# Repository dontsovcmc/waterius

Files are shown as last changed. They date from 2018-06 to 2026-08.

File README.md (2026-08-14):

# Ватериус 2.0.44
## Wi-Fi приставка для импульсных счётчиков воды, газа, тепла



waterius2-phone_

[Еnglish](https://github.com/dontsovcmc/waterius/blob/master/English.md)

✅ Протоколы HTTP, MQTT

✅ Поддержка <a href="https://yandex.ru/alice/smart-home" targe="_blank">Умного дома Яндекса</a>, <a href="https://www.home-assistant.io/" targe="_blank">HomeAssistant</a>,  <a href="https://www.hackster.io/dontsovcmc/domoticz-4346d5" targe="_blank">Domoticz</a>, <a href="https://spruthub.ru" targe="_blank">SprutHub</a> 

✅ Личный кабинет <a href="https://waterius.ru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" target="_blank">waterius.ru</a>

- автоматическая <a href="https://waterius.ru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" target="_blank">сдача показаний счётчиков</a> в 157 «водоканал» России и СНГ (на сентябрь 2025 г.).
- официальный партнер <a href="https://mos.ru" target="_blank">mos.ru</a>
- отправка на электронную почту
- отправка по СМС 
- телеграм бот

✅ Работает от 3-х батареек АА несколько лет

### Подходит к счётчикам
✅ Все счётчики воды с [импульсным выходом](https://github.com/dontsovcmc/waterius/issues/65) (провод торчит из корпуса)

✅ Все счётчики газа с герконом

✅ Электронные счётчики газа: Бетар СГБМ-4 [подробнее](https://github.com/dontsovcmc/waterius/issues/233)

✅ Электронные счётчики тепла: Sanext Monu CU, Берил ITELMA СТЭ 31 [подробнее](https://github.com/dontsovcmc/waterius/issues/233)

✅ Счётчики электричества: Энергомера CE101, Энергомера ЦЭ6803В 10-100А М7 Р31 и возможно другие импульсные

### Где купить

[waterius.ru](https://waterius.ru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)

### Характеристики
- подключение до двух счётчиков
- 3 АА батарейки (~2-4 года работы)
- передача по Wi-Fi
- не нужно знать, вес импульса у счётчика воды (Ватериус сам определит 1 или 10л/имп)
- не нужно знать, какого типа выход счётчика воды: "сухой контакт" или "НАМУР"
- настраиваемый период отправки
- ручная настройка веса импульса
- дискавери для Home Assistant (есть и интеграция в HAOS)
- возможно указать свои: веб сервер, MQTT брокер, сервер Blynk, NTP сервер
- поддержка SprutHub
- поддержка WirenBoard

#### Данные с Ватериуса можно увидеть:
* на сайте <a href="https://waterius.ru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">waterius.ru</a>
* в Приложении <a href="https://yandex.ru/alice/smart-home">Умный дом с Алисой от Яндекса</a>
* в HomeAssistant [инструкция с пояснениями](Home_Assistant_setup.md), [конфигурация](https://github.com/dontsovcmc/waterius/blob/master/homeassistant.configuration.yaml), [обсуждение](https://github.com/dontsovcmc/waterius/issues/86) или [интеграция](https://github.com/Anat0l/waterius-ha)
* в Domoticz [инструкция](https://www.hackster.io/dontsovcmc/domoticz-4346d5)
* в SprutHub [инструкция](https://wiki.spruthub.ru/%D0%A1%D0%BE%D0%B7%D0%B4%D0%B0%D0%BD%D0%B8%D0%B5_%D0%BA%D0%BE%D0%BD%D1%82%D1%80%D0%BE%D0%BB%D0%BB%D0%B5%D1%80%D0%B0_MQTT)
* на вашем [HTTP/HTTPS сервере](https://github.com/dontsovcmc/waterius/blob/master/Export.md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)
* в MQTT клиенте [описание полей и настройка](https://github.com/dontsovcmc/waterius/blob/master/Export.md#настройка-отправки-по-mqtt)
* там, куда сами запрограммируете
  * [httpwaterius](https://github.com/grffio/httpwaterius) - web сервер с простым UI от [grffio](https://github.com/grffio)
* передать сразу в управляющую компанию через сайт [waterius.ru](https://waterius.ru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).

## Подключение и настройка
[Текстом](http://waterius.ru/manual?utm_source=github)
[Видео](https://www.youtube.com/watch?v=dsmIdWbqJ58)

## Аналоги
[Заводские и DIY](https://github.com/dontsovcmc/waterius/issues/10)

## DIY Сделать самому
[Скачать прошивки](https://github.com/dontsovcmc/waterius/releases)

Народная инструкция в инфо Телеграм чата: [waterius_forum](https://t.me/waterius_forum)
- [Список деталей и создание платы](https://github.com/dontsovcmc/waterius/blob/master/Making.md)
- [Прошивка Attiny85 и ESP](https://github.com/dontsovcmc/waterius/blob/master/Firmware.md) 
- [Установка и настройка](https://github.com/dontsovcmc/waterius/blob/master/Setup.md) 

### Геркон для газового счётчика
Корпус для геркона под газовый счетчик BK-G4T [bk-g4t-sensor.zip](https://github.com/dontsovcmc/waterius/files/10365883/bk-g4t-sensor.zip)

## Принцип работы
Счётчик импульсов состоит из двух микросхем. Attiny85 считает импульсы в режиме сна и сохраняет их в EEPROM. Раз в сутки она будит ESP8266 и слушает i2c линию. ESP8266 спрашивает у Attiny85 данные и отправляет их на сервер. После этого ESP8266 засыпает, а Attiny85 продолжает считать-считать-считать...

### Известные ошибки
- Иногда не надёжно подключается к некоторым роутера Asus, Kineetic. Укажите в настройках Вай-фая ватериуса "only G". 
- До версии 0.11.8: Иногда не подключается к Ростелекомовским роутерам: Sercomm rv6699, Innbox e70, e80 (192.168.0.1), TP-Link AX5400. Лечится указанием статического ip в настройках. Если у вас такие, напишите в теме: [Проблемы с роутерами](https://github.com/dontsovcmc/waterius/issues/131)
- До версии 0.11.7 не подключается к Wi-Fi с пробелом в названии.

## Схема
Заводская плата:
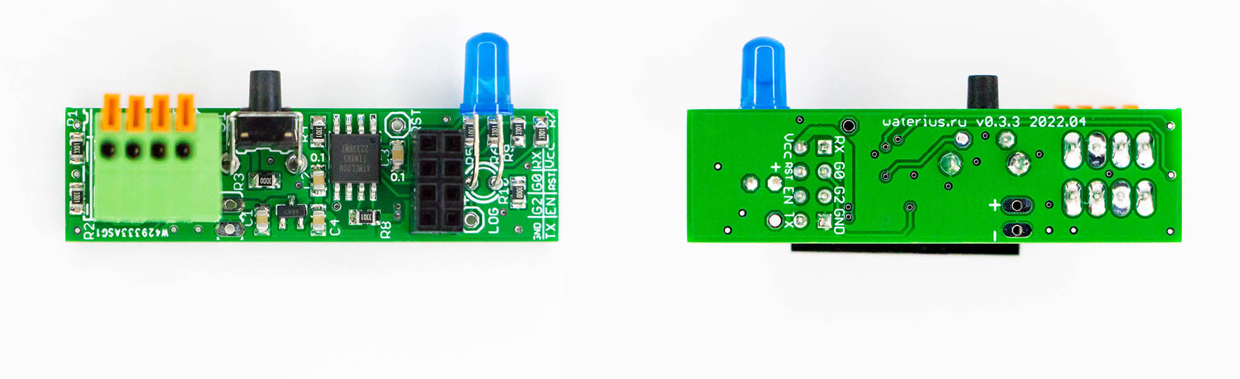
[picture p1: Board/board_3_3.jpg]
плата ватериуса


В репозитории ещё есть однослойная для ЛУТа.

## Разработка 
Ветка dev для pull-request
Ветка master только для публикации прошивок

Из актуальных задач остались сложные:
- Реализовать запись лога в файл (LittleFS), чтобы можно было скачать (/logs.html)
- OTA обновления: предложить код прошивки и пример веб-сервера (можно на базе NodeMCU)

### Модификации
[ветка attiny84](https://github.com/dontsovcmc/waterius/tree/attiny84) поддерживает плату [Waterius-Attiny84-ESP12F](https://github.com/badenbaden/Waterius-Attiny84-ESP12F) с 4мя счетчиками и 2мя датчиками протечек.

[Waterius на ESP32 с NB-IoT](https://github.com/OloloevReal/Waterius32) от OloloevReal

Датчик протечек:
- На пине reset сделал [OloloevReal](https://github.com/OloloevReal), вот [схема](https://github.com/dontsovcmc/waterius/issues/51)
- Есть в клоне [Waterius-Attiny84-ESP12F](https://github.com/badenbaden/Waterius-Attiny84-ESP12F), спасибо [badenbaden]

# Ответственность
Прошивка Ватериуса сделана на основе открытых библиотек, работоспособность которых никто не гарантирует. Я также не могу обещать, что устройство будет работать с вашем оборудованием и вы не получите ущерба как во время изготовления, так и во время эксплуатации устройства =). Пожалуйста, сообщите о любом опыте изготовления и использования [тут](https://github.com/dontsovcmc/waterius/issues). Вы поможете развитию проекта! 
[Лицензия GNU GPLv3](https://github.com/dontsovcmc/waterius/blob/master/LICENSE)

# Благодарности
- [marvel-m9y](https://github.com/marvel-m9y) за поддержку HTTPS
- [OloloevReal](https://github.com/OloloevReal) за датчик протечки, работу по ESP32
- [popsodav](https://github.com/popsodav) за MQTT
- Ивану Коваленко и Иван Ганжа за консультации по электротехнике
- Alex Jensen, за проект [температурного датчика](https://www.cron.dk/esp8266-on-batteries-for-years-part-1).
- [freenetwork](https://github.com/freenetwork) за конфигурацию для HomeAssistant
- [grffio](https://github.com/grffio) за локальный веб-сервер
- [Игорю Вахромееву](http://vakhromeev.com) за наикрутейший редизайн настроек
- Сергею А. (г. Мурманск) за подробную инструкцию по [настройке Domoticz и NodeRed](https://www.hackster.io/dontsovcmc/domoticz-4346d5)
- [sintech](https://github.com/sintech) за найденные и исправленные баги
- [zinger76](https://github.com/zinger76) за ссылку на заказ платы и [3D модель крепления](https://github.com/dontsovcmc/waterius/blob/master/wall-mount/wall_mount.md) к стене
- [badenbaden](https://github.com/badenbaden) за дельные комментарии по производству и новую версию!
- [kick2nick](https://github.com/kick2nick) за доработки функционала.
- [foxel](https://github.com/foxel) за доработку платы.
- Пользователям, приславшим очепятки и предложения: Дмитрию (г. Москва), Сергею (г. Кострома), Александру (г. Санкт-Петербург), Сергею (г. Мурманск), Антону (г. Красноярск) и др.
- Денису С. (г. Москва) за видео установки Ватериуса.
- [ivakorin](https://github.com/ivakorin) за инструкцию к Home Assistant
- Евгению К. из Самары, Олегу из Москвы за критику и помощь с прошивкой
- Олегу К. из Республики Беларусь за [инструкцию к MajorDoMo](https://mjdm.ru/forum/viewtopic.php?p=129000#p129000)
- [Drafteed](https://github.com/Drafteed) за виджет карты России
- [neitri](https://github.com/neitri) за доработки прошивки
- [L2jLiga](https://github.com/L2jLiga) за обновление конфигурации Home Assistant
- nyroux за корпус геркона для газового счётчика
- Anat0liyBM за поддержку discovery HA
- [vzagorovskiy](https://github.com/vzagorovskiy) за большое обновление [0.11.0](https://github.com/dontsovcmc/waterius/releases/tag/0.11.0-beta)
- [abrant-ru](https://github.com/abrant-ru) за поддержку счётчиков с выходом "открытый коллектор" (короткими импульсами)
- Даниилу Макарову за дизайн веб интерфейса
- [videlinagbm](https://github.com/videlinagbm) за верстку веб интерфейса и js код
- [Anat0l](https://github.com/Anat0l/waterius-ha) за написание интеграции в HA

Форумам: 
- https://electronix.ru
- https://esp8266.ru
- https://easyelectronics.ru

## Star History



## Контакты

Связь: [Facebook](https://www.facebook.com/waterius), [VK](https://vk.com/waterius1), [Instagram](https://www.instagram.com/waterius.ru/)

Задавайте вопросы в Телеграм чате: [waterius_forum](https://t.me/waterius_forum)

Найденные ошибки [в issues](https://github.com/dontsovcmc/waterius/issues)

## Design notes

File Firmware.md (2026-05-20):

# Quickstart

Как можно прошить ATtiny & ESP:
1. Взять готовые hex/bin файлы и залить их
2. Скомпилировать исходный код в PlatformIO (CLI или Visual Studio Code)
3. Скомпилировать исходный код в Arduino IDE

---

# Подготовка среды для прошивки (Windows 11)

Для работы вам необходимо подготовить программное обеспечение и установить драйверы для используемых программаторов.

### Установка инструментов через терминал

Запустите **PowerShell** от имени администратора и выполните команды ниже.

#### Одной строкой (все сразу):
```powershell
winget install AVRDudes.AVRDUDE Akeo.Zadig astral-sh.uv Python.Python.3.14; uv tool install esptool
```

#### По отдельности с пояснениями:

*   **AVRDUDE** — утилита для работы с USBasp и контроллерами AVR:
    ```powershell
    winget install AVRDudes.AVRDUDE
    ```
*   **Zadig** — инсталлятор универсальных драйверов для USBasp:
    ```powershell
    winget install Akeo.Zadig
    ```
*   **uv** — быстрый менеджер пакетов для Python:
    ```powershell
    winget install astral-sh.uv
    ```
*   **Python 3.14** — необходимая среда исполнения:
    ```powershell
    winget install Python.Python.3.14
    ```
*   **esptool** — прошивальщик для чипов ESP32 / ESP8266:
    ```powershell
    uv tool install esptool
    ```

---

### 🔌 Установка драйверов (ручной этап)

#### 1. Драйвер для USBasp
После установки **Zadig** через терминал:
1. Подключите **USBasp** к компьютеру.
2. Запустите Zadig.
3. Выберите `Options` → `List All Devices`.
4. В списке выберите `USBasp`.
5. Установите тип драйвера: `libusb-win32`.
6. Нажмите **Replace Driver**.

#### 2. Драйвер для CH340 (USB-Serial)
Для работы с COM-портом скачайте и запустите официальный установщик:
*   🔗 **[Скачать драйвер CH340](https://www.wch-ic.com/download/file?id=270)**

---

### Проверка готовности
*   Для проверки **USBasp** введите: `avrdude -c usbasp -p m328p`
*   Для проверки **CH340** проверьте наличие порта в: `Диспетчер устройств → Порты (COM и LPT)`

---

# Оборудование и схемы подключения

## Чем прошить

#### ATtiny85:
- Программатором USBasp
- Платой Arduino, загрузив в неё скетч Arduino-as-ISP
- Другим программатором для AVR (например, USB-ISP)

#### ESP8266:
- USB-TTL 3.3V переходником
- Платой Arduino, подключившись к её RX, TX + делитель до 3.3V

---

## Фьюзы ATtiny85
**Значения:** `E:FF`, `H:DF`, `L:62`

---

## Распиновка для прошивки ATtiny через разъем ESP

Прошивка ATtiny осуществляется без выпайки её с платы через разъем для ESP (тип разъема: PBD-8).  
**Вид сверху:**

| **GND** | **SCK (15)** | **MOSI (16)** | NC  | 
| ---- | ---- | ---- | ---- |
| NC | **MISO (14)** | NC  | **VCC** |

+ 10-й пин на RESET ATtiny85

**Примечания:**
- **NC** — не используется
- **VCC** — подключить к любому 3.3V или 5V
- От программатора отдельными проводами необходимо подключиться в отверстия PBD-8
- ⚠️ **Не забыть:** отдельно подключить провод к пину RESET

---

## Программаторы для ATtiny

### Утилита Avrdude
- Официальный репозиторий: https://github.com/avrdudes/avrdude
- Альтернативная ссылка: http://www.avislab.com/blog/wp-content/uploads/2012/12/avrdude.zip

### Arduino в качестве ISP программатора (3.3V–5V)

1. Залейте скетч ISP программатора с помощью Arduino IDE в плату Arduino [[инструкция](http://www.martyncurrey.com/arduino-nano-as-an-isp-programmer/)]
2. Подключите плату Arduino к Вотериусу:

**Распиновка при прошивке с помощью Arduino Micro или Arduino UNO:**

| Micro | UNO/NANO | ISP | ATtiny85 | 
| ---- | ---- | ---- | ---- |
| 15 pin | 13 pin | SCK | 7 pin |
| 14 pin | 12 pin | MISO | 6 pin |
| 16 pin | 11 pin | MOSI | 5 pin |
| 10 pin | 10 pin | RESET | 1 pin |

+ Питание!

**Настройки в `platformio.ini`:**
```ini
upload_protocol = arduino
upload_flags = -P$UPLOAD_PORT
upload_speed = 19200
```

### Китайский USB-ISP программатор
- Плата: MX-USBISP-V5.00
- Программа: [ProgISP V1.7.2](https://yandex.ru/search/?text=ProgISP%20V1.7.2&&lr=213)
- Фьюзы: `E:FF`, `H:DF`, `L:62`

### USBasp программатор
Я купил китайский USB-ISP и перепрошил его по [инструкции](https://vochupin.blogspot.com/2016/12/usb-isp.html) в USBasp ([прошивка](https://www.fischl.de/usbasp/)). В диспетчере устройств он стал виден как USBasp.

- Драйвер: [v3.0.7](http://www.myrobot.ru/downloads/programs/usbasp-win-driver-x86-x64-v3.0.7.zip)

**Настройки в `platformio.ini`:**
```ini
upload_protocol = usbasp
upload_flags = 
    -Pusb 
    -B5
```

**Примечание:** в Windows 7 почему-то не заработал. Windows 10 x64 — OK.

---

## Программаторы для ESP8266

Для прошивки ESP8266 необходим USB-TTL преобразователь с логическим уровнем 3.3V. Обратите внимание, что у него должен быть регулятор напряжения для питания ESP8266 на 3.3V. У обычных USB-TTL преобразователей логический уровень 5V, поэтому их вывод TX нужно подключить к делителю напряжения. Я использую резисторы 1.5к и 2.2к.

[Инструкция из интернета](http://cordobo.com/2300-flash-esp8266-01-with-arduino-uno)  
(в большинстве других туториалах подключают 5V логику и делают ESP больно)

#### Драйверы для USB-TTL:
- [CH340G](https://all-arduino.ru/drajver-ch340g-dlya-arduino/)
- [PL2303](http://www.prolific.com.tw/US/ShowProduct.aspx?p_id=225&pcid=41)

---

# Прошивка готовыми бинарными файлами

Готовые прошивки доступны [на странице releases](https://github.com/dontsovcmc/waterius/releases).

## Прошивка ATtiny85 с помощью Avrdude & USBasp

1. **Установка Avrdude:**
   - Скачать: http://download.savannah.gnu.org/releases/avrdude/avrdude-6.2-mingw32.zip
   - **Для Windows 11:** открыть командную строку или PowerShell и выполнить:
     ```powershell
     winget install AVRDudes.AVRDUDE
     ```

2. Распакуйте архив, зайдите в папку. Откройте консоль: `Shift` + правая кнопка мыши → **Открыть окно команд**.

3. Скачайте прошивку ATtiny85:
   ```bash
   curl https://raw.githubusercontent.com/dontsovcmc/waterius_firmware/master/0.5/attiny85.hex --output ./attiny85.hex
   ```
   Если нет `curl`, то откройте ссылку в браузере и скопируйте файл в папку Avrdude.

4. Установите драйвер программатора [USBasp](http://www.myrobot.ru/downloads/driver-usbasp-v-2.0-usb-isp-windows-7-8-10-xp.php) и подключите его к ATtiny85.

5. Установите фьюзы:
   ```bash
   avrdude.exe -p t85 -c Usbasp -B 4 -P usb -U efuse:w:0xFF:m -U hfuse:w:0xDF:m -U lfuse:w:0x62:m
   ```

6. Прошейте микроконтроллер:
   ```bash
   avrdude.exe -p t85 -c Usbasp -B 4 -P usb -U flash:w:"D:\firmware.hex":a
   ```
   где `D:\firmware.hex` — путь до вашего файла.

---

## Прошивка ESP8266

Программатор не нужен, а нужен переходник с USB на TTL 3.3V.

1. Установите Python 3.8 (2.7 тоже подойдёт, только пути для PATH другие).
   
   **Windows:** добавьте в PATH:
   ```
   C:\Users\Админ\AppData\Local\Programs\Python\Python38-32
   ```

2. Скачайте pip. Выполните `python get-pip.py` — Python установит утилиту pip.
   
   Добавьте в PATH:
   ```
   C:\Users\Админ\AppData\Local\Programs\Python\Python38-32\Scripts
   ```

3. Установите esptool:
   ```bash
   pip install esptool
   ```

4. Скачайте [прошивку ESP8266](https://github.com/dontsovcmc/waterius/releases) (файл `esp8266.bin`).

5. Подключите USB-TTL к ESP8266, замкнув **GPIO0** на **GND**.

6. Выполните прошивку:
   ```bash
   python -m esptool --port COM7 --baud 115200 write_flash --flash_freq 40m --flash_size 1MB --flash_mode qio 0x0 esp8266-1.0.2.bin 0xbb000 esp8266-1.0.2-fs.bin
   ```
   
   **COM7** замените на свой порт.

<details>
 <summary>output log (esptool 2.5.0)</summary>

```
esptool.py v2.5.0
Serial port COM7
Connecting........_____.....____
Detecting chip type... ESP8266
Chip is ESP8266EX
Features: WiFi
MAC: 68:c6:3a:a4:75:b0
Uploading stub...
Running stub...
Stub running...
Configuring flash size...
Flash params set to 0x0220
Compressed 359840 bytes to 253754...
Wrote 359840 bytes (253754 compressed) at 0x00000000 in 23.1 seconds (effective 124.8 kbit/s)...
Hash of data verified.

Leaving...
Verifying just-written flash...
(This option is deprecated, flash contents are now always read back after flashing.)
Flash params set to 0x0220
Verifying 0x57da0 (359840) bytes @ 0x00000000 in flash against esp.bin...
-- verify OK (digest matched)
Hard resetting via RTS pin...
```
</details>

Очистить конфигурацию можно вместе с памятью:
```bash
python -m esptool --chip esp8266 --port COM3 --after no_reset erase_flash
```

---

# Прошивка через PlatformIO

### Установка PlatformIO

PlatformIO бывает в виде консольной утилиты или как дополнение в Visual Studio Code.

- [Инструкция по установке утилиты](http://docs.platformio.org/en/latest/installation.html#python-package-manager)
- [Инструкция из интернета](https://medium.com/jungletronics/attiny85-easy-flashing-through-arduino-b5f896c48189)

У нас ATtiny85 уже сидит на плате, поэтому подключаемся к разъему.

После установки в командной строке можно вызывать `platformio --version` и увидеть версию PlatformIO.

### Прошивка ATtiny

1. Откройте в командной строке папку `waterius/Attiny85`
2. Измените в файле `platformio.ini` порт на свой:
   ```ini
   upload_port = /dev/tty.usbmodem1421
   ```
3. Выполните:
   ```bash
   platformio run --target upload
   ```

### Прошивка ESP8266

1. Откройте в командной строке папку `waterius/ESP8266`
2. Измените в файле `platformio.ini` порт на свой:
   ```ini
   upload_port = /dev/tty.usbmodem1411
   ```
3. Прошейте сначала файл прошивки:
   ```bash
   platformio run --target upload --environment esp01_1m
   ```
4. Затем прошейте файловую систему:
   ```bash
   platformio run --target uploadfs --environment esp01_1m
   ```

---

# Прошивка с помощью Arduino IDE

## ATtiny

1. Установить [поддержку ATtiny плат](https://github.com/SpenceKonde/ATTinyCore/blob/master/Installation.md)
2. Выбрать **1 MHz internal**
3. В `/attiny/src` переименовать `main.cpp` в `src.ino`
4. Открыть `src.ino` в Arduino IDE
5. Компилировать

## ESP8266

### Требуемые библиотеки

* Blynk by Volodymyr Shymanskyy (0.6.1)
* ArduinoJSON (6.12.0)
* PubSubClient (2.7.0)
* Установить вручную из zip [WiFiManager#waterius_release_101](https://github.com/dontsovcmc/WiFiManager/tree/waterius_release_101)

**Примечание:** актуальные версии в [platformio.ini](https://github.com/dontsovcmc/waterius/blob/master/ESP8266/platformio.ini)

### Настройка Arduino IDE для ESP8266

**Additional Boards Managers URLs:**
```
http://arduino.esp8266.com/stable/package_esp8266com_index.json
```

**Board settings:**
* **Board:** Generic ESP8266 Module
* **Flash Mode:** QIO
* **Flash Size:** 1M (no SPIFFS)
* **Debug port:** Disable
* **Debug Level:** None
* **lwIP Variant:** v2 Lower Memory
* **Reset Method:** ck
* **Crystal Frequency:** 26 MHz
* **Flash Frequency:** 40MHz
* **CPU Frequency:** 80 MHz
* **Built-in Led:** 0
* **Upload Speed:** 115200
* **Port:** select your port

---

# FAQ

<details>
<summary>1. Лог прошитой ESP без подключения к ватериусу</summary>

```
pio device monitor --port /dev/cu.wchusbserial1410 --baud 115200
--- Miniterm on /dev/cu.wchusbserial1410  115200,8,N,1 ---
--- Quit: Ctrl+C | Menu: Ctrl+T | Help: Ctrl+T followed by Ctrl+H ---
;l␀d|␀$|␃␄␌␄␌$␄c|ǃ␂␛{c␄co'lno␌b␜x$c␇l{lxn␘␃␌␌␌d␌␌␄␌c␄g|␃l␌␄c'o␀$l`␃␛␓no␄$`␃␏␃'{o␄␄c␄␏l␇s'␄␌c␌␇d␃␃$l␒$`␃'␂000:00:00:00:396  NOTICE    (ESP) : Booted
000:00:00:00:397  ERROR     (I2C) : end error:2
000:00:00:00:397  ERROR     (I2C) : get mode failed. Check i2c line.
000:00:00:00:400  NOTICE    (ESP) : Going to sleep
000:00:00:00:404  ERROR     (I2C) : end error:2
```

ЕSP включается, запрашивает режим включения у ATtiny, нет ответа, идёт спать.
</details>

<details>
<summary>2. Проверка без ESP, что ATtiny прошилась</summary>

- Замыкаете на разъеме ESP выводы TX и EN.
- Жмёте кнопку 1 сек, отпускаете
- Проверяете, что загорелся светодиод — ATtiny прошита корректно
</details>

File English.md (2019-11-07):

### Get water meter data sent to your mobile phone using Wi-Fi (powered by AA batteries). 

# Waterius 

Full article on [Hackster.io](https://www.hackster.io/dontsovcmc/waterius-4bfaba)

### Waterius can sends:
- current values everyday
- delta values (per day)
- voltage
- e-mail by Blynk (title and message template)
- data to your TCP server
- low voltage detector (experimental)

Values saved in ATtiny EEPROM cycle buffer (~2 millions cycles). "Software ESD protection".

### How It Works
*Two chips*: ATtiny85 in deep sleep mode. It counts impulses and wakes up ESP-01 to transfer data to Blynk every day. Chips talks by i2c line.

*Power*: 3*AA batteries (or 2*AA lithium batteries without voltage regulator)

*Current*: 15-24 uA in deep sleep, 75 mA when transmitting for ~5 sec

*Lifetime*: estimated 4 year battery life

*Limits*: 1 impulse per second (increased by constant in code)

*Inputs*: 2 water meters

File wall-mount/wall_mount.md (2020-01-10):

# Вариант крепления ватериуса к стене
Модель для 3D печати [STL](https://github.com/dontsovcmc/waterius/blob/master/wall-mount/waterius-wall-mount-v31_.stl), файл 
[SolidWorks SLDPRT](https://github.com/dontsovcmc/waterius/blob/master/wall-mount/waterius-wall-mount-v31.SLDPRT)

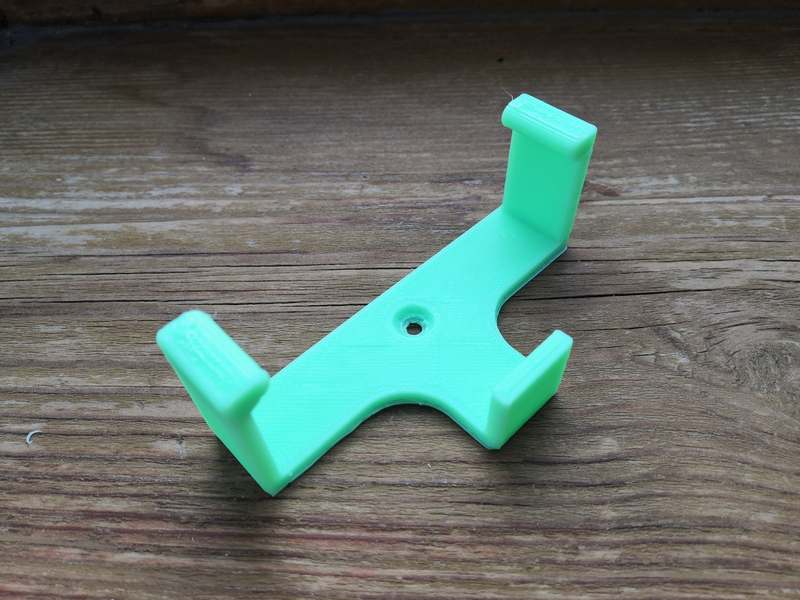
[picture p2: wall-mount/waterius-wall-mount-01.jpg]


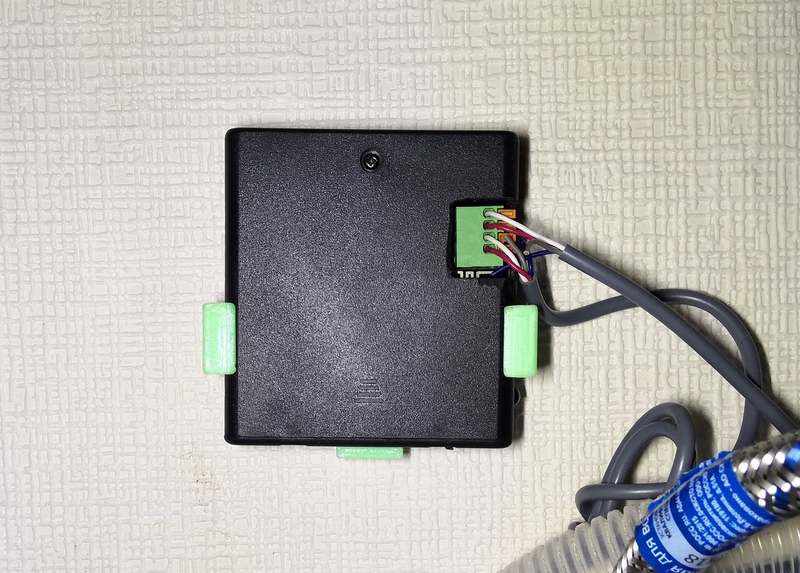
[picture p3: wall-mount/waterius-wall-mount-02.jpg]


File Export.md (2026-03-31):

Ватериус поддерживает отправку в
- сайт <a href="https://waterius.ru" target="_blank">waterius.ru</a>
- в Home Assistant по MQTT
- в WirenBoard по MQTT
- MQTT
- HTTP

Отправка в MQTT и HTTP происходит при каждом пробуждении устройства.

# Список параметров
В таблице собрана информация об отправляемых данных. В столбцах HTTP, MQTT указано, отправляются ли данные по соответствующему протоколу.

Вход 0 - Синий
Вход 1 - Красный

| Поле | Размерность | Тип | Описание | HTTP | MQTT | С версии | 
| --- | --- | --- | --- | --- | --- | --- |
| adc0 | - | uint | Аналоговый уровень входа 0 | + | + | - |
| adc1 | - | uint | Аналоговый уровень входа 1 | + | + | - |
| boot | - | uint | Причина загрузки attiny85 | + | + | - |
| battery | - | int | % заряда батарейки (фейковый) | + | + | - |
| ch0 | м3 | float | Показания воды, вход 0 | + | + | - |
| ch1 | м3 | float | Показания воды, вход 1 | + | + | - |
| ch0_start | м3 | float | Начальные показания воды, вход 0 | + | + | - |
| ch1_start | м3 | float | Начальные показания воды, вход 1 | + | + | - |
| channel | - | int | Канал wi-fi роутера | + | + | - |
| cname0 | - | uint | Тип счётчика, вход 0 | + | + | - |
| cname1 | - | uint | Тип счётчика, вход 1 | + | + | - |
| ctype0 | - | uint | Тип входа attiny, вход 0 | + | + | - |
| ctype1 | - | uint | Тип входа attiny, вход 1 | + | + | - |
| data_type0 | - | uint | Тип данных, вход 0 | + | + | - |
| data_type1 | - | uint | Тип данных, вход 1 | + | + | - |
| dhcp | - | bool | DHCP включен | + | + | - |
| delta0 | литр | uint | Разница с предыдущими показаниями, вход 0 (гор. вода) | + | + | - | 
| delta1 | литр | uint | Разница с предыдущими показаниями, вход 1 (хол. вода) | + | + | - | 
| email | - | str | Электронная почта | + | + | - |
| esp_id | - | int | Серийный номер ESP | + | + | - |
| f0 | - | uint | Вес импульса, вход 0 | + | + | - |
| f1 | - | uint | Вес импульса, вход 1 | + | + | - |
| flash_id | - | int | ID флеш-чипа ESP | + | + | - |
| freemem | - | int | свободная память в ESP, байт | + | + | - |
| imp0 | шт | uint | Количество импульсов | + | + | V0 | 
| imp1 | шт | uint | Количество импульсов | + | + | V1 | 
| ip | - | str | ip адрес локальный ESP (Х.Х.Х.Х) | + | + | - |
| ha | - | bool | флаг HA дискавери включен | + | + | - |
| http | - | bool | HTTP отправка включена | + | + | - |
| key | - | str | Уникальный токен | + | - | - |
| mac | - | str | MAC адрес ESP (ХХ:ХХ:ХХ:ХХ:ХХ:ХХ) | + | + | - |
| mode | - | int | Режим пробуждения 2-авто, 3-по кнопке | + | + | - |
| model | - | uint | Модель устройства (0-Classic, 2-Waterius 2) | + | + | - |
| mqtt | - | bool | брокер mqtt заполнен | + | + | - |
| mqtt_retain | - | bool | MQTT retain включен | + | + | - |
| ntp_errors | шт | uint | Ошибки синхронизации времени NTP | + | + | - |
| ota_error | - | int | Код ошибки OTA обновления (0-4) | + | + | - |
| period_min | минуты | uint | Период пробуждения | + | + | - |
| period_min_tuned | минуты | float | Скорректированный период пробуждения | + | + | - |
| resets | шт | uint | Количество перезагрузок | + | + | V5 |
| router_mac | - | str | MAC адрес производителя роутера (ХХ:ХХ:ХХ:00:00:00) | + | + | - |
| rssi | dBm | int | Уровень Wi-Fi сигнала | + | + | V8 |
| setup_finished | - | int | число успешных подключений к роутеру после настройки | + | + | - |
| setup_started | - | int | число включений режима настройки | + | + | - |
| setuptime | мсек | int | Длительность режима настройки | + | + | - |
| serial0 | - | str | Серийный номер, вход 0 | + | + | - |
| serial1 | - | str | Серийный номер, вход 1 | + | + | - |
| timestamp | - | str | Текущая дата и время 2019-11-29T23:29:55+0800 | + | + | - |
| version | - | int | Версия прошивки attiny85 | + | + | - |
| version_esp | - | str | Версия прошивки esp | + | + | - |
| voltage | В | float | Напряжение питания attiny85 | + | + | - |
| voltage_diff | мВ | int | Просадка напряжения за время подключения Wi-Fi | + | + | - |
| voltage_calibration | % | uint8 | Калибровка напряжения, только Waterius 2 (по умолчанию 100) | + | + | - |
| voltage_low | 0 или 1 | int | voltage_diff выше 50мВ  | + | + | - |
| waketime | мсек | int | Время работы ESP при предыдущем включении | + | + | - |
| wifi_phy_mode | - | str | Текущий режим Wi-Fi | + | + | - |
| wifi_phy_mode_s | - | str | Режим Wi-Fi из настроек | + | + | - |
| wifi_connect_attempt | шт | uint | Попытки подключения к WiFi | + | + | - |
| wifi_connect_errors | шт | uint | Ошибки подключения к WiFi | + | + | - |
| company | - | str(20) | ИНН организации-установщика | + | + | 1.1.5 |
| place | - | str(20) | Место установки | + | + | 1.1.5 |

#### cnameX
| Тип счетчика | Описание |
| --- | --- |
| 0 | Холодная вода |
| 1 | Горячая вода |
| 2 | Электричество |
| 3 | Газ |
| 4 | Тепло |
| 5 | Питьевая вода |
| 6 | Другой |

#### data_typeX
| Тип данных | Описание |
| --- | --- |
| 0 | Холодная вода |
| 1 | Горячая вода |
| 2 | Электричество |
| 3 | Газ |
| 4 | Тепло |
| 9 | Питьевая вода |
| 10 | Другой |

#### ctypeX
| Тип чтения | Описание | Описание |
| --- | --- | --- |
| 0 | Намур | Для механических счетчиков |
| 1 | Дискретный | Для механических счетчиков (убрал) |
| 2 | Электронный | Для электронных счетчиков |

# Настройка отправки на сайт waterius.ru
Зарегистрируйтесь на сайте waterius.ru по адресу электронной почты.
Заполните в режиме настройки:
| Поле | Описание | Пример | Обязательно |
| --- | --- | --- | --- |
| Электронная почта с сайта waterius.ru | Указанная при регистрации почта | user@mail.ru | + |

Ватериус появится в личном кабинете при отправке показаний.

# Настройка отправки в Home Assistant по MQTT 

Заполненное поле "Адрес сервера" включает отправку по протоколу MQTT.
Для подключения нескольких ватериусов укажите им разные топики.
Обязательно включить параметр "retained" на брокере. 
Данные отправляются с retain=true

С версии 0.11.0: По умолчанию данные прилетят в виде JSON (при включенном параметре discovery) в топик. (Например: "waterius/12380568/")

```
{"delta0":0,"delta1":0,"ch0":338.304,"ch1":535.966,"imp0":79,"imp1":109,"f0":10,"f1":10,"adc0":113,"adc1":114,"serial0":"","serial1":"","ctype0":0,"ctype1":0,"cname0":1,"cname1":0,"data_type0":1,"data_type1":0,"voltage":3.128,"voltage_low":true,"voltage_diff":0.21,"battery":0,"channel":12,"router_mac":"AA:AA:AA:00:00:00","rssi":-70,"mac":"AA:AA:AA:AA:AA:AA","ip":"172.16.64.50","dhcp":true,"version":31,"version_esp":"0.11.9","model":0,"esp_id":8686250,"flash_id":1458400,"freemem":37504,"timestamp":"2023-10-22T17:01:10+0000","waketime":10829,"period_min":1440,"period_min_tuned":1440,"setuptime":91781,"boot":1,"resets":1,"mode":3,"setup_finished":4,"setup_started":5,"ntp_errors":0,"wifi_connect_errors":0,"wifi_connect_attempt":1,"ota_error":0,"key":"AA","email":"AA@ya.ru","mqtt":true,"http":false,"ha":false,"mqtt_retain":true}
```
Если параметр discovery выключен или версия прошивки <0.11.0, то данные отправятся в виде отдельных топиков:
```
waterius/12380568/version_esp 0.10.0
waterius/12380568/version 13
waterius/12380568/ch0 0.100
waterius/12380568/ch1 11.200
waterius/12380568/f0 10
waterius/12380568/resets 7
waterius/12380568/rssi -69
и т.д.
```

Заполните в режиме настройки:
| Поле | Описание | Пример | Обязательно |
| --- | --- | --- | --- |
| Адрес сервера | ip адрес брокера или домен | 192.168.1.10, broker.hivemq.com | + |
| Порт | порт брокера | 1883 | + |
| Логин | логин для авторизированного доступа | username | - |
| Пароль | пароль для авторизированного доступа | secret | - |
| Топик | топик по которому будут отсылаться данные | waterius/123456/ | + |
| discovery | обязателен, чтобы работал discovery  | - | + |
| Топик для discovery | топик по которому будут отсылаться данные | homeassistant | + |

С версии 0.11.0 доступно менять параметр period_min, c 0.11.9 и некоторые другие.

| параметр | топик для записи | тип данных | пример топика | пример данных | версия |
|---|---|---|---|---|---|
| period_min | <топик из настроек>/period_min/set | целое число | waterius/124121251/period_min/set | 60 | >=0.11.0  |
| f0 | <топик из настроек>/f0/set | целое число | waterius/124121251/f0/set | 10 | >=0.11.9  |
| f1 | <топик из настроек>/f1/set | целое число | waterius/124121251/f1/set | 10 | >=0.11.9  |
| ch0 | <топик из настроек>/ch0/set | дробное число | waterius/124121251/ch0/set | 121.4 | >=0.11.9  |
| ch1 | <топик из настроек>/ch1/set | дробное число | waterius/124121251/ch1/set | 151.53 | >=0.11.9  |
| cname0 | <топик из настроек>/cname0/set | целое число | waterius/124121251/cname0/set | 0 | >=1.0.2 |
| cname1 | <топик из настроек>/cname1/set | целое число | waterius/124121251/cname1/set | 0 | >=1.0.2 |
| ctype0 | <топик из настроек>/ctype0/set | целое число | waterius/124121251/ctype0/set | 0 | >=1.0.2 |
| ctype1 | <топик из настроек>/ctype1/set | целое число | waterius/124121251/ctype1/set | 0 | >=1.0.2 |
| voltage_calibration | <топик из настроек>/voltage_calibration/set | целое число (только Waterius 2) | waterius/124121251/voltage_calibration/set | 100 | >=2.0.34 |

Примечание: значения ctype0, ctype1 указано выше в разделе ctypeX
Примечание: значения cname0, cname1 указано выше в разделе cnameX

# Настройка отправки в WirenBoard по MQTT 

Выполните настройки MQTT как для отправки в Home Assistant.

Загрузите скрипт waterius_wirenboard.js
 в WirenBoard и измените в нём topic.

# Настройка отправки по HTTP (свой сервер)

Заполните в режиме настройки:
| Поле | Описание | Пример | Обязательно |
| --- | --- | --- | --- |
| Адрес сервера | ip адрес сервера или домен (```http[s]://host[:port][/path]```) | 192.168.1.10, http://mysite.ru, http://mysite.ru:1000/data | + |

Если "Адрес сервера" пустой, отправка по HTTP выключена.

Ватериус отправляет POST запрос с данными в виде JSON.

<a href="https://github.com/dontsovcmc/waterius/wiki/%D0%9F%D1%80%D0%B8%D0%BC%D0%B5%D1%80-%D0%B2%D0%B5%D0%B1%D1%81%D0%B5%D1%80%D0%B2%D0%B5%D1%80%D0%B0">Пример вебсервера</a>

## Поддержка HTTPS 

Добавлена библиотека BearSSL с поддержкой TLS 1.2 шифрования.
Если ваш сервер https, то требуется пересобрать прошивку с вашим сертификатом удостоверящего центра. Инструкция по созданию сертификатов в [Python скрипте]. У сертификатов есть срок действия.

# Проекты сообщества
* [httpwaterius](https://github.com/grffio/httpwaterius) - web сервер с простым UI от [grffio](https://github.com/grffio)

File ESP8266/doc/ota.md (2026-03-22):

# OTA обновление прошивки Waterius

OTA (Over-The-Air) позволяет обновлять прошивку и файловую систему Waterius удалённо, без физического подключения по USB.

**Поддерживаемые модели:** только Waterius-2 (MODEL_2, ESP-12F, flash 4MB).
ESP-01 (1MB flash) не поддерживает OTA — недостаточно места для staging area.

## Общая схема работы

```
ESP ──POST данные──> Сервер
ESP <──JSON ответ─── Сервер  (содержит секцию "ota" с url/md5/size файлов)
ESP ──GET──────────> filesystem.bin  (LittleFS, если есть в ota)
ESP ──GET──────────> firmware.bin
ESP ──перезагрузка──> Новая прошивка работает
```

Сервер решает, кому и когда отдавать OTA — ESP просто выполняет команду. Отдельного манифеста нет — OTA-данные передаются прямо в JSON-ответе сервера, что экономит один HTTP-запрос и ~15 КБ RAM.

## Последовательность работы

### 1. Штатный цикл отправки данных

ESP просыпается (по таймеру или кнопке), подключается к WiFi и отправляет показания на сервер. В JSON-запросе всегда есть поле `version_esp` с текущей версией прошивки.

### 2. Сервер отвечает с командой OTA

Если сервер решает что устройству нужно обновление, он включает в ответ секцию `ota`:

```json
{
  "ota": {
    "firmware": {
      "url": "https://cloud.waterius.ru/ota/nodemcuv2-2.0.25.bin",
      "size": 633344,
      "md5": "f14e1220b1565f63a4a69b84cab4582d"
    },
    "filesystem": {
      "url": "https://cloud.waterius.ru/ota/nodemcuv2-2.0.25-fs.bin",
      "size": 1024000,
      "md5": "6c023b5558cc375843449565ff0f2570"
    }
  }
}
```

Если обновление не нужно — пустой ответ `{}`.

Секция `ota` должна содержать хотя бы одну из подсекций (`firmware` или `filesystem`). Каждая подсекция содержит:

| Поле | Описание |
|---|---|
| `url` | Полный HTTPS URL файла |
| `size` | Размер в байтах |
| `md5` | MD5-хеш файла |

### 3. Проверки перед обновлением

**Проверка батареи (3 замера, среднее):**

Перед OTA выполняются 3 измерения напряжения с интервалом 100мс. Пауза между замерами позволяет напряжению стабилизироваться после кратковременных просадок от WiFi-передачи. Среднее из 3 замеров сглаживает шум АЦП ESP8266 (±30-50 мВ).

| Проверка | Порог | Назначение |
|---|---|---|
| Среднее > 4600 мВ | — | USB-питание, проверка пропускается |
| Среднее < 3300 мВ | Абсолютный порог | Минимум для 3×AA (3 × 1.1В) |

Порог 3300 мВ — надёжный минимум для любых типов батарей (Alkaline, NiMH) и АКБ.

**Порог USB-питания — 4600 мВ** (не 4900). Под нагрузкой WiFi напряжение USB проседает до ~4830 мВ. Свежие 3xAA дают до ~4800 мВ, но при WiFi нагрузке падают до ~4700 мВ, что всё ещё > 4600.

**Валидация OTA-данных:**
- Секция `ota` должна быть JSON-объектом
- Должна содержать хотя бы одну подсекцию (`firmware` или `filesystem`)
- Каждая подсекция должна содержать `url` и `md5`

**Проверка MD5:**
- `ESP8266httpUpdate` проверяет MD5 после скачивания, до записи во flash
- Если MD5 не совпадает — файл отбрасывается, старая прошивка не тронута

### 4. Обновление файловой системы

Если в `ota` есть секция `filesystem`:
- Вызывается `extendWakeUp()` — сброс таймера Attiny85 (120 секунд)
- `ESPhttpUpdate.updateFS()` скачивает и записывает LittleFS-образ
- Перезагрузка отключена (`rebootOnUpdate(false)`) — после FS нужно ещё обновить firmware

### 5. Обновление прошивки

Если в `ota` есть секция `firmware`:
- Вызывается `extendWakeUp()`
- `ESPhttpUpdate.update()` скачивает прошивку в staging area
- Перезагрузка отключена — после записи выполняется явная проверка результата

### 6. Перезагрузка и проверка

После успешного обновления всех компонентов:
```
OTA: filesystem updated OK
OTA: firmware updated OK
OTA: complete, restarting ESP...
```
ESP вызывает `ESP.restart()`. Bootloader (eboot) копирует прошивку из staging area в APP-область (~3.8 секунды для 633 КБ).

После перезагрузки ESP проходит обычный цикл: WiFi → NTP → отправка данных. В JSON уже новая `version_esp`. Сервер видит новую версию и отвечает `{}` — OTA больше не запускается. Если OTA завершилось ошибкой, статус ошибки (`ota_error`) передастся серверу при следующем штатном пробуждении.

## Коды ошибок OTA

Код ошибки сохраняется в `Settings.ota_error` (EEPROM). При следующей отправке данных включается в JSON как `ota_error`. После успешной отправки обнуляется.

| Код | Константа | Описание |
|-----|---|---|
| 0 | `OTA_ERR_NONE` | Нет ошибки |
| 1 | `OTA_ERR_PARSE` | Ошибка данных (нет url/md5, пустая секция ota) |
| 2 | `OTA_ERR_FS_UPDATE` | Ошибка обновления filesystem (MD5, обрыв, нет связи и т.д.) |
| 3 | `OTA_ERR_FW_UPDATE` | Ошибка обновления firmware (MD5, обрыв, нет связи и т.д.) |
| 4 | `OTA_ERR_LOW_BATTERY` | Батарея разряжена (напряжение < 3300 мВ) |

Счётчик попыток OTA реализуется на стороне сервера: сервер видит `ota_error` и `version_esp` в каждом запросе и может прекратить отдавать OTA после N ошибок.

## Настройка сервера

### Python Flask (пример)

Минимальный сервер для управления раздачей OTA:

```python
from flask import Flask, request, jsonify

app = Flask(__name__)

OTA_ENABLED = True
OTA_TARGET_VERSION = "2.0.24"  # OTA только для этой версии ("" = для всех)
OTA_CONFIG = {
    "firmware": {
        "url": "https://cloud.waterius.ru/ota/nodemcuv2-2.0.25.bin",
        "size": 637200,
        "md5": "b66e9d1297bc1a170d140aeddc3e15b8"
    },
    "filesystem": {
        "url": "https://cloud.waterius.ru/ota/nodemcuv2-2.0.25-fs.bin",
        "size": 1024000,
        "md5": "6c023b5558cc375843449565ff0f2570"
    }
}

@app.route("/cloud-waterius-ru", methods=["POST"])
def waterius():
    data = request.get_json(silent=True) or {}
    version_esp = data.get("version_esp", "")

    response = {}
    if OTA_ENABLED:
        if OTA_TARGET_VERSION == "" or version_esp == OTA_TARGET_VERSION:
            response["ota"] = OTA_CONFIG

    return jsonify(response)
```

**Параметры:**

| Параметр | Описание |
|---|---|
| `OTA_ENABLED` | `True` — отдавать OTA, `False` — обычный ответ `{}` |
| `OTA_TARGET_VERSION` | Версия ESP для обновления. `"2.0.24"` — только 2.0.24 получит OTA. `""` — все версии |
| `OTA_CONFIG` | Секция `ota` с url/md5/size файлов |

**Защита от зацикливания:** сервер проверяет `version_esp` из POST-данных. Если версия ESP уже обновлена — `ota` не отдаётся.

### Настройка release-сервера

1. Создать директорию для OTA-файлов на сервере (например `/ota/`)
2. Загрузить файлы:
   - `nodemcuv2-X.X.X.bin` (firmware)
   - `nodemcuv2-X.X.X-fs.bin` (filesystem)
3. Убедиться что файлы доступны по HTTPS
4. Указать url/md5/size каждого файла в конфигурации сервера
5. Установить `OTA_TARGET_VERSION` на версию, которую нужно обновить
6. Включить `OTA_ENABLED = True`

### Отключение OTA после обновления

Два способа:
- **Автоматический:** `OTA_TARGET_VERSION = "2.0.24"` — после обновления до 2.0.25 устройство перестанет получать OTA
- **Ручной:** `OTA_ENABLED = False` — полностью отключить OTA для всех

## Сборка OTA-бинарей

### Скрипт сборки

```bash
cd ESP8266
./scripts/build_and_deploy.sh 2.0.25
```

Скрипт выполняет:
1. Временно подменяет `firmware_version` в `platformio.ini` на указанную версию
2. Собирает прошивку: `platformio run --environment waterius_2`
3. Собирает файловую систему: `platformio run --target buildfs --environment waterius_2`
4. Вычисляет MD5 и размеры
5. Копирует бинари в `ota/`
6. Выводит JSON-фрагмент секции `ota` для вставки в конфигурацию сервера
7. Восстанавливает `platformio.ini` (через trap, даже при ошибке)

Результат:
```
ESP8266/ota/
├── nodemcuv2-2.0.25.bin        # firmware (~633 KB)
└── nodemcuv2-2.0.25-fs.bin     # filesystem (~1000 KB)
```

### VSCode Task

В `.vscode/tasks.json` есть задача **OTA: Build and prepare**. При запуске запрашивает версию (по умолчанию 2.0.25).

### Переключение debug / release

В `scripts/build_and_deploy.sh` изменить `OTA_BASE_URL`:

```bash
# Debug
OTA_BASE_URL="https://us.pstd.ru/us-files/waterius"

# Release
OTA_BASE_URL="https://cloud.waterius.ru/ota"
```

### Загрузка на сервер

После сборки загрузить содержимое `ota/` на сервер. Файлы должны быть доступны по HTTPS.

## Тайминги

Реальные замеры на Waterius-2 (ChipId: 682bdb), WiFi 802.11n, HTTPS, сервер us.pstd.ru (2026-03-16):

### Полный цикл с OTA (FS + firmware)

```
00:00  ESP проснулся
00:04  WiFi подключён                         (~3.8с)
00:04  NTP синхронизация                       (~0.05с)
00:05  Отправка данных #1                      (~1.1с)
00:05  Сервер вернул ota
00:06  apply_settings + отправка данных #2     (~1с)
00:06  OTA: start
00:06  Проверка батареи (USB: 4732 mV)         пропущена
00:07  OTA: downloading filesystem...
00:54  OTA: filesystem updated OK              (~47с, 1024 КБ)
00:54  OTA: downloading firmware...
01:28  OTA: firmware updated OK                (~34с, 633 КБ)
01:28  OTA: complete, restarting ESP...
       ──── перезагрузка (eboot ~3.8с) ────
03:50  Новая прошивка стартовала
07:45  Firmware ver: 2.0.25
09:06  Going to sleep
```

### Тайминги по этапам

| Этап | Время | Размер | Скорость |
|---|---|---|---|
| WiFi подключение | ~3.8с | — | — |
| NTP синхронизация | ~0.05с | — | — |
| Отправка данных | ~1.1с | ~900 Б | — |
| Проверка батареи | ~0.2с | — | — |
| Обновление filesystem | ~47с | 1024 КБ | ~22 КБ/с |
| Обновление firmware | ~34с | 633 КБ | ~19 КБ/с |
| Перезагрузка (eboot copy) | ~3.8с | 633 КБ | — |
| **Полный цикл с OTA** | **~88с** | — | — |
| **Штатный цикл без OTA** | **~5-9с** | — | — |

Скорость скачивания ~19-22 КБ/с (HTTPS через WiFi 802.11n). Запас по таймеру Attiny: `extendWakeUp()` даёт 120 секунд, OTA занимает ~82 секунды — резерв ~38 секунд.

## Flash layout (ESP8266, 4MB)

```
┌──────────────────────────────────────┐
│ Bootloader (eboot): 4 KB            │ 0x000000
├──────────────────────────────────────┤
│ APP (текущая прошивка): ~633 KB      │ 0x001000
├──────────────────────────────────────┤
│ Staging area (свободно): ~2.4 MB     │ ← сюда скачивается новая прошивка
├──────────────────────────────────────┤
│ LittleFS: 1 MB                      │ 0x300000
├──────────────────────────────────────┤
│ EEPROM + WiFi config: 20 KB         │ 0x3FB000
└──────────────────────────────────────┘
```

ESP8266 **не имеет** dual-partition OTA (A/B) как ESP32. Используется staging area:

1. `ESP8266httpUpdate` скачивает новую прошивку в staging area
2. MD5 проверяется до записи команды bootloader
3. Если MD5 совпал — записывается команда для eboot в RTC-память
4. ESP перезагружается
5. eboot копирует прошивку из staging area в APP-область
6. Загружается новая прошивка

**Безопасность:**
- Если скачивание прервалось или MD5 не совпал — старая прошивка не тронута
- Единственный риск — сбой питания во время копирования eboot (шаг 5, ~1-2 сек). `extendWakeUp()` гарантирует что Attiny не отключит питание
- Обе копии (текущая + staging) помещаются между bootloader и LittleFS (~3 МБ, при прошивке ~633 КБ запас огромный)

**Обновление LittleFS:**
- `updateFS()` записывает образ напрямую в область LittleFS (0x300000)
- Не использует staging area — прямая запись

## Ограничения и риски

### Нет rollback

Если новая прошивка загрузилась но не работает — откат только через USB. Тестируйте прошивку перед публикацией на сервер.

### Только Waterius-2

OTA компилируется только для `WATERIUS_MODEL == WATERIUS_MODEL_2` (ESP-12F, 4MB flash). На ESP-01 (1MB) не хватает места для staging area.

### Расход батареи

OTA потребляет больше энергии: WiFi активен ~67 секунд вместо обычных ~5-9. Одно обновление не критично для 3xAA батарей, но не стоит запускать OTA часто.

### HTTPS без проверки сертификата

Используется `setInsecure()` (как и во всём проекте). Трафик шифруется, но сертификат сервера не проверяется. Для OTA это допустимо благодаря MD5-проверке содержимого.

### Обновление Attiny85 невозможно

ESP подключён к Attiny85 только по I2C — нет доступа к ISP-пинам. Обновление Attiny только через USB-программатор.

### Настройки после OTA

EEPROM (Settings) сохраняется при OTA — настройки WiFi, показания счётчиков и все пользовательские параметры не теряются. Настройки сбросятся только если в новой прошивке изменилась `CURRENT_VERSION` конфигурации.

## Настройка сервера (WordPress + Code Snippets)

Файл `doc/waterius_ota_snippet.php` — готовый PHP-сниппет для плагина Code Snippets (WordPress).

Установка:
1. Установить плагин Code Snippets на WordPress
2. Создать новый PHP-сниппет, вставить содержимое `waterius_ota_snippet.php`
3. В настройках Waterius (captive portal) указать HTTP URL: `https://your-server.com/cloud-waterius-ru`
4. Для управления OTA менять `$OTA_ENABLED` и `$OTA_TARGET_VERSION` в сниппете

Настройки в сниппете:
- `$OTA_ENABLED` — `true` для раздачи OTA, `false` для отключения
- `$OTA_TARGET_VERSION` — версия ESP для обновления (`''` = все версии)
- `$OTA_CONFIG` — секция `ota` с url/md5/size (генерируется скриптом `build_and_deploy.sh`)

## Структура файлов

```
ESP8266/
├── src/
│   ├── ota_parse.h            # Парсинг OTA JSON (parse_ota_params(), struct OtaParams, коды ошибок)
│   ├── ota_update.h           # Объявление perform_ota_update(), пороги напряжения
│   ├── ota_update.cpp         # Реализация OTA (проверка батареи, скачивание, запись, рестарт)
│   ├── main.cpp               # Вызов OTA после получения секции "ota" от сервера
│   └── json.cpp               # Отправка ota_error в JSON
├── test/
│   └── test_ota/
│       ├── main.cpp                 # Точка входа googletest
│       └── test_url_validation.cpp  # 11 тестов парсинга OTA JSON (native, googletest)
├── scripts/
│   └── build_and_deploy.sh    # Скрипт сборки OTA-бинарей
├── ota/                       # Результат сборки (не в git)
│   ├── nodemcuv2-X.X.X.bin
│   └── nodemcuv2-X.X.X-fs.bin
├── doc/
│   ├── ota.md                 # Этот документ
│   └── waterius_ota_snippet.php  # PHP-сниппет для WordPress Code Snippets
└── plan/
    └── ota_v2_plan.md         # План и результаты тестирования
```

## Запуск тестов

```bash
cd ESP8266
platformio test --environment native
```

11 тестов (googletest) покрывают парсинг OTA JSON:
- Полный OTA (firmware + filesystem), только firmware, только filesystem
- Пустой объект, отсутствующие url/md5, firmware не объект
- Значение size по умолчанию (0), проверка кодов ошибок

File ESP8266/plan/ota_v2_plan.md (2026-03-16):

# План доработки OTA v2

## Что сделано

| # | Задача | Файлы |
|---|---|---|
| 1 | Убрать манифест, парсить OTA из JSON-ответа | ota_update.cpp, ota_update.h, main.cpp |
| 2 | Удалить ota_manifest.h и test_manifest.cpp | ota_manifest.h, test_manifest.cpp |
| 3 | Упростить проверку батареи (только voltage, 3 замера/100мс) | ota_update.cpp, ota_update.h |
| 4 | Перенумеровать коды ошибок (5 вместо 8) | ota_update.h |
| 5 | Обновить скрипт сборки (без manifest.json) | scripts/build_and_deploy.sh |
| 6 | Обновить doc/ota.md | doc/ota.md |
| 7 | Извлечь parse_ota_params() в ota_parse.h, native-тесты | ota_parse.h, ota_update.cpp, test_url_validation.cpp |
| 8 | Обновить PHP-сниппет под OTA v2 | doc/waterius_ota_snippet.php |
| 9 | Тестирование на устройстве | — |

### Ключевые изменения

**Протокол:** `{"update_ota": "url"}` → `{"ota": {"firmware": {...}, "filesystem": {...}}}`. Убран отдельный HTTP-запрос на манифест — экономия ~0.6с и ~15 КБ RAM.

**Проверка батареи:** убрана нестабильная проверка `battery% < 40%`. Вместо этого — 3 измерения напряжения с шагом 100мс, среднее сравнивается с порогом 3300 мВ.

**Коды ошибок:** 0=NONE, 1=PARSE, 2=FS_UPDATE, 3=FW_UPDATE, 4=LOW_BATTERY. Убраны DOWNLOAD, INVALID_URL, TIMEOUT (не используются).

**HTTPS:** оставлен (WiFiClientSecure + setInsecure). Памяти хватает, защита от пассивного перехвата.

**PHP-сниппет:** обновлён под v2 — отдаёт секцию `ota` вместо `update_ota`.

**Native-тесты:** 11 тестов (googletest) для parse_ota_params() — парсинг JSON, валидация полей, коды ошибок.

---

## Результаты тестирования на устройстве

**Дата:** 2026-03-16
**Устройство:** Waterius-2 (ESP-12F, 4MB flash), ChipId: 682bdb
**Питание:** USB (4732 mV)
**WiFi:** ZLINKS, 802.11n, канал 7, RSSI -49 dBm
**Сервер:** WordPress + Code Snippets на us.pstd.ru

### Тест: полный OTA (firmware + filesystem), 2.0.24 → 2.0.25

| Этап | Время | Результат |
|---|---|---|
| WiFi подключение | ~3.8с | OK |
| NTP синхронизация | ~0.05с | OK |
| HTTP POST → сервер вернул `ota` | ~1.1с | OK, JSON с firmware + filesystem |
| Проверка батареи | — | Пропущена (USB: 4732 mV > 4600) |
| Парсинг OTA JSON | мгновенно | OK, url/md5/size распознаны |
| Скачивание filesystem (1024 KB) | ~47с (~22 KB/с) | OK |
| Скачивание firmware (633 KB) | ~34с (~19 KB/с) | OK |
| Перезагрузка (eboot copy) | ~3.8с | OK |
| **Полный цикл OTA** | **~88с** | **OK** |

### Проверено

- Сервер вернул `{"ota": {"firmware": {...}, "filesystem": {...}}}` — ESP распарсил корректно
- USB-питание определено (4732 mV > 4600 mV) — проверка батареи пропущена
- Filesystem обновлён, затем firmware — порядок правильный
- После рестарта: `Firmware ver: 2.0.25` — версия обновилась
- EEPROM/Settings сохранились (WiFi, ключи, показания — всё на месте)
- Второй запрос к серверу → `{}` (version_esp=2.0.25 ≠ target 2.0.24) — OTA не зациклился
- Устройство нормально ушло в сон после OTA

### Native-тесты (googletest)

```
platformio test --environment native
11 tests from 2 test suites — all PASSED
```

Тесты: FirmwareAndFilesystem, FirmwareOnly, FilesystemOnly, EmptyObject, FirmwareMissingUrl, FirmwareMissingMd5, FilesystemMissingUrl, FilesystemMissingMd5, SizeDefaultsToZero, FirmwareNotObject, OtaErrorCodes.Values.

---

## Варианты на будущее

### Dual-Partition OTA (A/B)

Сейчас ESP8266 использует staging area: eboot копирует прошивку поверх текущей (~1-3 сек). Dual-partition устраняет риск brick при сбое питания, но требует rboot, уменьшение LittleFS до 512 KB и ограничение прошивки до ~1.2 MB.

**Статус:** отложено. `extendWakeUp()` минимизирует риск сбоя питания.

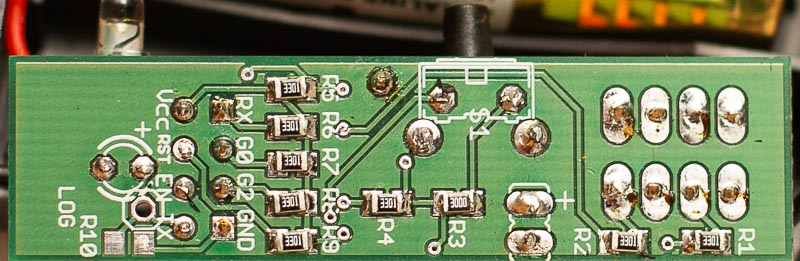
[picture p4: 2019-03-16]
Board/2.0/waterius-factory-board2_bottom.jpg

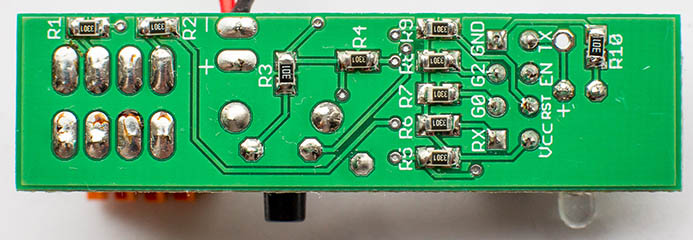
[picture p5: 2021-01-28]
Board/3.0/waterius-factory-board3_bottom.jpg

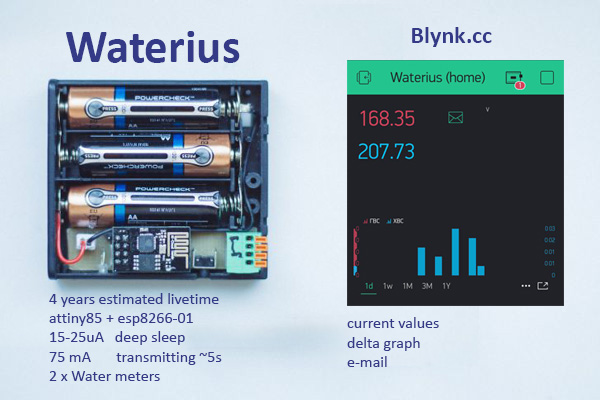
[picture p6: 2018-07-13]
files/main.jpg

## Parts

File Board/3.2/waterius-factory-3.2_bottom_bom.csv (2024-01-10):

Comment | Data | Designator | Footprint
CC0805KRX7R9BB104 | 0.1uF | C2 C3 | C0805
CL21B105KBFNNNE | 1uF | C1 C4 | C0805
RC0805FR-073K3L | 3k3 | R1 R2 R4 R5 R6 R7 R8 R9 | R0805
RC0805FR-07330RL | 300 | R3 R10 | R0805
ATTINY85-20SU | ATTINY85-20SU | IC1 | 8S2
MCP1700T-3002E/TT | MCP1700T-3002E/TT | U$1 | SOT95P237X112-3N

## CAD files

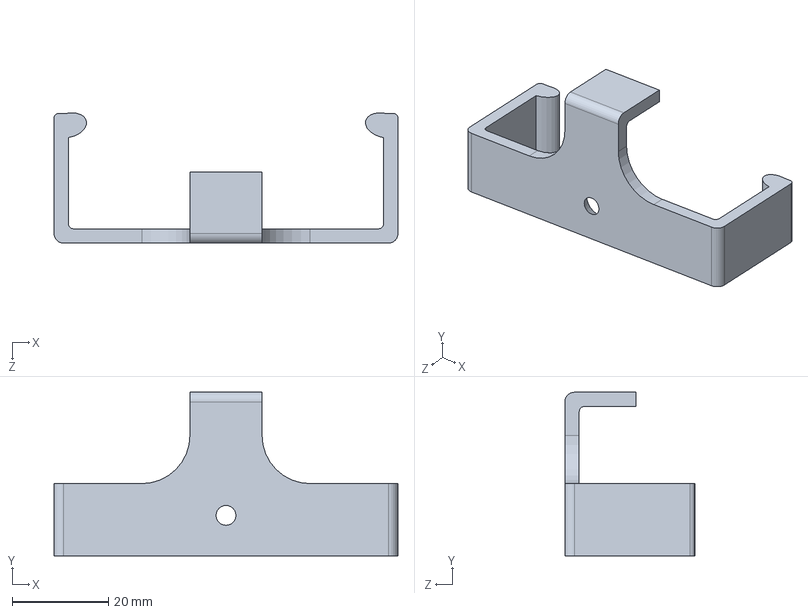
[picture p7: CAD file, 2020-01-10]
wall-mount/waterius-wall-mount-v31.SLDPRT
71.5 x 34.0 x 27.1 mm

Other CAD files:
wall-mount/waterius-wall-mount-v31_.stl

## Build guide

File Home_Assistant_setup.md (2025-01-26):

# Настройка интеграции c Home Assistant

Возможна настройка интеграции Ватериуса с Home Assistant в двух режимах:

- [автоматический (с 0.11.0)](#автоматическая-настройка)
- [ручной](#ручная-настройка)

**Важно!** Для обоих режимов необходима настроенная интеграция Home Assistant c [брокером MQTT](https://www.home-assistant.io/integrations/mqtt/).

## Настройки Ватериуса

Для обоих режимов необходимо, чтобы были заполнены следующие настройки в Ватериусе:
1. Указан ip адрес MQTT брокера или имя сайта (192.168.1.5 без http или http://public-broker.ru без номера порта)
2. Указан port MQTT брокера
3. Указан топик, по которому будут отправлены данные (Topic). Топик должен быть уникальным.

Эти настройки отображаются при выделенном чекбоксе "доп. настройки".

## Автоматическая настройка

Для включения автоматической настройки интеграции с Home Assistant при настройке ватериуса отметьте пункт "АВтоматическое добавление в Home Assistant"

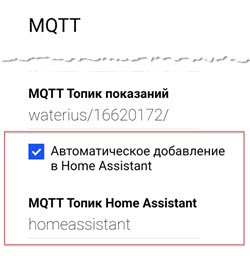
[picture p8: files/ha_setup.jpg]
Настройка интеграции


После завершения настройки и отправки первых показаний в интерфейсе Home Assistant появится новое устройство.

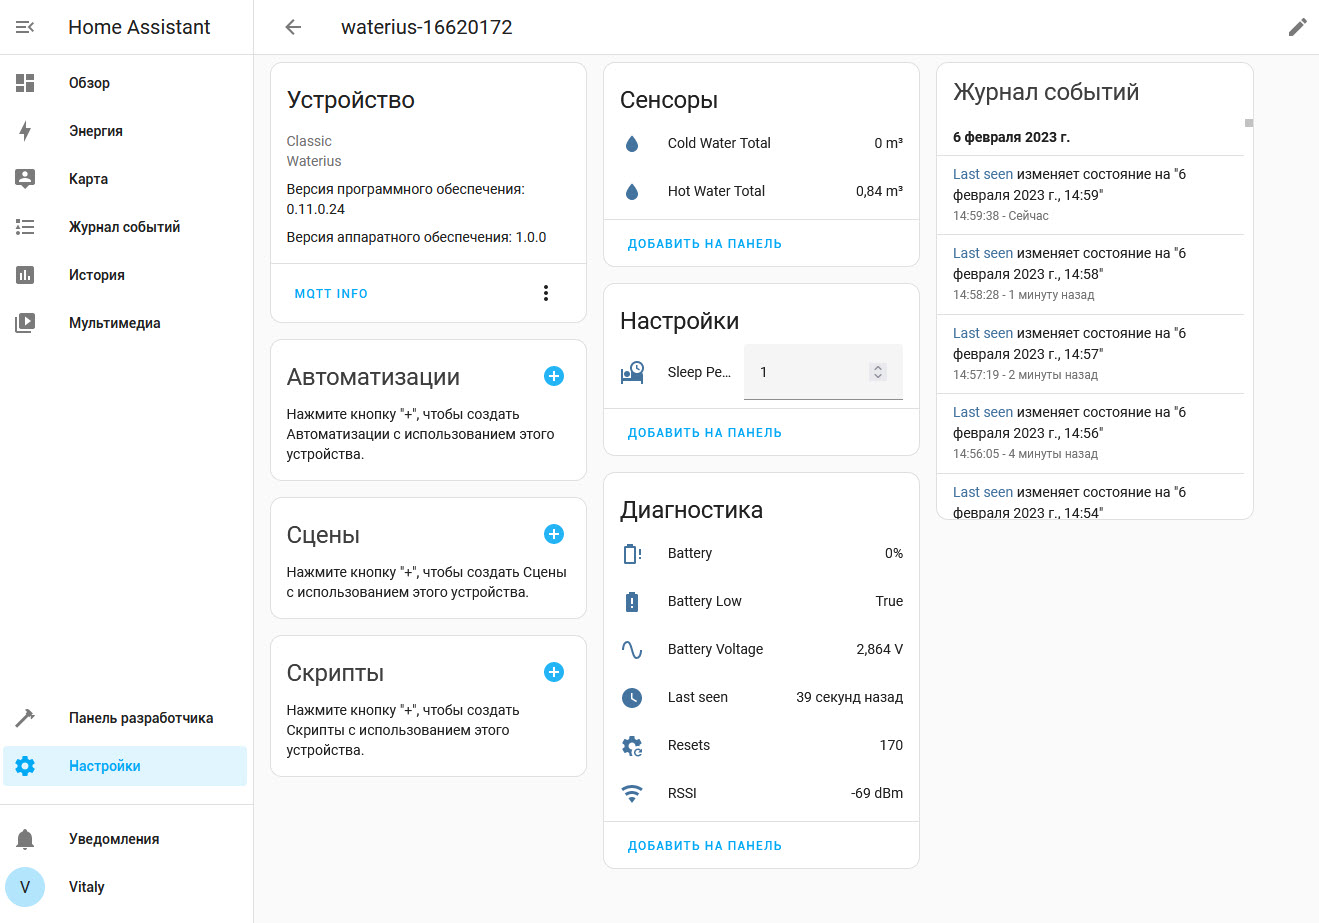
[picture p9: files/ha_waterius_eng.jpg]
Ватериус


Для сенсоров показаний (холодная, горячая) и RSSI доступны дополнительные атрибуты, которые можно увидеть щелкнув на выбранный сенсор

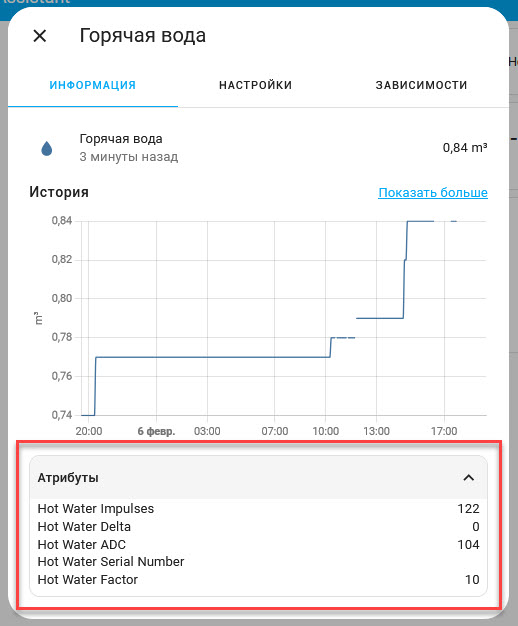
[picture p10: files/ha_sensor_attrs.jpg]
Атрибуты


После появления устройства и его показателей можно настроить панель "Энергия" для автоматического посчета расходов.

Добавьте в свойствах панели "Энергия" показания расхода воды

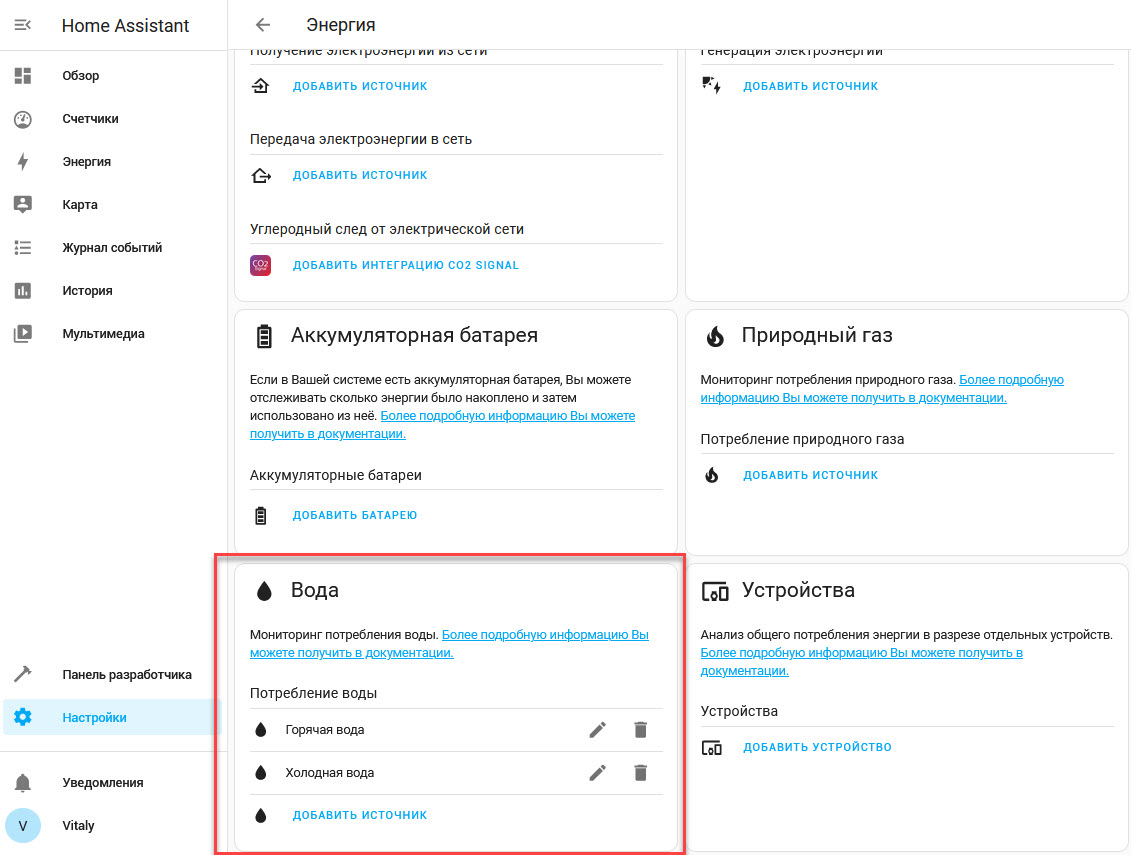
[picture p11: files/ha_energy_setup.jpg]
настройка панели "Энергия"


После этого отчеты станут доступны в панели.

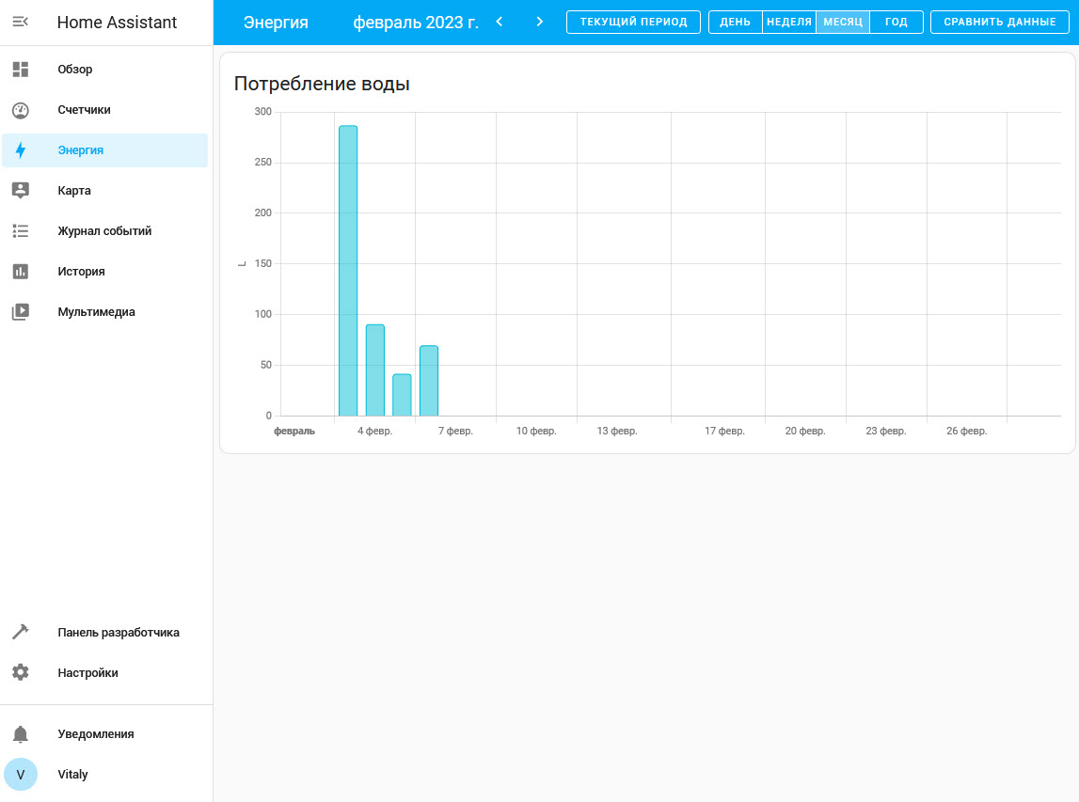
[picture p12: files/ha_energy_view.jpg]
Панель "Энергия"


_Статистика может отражаться не сразу, а по прошествии некотрого времени._

### Перевод названий на русский

Для того чтобы автоматически добавить переводы ко всем показателям можно воспользоваться [настройкой](https://www.home-assistant.io/docs/configuration/customizing-devices/#customizing-entities). Для этого в конфигурационный файл `configuration.yaml` добавьте следующу секцию:

```yaml
homeassistant:
  customize_glob:
    "sensor.waterius_*_ch0":
      friendly_name: "Горячая вода"
    "sensor.waterius_*_ch1":
      friendly_name: "Холодная вода"
    "sensor.waterius_*_voltage_low":
      friendly_name: "Низкое напряжение"
    "sensor.waterius_*_battery":
      friendly_name: "Батарейки"
    "sensor.waterius_*_voltage":
      friendly_name: "Напряжение"
    "sensor.waterius_*_timestamp":
      friendly_name: Последняя передача
    "sensor.waterius_*_resets":
      friendly_name: "Перезагрузки"
    "sensor.waterius_*_rssi":
      friendly_name: "Качество связи"
    "number.waterius_*_period_min":
      friendly_name: "Период отправки"
```

После перезагрузки Home Assistant свойства устройства будут выглядеть следующим образом

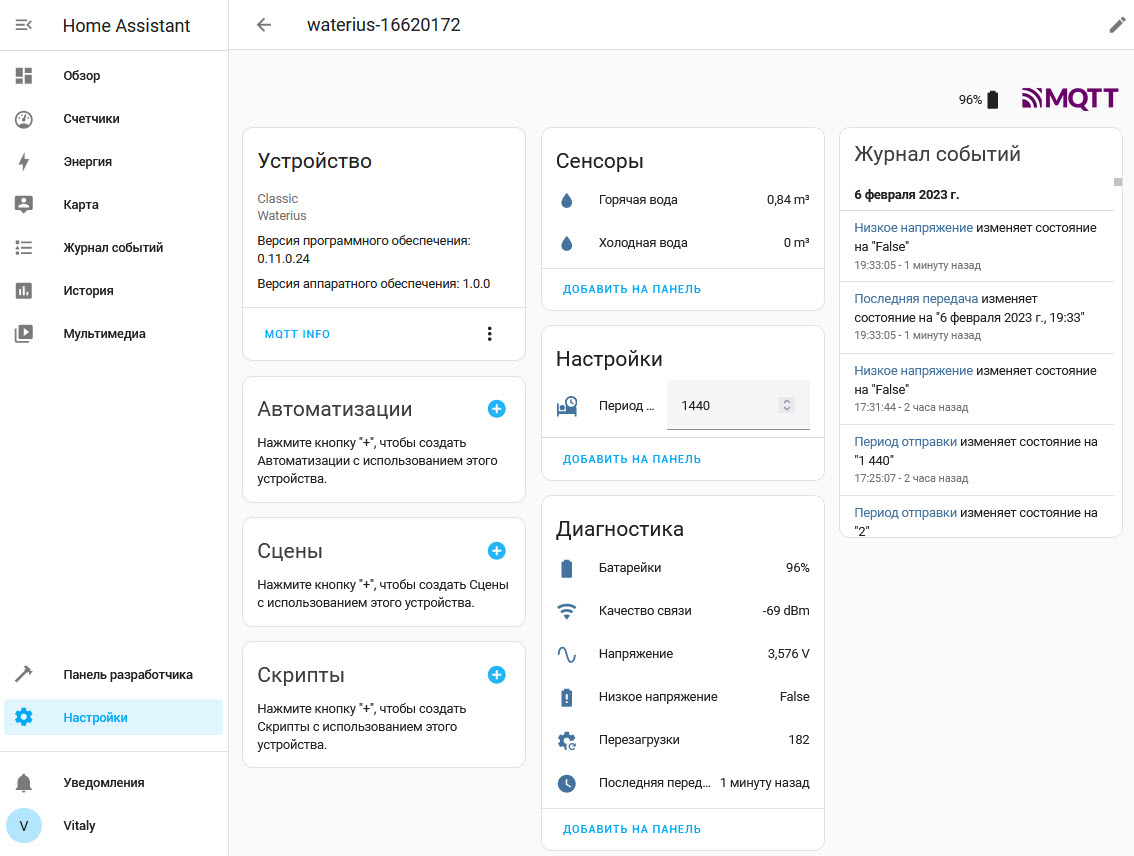
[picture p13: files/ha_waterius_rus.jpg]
Русификация


## Ручная настройка

Предполагается, что у вас уже установлен MQTT брокер, а также соответствующая интеграция для Home Assistant.

[Видео инструкция](https://www.youtube.com/watch?v=50J8hMOy7Dc)

### Создание сенсоров

Со списком доступных параметров, а также их описанием можно ознакомиться по [ссылке](https://github.com/dontsovcmc/waterius/blob/master/Export.md)

Также параметры и их текущие значения можно посмотреть при помощи [MQTT Explorer](http://mqtt-explorer.com/)

Ознакомьтесь с примером файла конфигурации [configuration.yaml](homeassistant.configuration.yaml)

Обратите внимание, что название сенсора

```yaml
states.sensor.kholodnaia_voda.last_updated
```

у вас может отличаться, всё зависит от того как вы назвали сенсор слушающий топик расхода холодной воды *ch1*

## Создание автоматизаций

Приведённые ниже автоматизации отправляют уведомления в телеграмм о низком напряжении питания Ватериус, а также в случае если устройство не выходило на связь более 27 часов (100 000 сек)

#### Низкое напряжение на Ватериус

**NB:** Значение сенсора в entity_id может отличаться от указанного в примере, в случае если вы вносили изменения в название сенсоров.

```yaml
- alias: Ватериус низкое напряжение
  trigger:
  - platform: state
    entity_id: sensor.napriazhenie_pitaniia_vateriusa
    to: Низкое напряжение
  action:
  - service: notify.telega
    data:
      message: Внимание! На ватериус зафиксированно низкое напряжение
  mode: single
```

#### Ватериус не выходил на связь более 27 часов

**NB:** Значение сенсора в entity_id может отличаться от указанного в примере, в случае если вы вносили изменения в название сенсоров.

```yaml
- alias: Ватериус вне сети более 27 часов
  trigger:
  - platform: state
    entity_id: sensor.vaterius_last_seen
    to: '100000'
  action:
  - service: notify.telega
    data:
      message: Внимание! Ватериус вне сети более 27 часов.
  mode: single
```

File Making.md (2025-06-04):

Вопросы по изготовлению задавайте тут: [issues](https://github.com/dontsovcmc/waterius/issues)

## Компоненты

| # | Наименование | Кол-во | Примечание | Магазин | 
| ---- | ---- | ---- | ---- | ---- |
| 1 | Atmega Attiny85-20SU | 1 | Attiny85V, Attiny45, Attiny45V тоже ок | [chipdip](https://www.chipdip.ru/product/attiny85-20su) |
| 2 | Керам. конденсатор SMD 0805 16В 0.1 мкФ | 2 |  | [chipdip](https://www.chipdip.ru/product/grm21br71h104k) |
| 3 | Керам. конденсатор SMD 0805 16В 1 мкФ  | 2 | для стабилизатора. можно любой > 1 мкФ | [chipdip](https://www.chipdip.ru/product/grm21br71c105k) |
| 4 | Резистор SMD 0805 3.3 кОм | 8 | Для i2c 2-6кОм, для остальных до 10кОм | [chipdip](https://www.chipdip.ru/product0/9000079498) |
| 5 | Резистор SMD 0805 300 Ом | 2 | Для светодиода >250Ом, для земли любой до 500Ом | [chipdip](https://www.chipdip.ru/product0/9000079473) |
| 6 | Светодиод 3В | 1 | Любой. Беру GNL-3014PGC 8000мКд, очень яркий. | [chipdip](https://www.chipdip.ru/product/gnl-3014pgc) |
| 7 | Разъем гнездо на плату 2.54мм PBD-8 | 1 | или KLS1-208-2-08-S | [chipdip](https://www.chipdip.ru/product/pbd-8) |
| 8 | Кнопка тактовая угловая 5.8мм TS-A3PV-130 | 1 | Угловая длиной от 5.8мм. Аналоги: KLS7-TS6606-7.0-180 (TC-0206) (7мм), 1-1825027-3,4,5,6,7,8 TS-1002N-BR07016, ST-1102VX-7, TC-1102N-C-B-B, TS-1093C-A7B2-D1, UK-B02124-G7-160, KH-6X6X7H-ZJ | [chipdip](https://www.chipdip.ru/product/kls7-ts6606-7.0-180-tc-0206) |
| 9 | Пин на плату | 1 | Любой для прошивки | [chipdip](https://www.chipdip.ru/product/tyco-826629-2) |
| 10 | ESP8266-01 | 1 | ESP8266-01 потребляют 0-10мкА зависит от продавца и думаю чипа памяти | [ali (CN888 Store)](https://s.click.aliexpress.com/e/_d89oOKR)( качество, быстрая доставка) [yandex](https://yandex.ru/search/?text=ESP8266-01&lr=213) |
| 11 | Закрытый батарейный отсек 4xAA | 1 | У ЧипДип KLS5-812-B, качество не очень. | [aliexpress](http://s.click.aliexpress.com/e/43K45ruk)(проверенный) [chipdip](https://www.chipdip.ru/product/fc1-5230) |
| 12 | Стабилизатор MCP1700T-3002E-TT | 1 |  | [chipdip](https://www.chipdip.ru/product/mcp1700t-3002e-tt-microchip) Не покупайте на ali, нужен оригинальный. |
| 13 | Разъем под кабель на плату 4 контакта 2.54мм | 1 | Без винтов: DG141V-2.54-04P-14-00AH | [chipdip](https://www.chipdip.ru/product0/8011963447) |
| 14 | [Плата](Board/board_3_3.jpg) | 1 | или [ЛУТ](Board/1.0-homemade/waterius-homemade-board.png) | [заказ на OshPark](https://oshpark.com/shared_projects/gJDtn5z5), [Gerber файлы](Board) |
+ программаторы для Attiny85 и ESP8266-01

## Схема

Электрическая схема: 
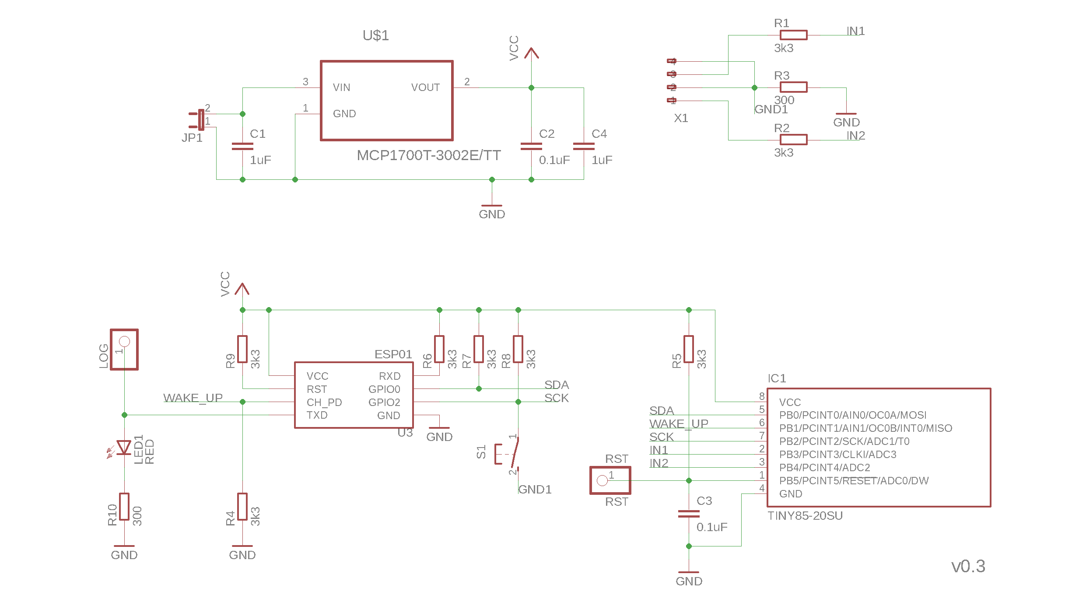
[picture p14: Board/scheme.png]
 

Вот так выглядит заводская плата с напаенными элеметами:

Плата 3.3 Ватериуса

По фотографии удобно паять.

# Изготовление

0. Для изготовления платы в папке board лежат фотографии 2-х слоёв (600 dpi) и файлы EagleCad.
Итак, все компоненты, плата и программаторы у вас есть. 

1. Пайку лучше начинать с резисторов 3к3, 300, конденсаторов. Далее припаять стабилизатор, attiny85, кнопку, светодиод и пин.
2. Припаять зеленый разъем DG141V, откусить контакты, выступающие больше чем на 0.5-1мм от платы.
3. Припять черный разъем PBD-8 с небольшим количеством припоя: потом нужно будет откусить контакты, выступающие больше чем на 0.5-1мм от платы.
4. Проверьте отсутствие коротких замыканий на плате.
5. Ток потребления с непрошитой Attiny85 со стабилизатором должен быть 300-600мкА.
6. Прошейте attiny85 через разъём подключения ESP. Не забудьте про пин ресет и подачу питания. 
7. Ток потребления с прошитой Attiny85 со стабилизатором должен быть 7-11мкА.  
Если он выше, промойте плату от флюса! Один раз мне пришлось отпаивать стабилизатор, мыть и припаивать назад - после высыхания спирта ток возвращался к 120мкА. 
8. Прошейте ESP с помощью 3.3в usb-ttl. ESP не будет включать точку доступа без подключения к attiny. ESP-01S включится без точки доступа, ESP-01 не включится.
9. Ток потребления Ватериуса с только что прошитой ESP, которая не разу не была включена ~2мА.
10. Удалите светодиод у ESP и резистор (см. ниже) либо сделайте это после тестирования. Иначе у вас сядут батарейки за 1 месяц.
11. Подготовьте корпус Ватериуса и установите в него плату.

Можно пользоваться! =)
Ток потребления Ватериуса с ESP после выполнения настройки и корректного подключения к точке доступа 7-15 мкА.
Если он не существенно выше - отмойте плату от флюса.

Примечание:
Если Ватериус при настройке не может подключиться к точке доступа (светодиод горит больше 10 сек после нажатия ОК), зайдите еще раз на его веб страницу (нужно опять ввести SSID, password). Чтобы выключить точку доступа - нажмите кнопку ~5сек и отпустите.

### Примечания

Доработка ESP8266-01:
1. Удалить оба светодиода. Я это делаю разрезанием дорожки ножом между светодиодом и резистором.

Доработка ESP8266-01s:
1. [Удалить резистор](https://github.com/dontsovcmc/waterius/raw/master/files/esp8266-01s_mod.jpg). 
2. Удалить светодиод Wi-Fi.

### Изготовление корпуса

1. Дырка под разъем DG141V-2.54-04P-14-00AH в крышке батарейного блока.
Будьте аккуратны при разрезании пластикового корпуса. Лучше всего это делать бормашникой или дрелью. 
2. Отверстие под кнопку 4 мм.
3. Отверстие под светодиод 3мм. 

### Исполнение без стабилизатора

Убираем 2 конденсатора на 1 мкФ. Оставляем один 10мкФ или меньший по питанию.
Подключать две батарейки! Лучше всего литиевые 1.5В (~200руб/шт).

Если 2 батарейки не литиевые, то для увеличения времени работы устройства, необходимо купить Attiny85V (для пониженного напряжения), тогда счетчик должен работать вплоть до 2.5В. Обычная Attiny85 работает до 2.7В. 
Напряжение питания вы увидите в blynk на виртуальном пине V2 (не калиброванное, после стабилизатора).

#### Logging Attiny
При разработке прошивки для attiny85 удобно использовать лог на 3 пине. Параметры: 9600 8N1. 
Из-за не точной калибровки Attiny85 (до 10%) не все USB-TTL будут "слышать" лог =(.

Вид сверху на плату, разъем под счетчики сверху:

| GND | LOG (D3) | GND |  D4 | 
| ---- | ---- | ---- | ---- |
| низ |

Плата ESP внизу разъема.

#### Logging ESP

Посмотреть лог работы ESP можно подключив USB-TTL переходник к GND + выводу LOG (TX pin ESP). На плате есть дырка под пин (115200 8N1) или присоединившись к верхнему пину светодиода.

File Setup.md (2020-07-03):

# Установка и настройка

## Подключение счётчиков
- подключите счётчики воды к разъемам Wi-fi счётчика
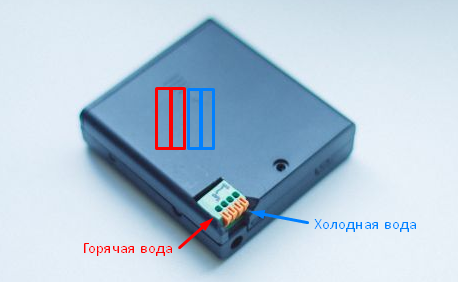
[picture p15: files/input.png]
 
Горячую воду подключаем в контакты 1-2, холодную в 3-4 (нумерация слева направо).
Обеспечьте неподвижность проводов.
Убедитесь, что холодной водой никто не пользуется.

## Настройка Ватериуса
- установите батарейки
- нажмите кнопку >4сек на корпусе И отпустите - Ватериус включит режим настройки - загорится светодиод и будет мерцать.
- найдите телефоном Wi-Fi точку доступа Waterius_0.10.0, подключитесь к ней.
- телефон откроет приветственную страницу подключения. Если нет, то наберите в браузере http://192.168.4.1
- следуйте указаниям инструкции

### Настройки 
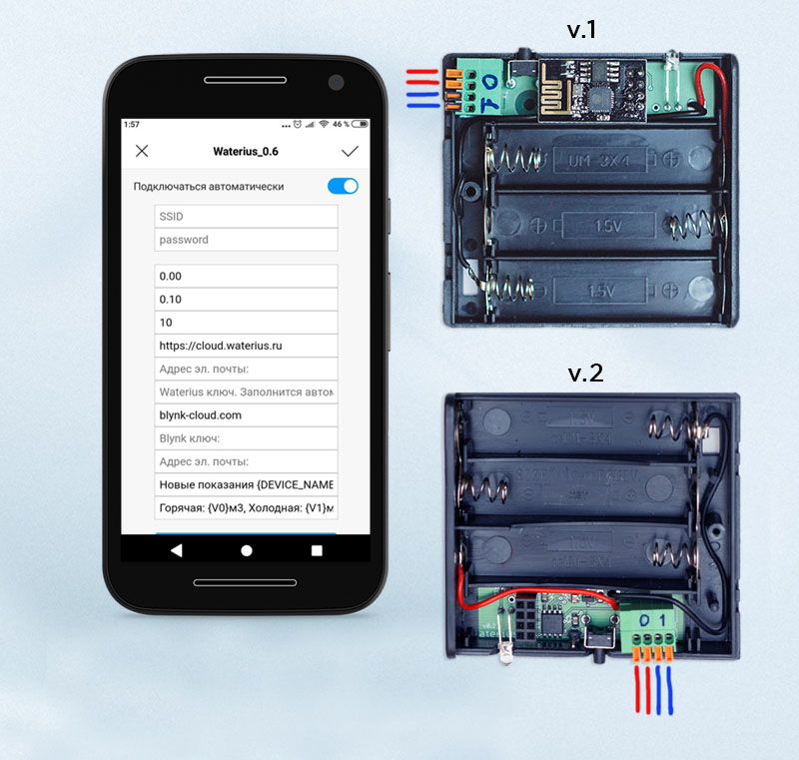
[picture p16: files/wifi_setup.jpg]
 

- SSID: имя сети домашнего Wi-Fi
- password: пароль домашнего Wi-Fi

<b>Примечение:</b> Если у вас счетчик на 1л/имп, то проливать 4л холодной воды надо каждую настройку!

# Настройки отправки

<a href="https://github.com/dontsovcmc/waterius/blob/master/Export.md">Настройка отправки по HTTP, MQTT, Blynk</a>

### Настройки счётчиков
- Спустите унитаз
- Надпись "не подключен" должна смениться на "подключен" (Ватериус видит импульсы от счетчика. Если не так, то спустите воду ещё пару раз, чтобы слить больше 10 литров. Если надпись не сменилась - проверьте подключение проводов.)
- Введите показания холодной воды.
1. Введите дробное число кубометров (обычно это черные цифры на счетчике). После точки и запятой введите литры.
- Откройте горячую воду, чтобы надпись сменилась на "подключен".
- Введите показания горячей воды.
- Множитель (кол-во литров на импульс) определяется автоматически:
1. Настраивать надо каждый раз при включении настройки
2. Множитель определяется по Входу №2 (холодная вода)
3. Множитель равен 10, если кол-во импульсов пришедших от открытия Окна "Настройка", до нажатия кнопки "Сохранить" меньше либо равно 3.
4. Множитель равен 1, если 4 и выше.
5. Множитель для горячей и холодной воды одинаковый.
6. В настройке предлагается спустить унитаз. Объём воды в нем обычно 4 литра.
Таким образом, вы спускаете унитаз и Ватериус видит, если пришло больше 3-х импульсов, то у вас счетчик выдает 1 импульс на каждый литр. Если пришел 1 импульс, то 1 импульс на 10 литров.

- нажмите Сохранить

- убедитесь, что светодиод погас через 3-10 секунд, что говорит об успешном подключении к Wi-Fi. Если светодиод не погас, то заново откройте 192.168.4.1 и введите корректные настройки Wi-Fi сети

Есть проблема с некоторыми GPON роутерами МГТС. Частично решается при помощи подключения по статическому ip вместо DHCP.

#### Завершение настройки, проверка связи с серверами
- нажмите на кнопку коротким нажатием (меньше 2сек) - Ватериус пришлет введенные вами показания и вы увидите их в Blynk, MQTT и waterius.ru или своем сервере.
- далее Ватериус будет слать показания <b>примерно</b> раз в сутки

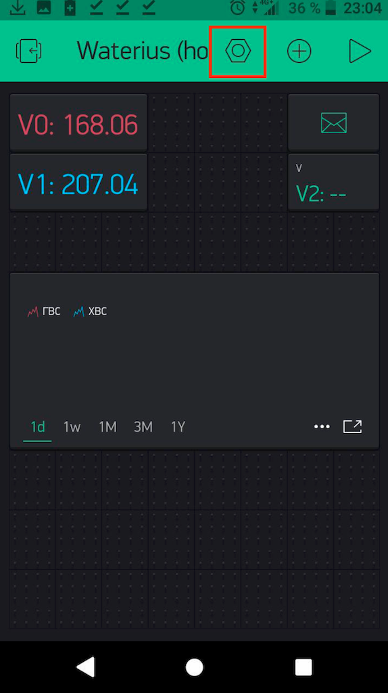
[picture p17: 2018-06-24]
files/step03.png

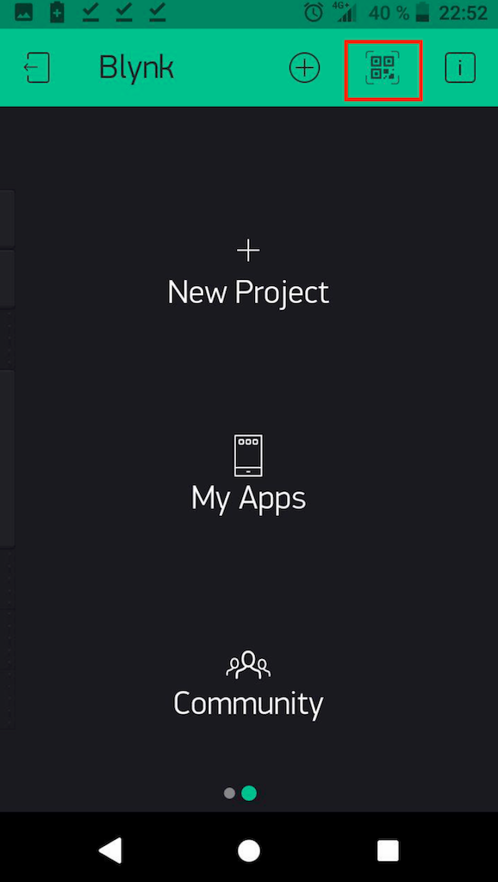
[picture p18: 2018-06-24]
files/step01.png

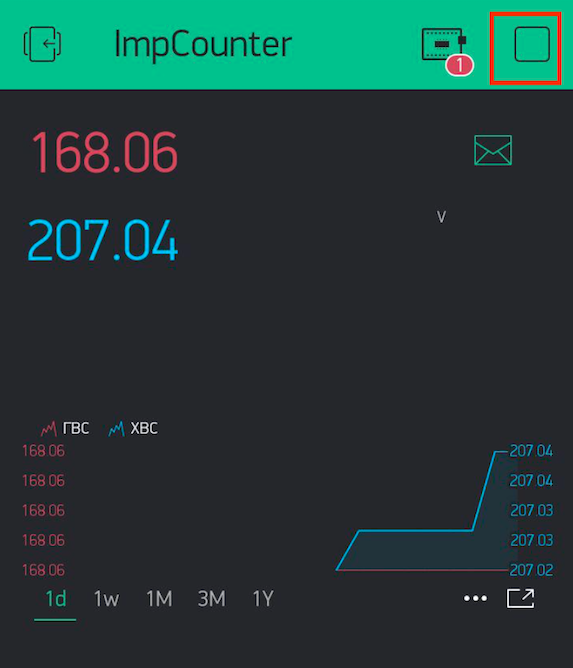
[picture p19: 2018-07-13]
files/step.png

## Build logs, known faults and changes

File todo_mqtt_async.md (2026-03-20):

# Архитектурный анализ: MQTT QoS 2 с AsyncMqttClient для Waterius

## Контекст

PubSubClient v2.8.0 не поддерживает QoS для `publish()`/`beginPublish()`. Для реализации гарантированной доставки нужна библиотека **AsyncMqttClient** (marvinroger/async-mqtt-client), которая поддерживает QoS 0/1/2 для публикации.

**Scope**: QoS 1/2 только для данных счётчиков (`publish_data`). Discovery и сервисные сообщения остаются QoS 0.

---

## 1. QoS 2 vs QoS 1 — нужен ли QoS 2 вообще?

| | QoS 1 (at least once) | QoS 2 (exactly once) |
|---|---|---|
| Handshake | 2 пакета: PUBLISH → PUBACK | 4 пакета: PUBLISH → PUBREC → PUBREL → PUBCOMP |
| Латентность | 1 round-trip | 2 round-trips |
| Дубликаты | Возможны | Исключены |
| Для Waterius | Безвредны — показания абсолютные (м³), дубликат просто перезапишется | Не нужно — данные идемпотентны |

**Важный нюанс с `cleanSession=true`**: Если ESP уснёт между PUBREC и PUBCOMP, брокер (Mosquitto) всё равно доставит сообщение подписчикам после PUBREC. Фактически это поведение QoS 1. Это нивелирует саму идею "ровно однажды" для wake-sleep устройства.

**Рекомендация**: QoS 1 более чем достаточен для Waterius. QoS 2 оправдан только если downstream обрабатывает дельты или считает каждое сообщение как событие. Архитектура ниже покрывает оба варианта.

---

## 2. Главная проблема: async API vs синхронный wake-send-sleep

Текущий flow в `main.cpp` — линейный:
```
connect_and_subscribe_mqtt()  → sync, блокирующий
send_mqtt()                   → sync, блокирующий
wifi_shutdown()
deepSleep()
```

AsyncMqttClient — полностью неблокирующий: `connect()`, `publish()`, `subscribe()` возвращаются мгновенно. Результат приходит через callback.

### Решение: синхронные обёртки с yield()

На ESP8266 WiFi стек (lwIP) и ESPAsyncTCP обрабатывают события при вызове `yield()` / `delay(0)`. Паттерн:

```cpp
struct MqttState {
    volatile bool connected = false;
    volatile bool disconnected = false;
    volatile uint8_t pending_qos_count = 0;  // неподтверждённые QoS-пакеты
    volatile bool subscribe_done = false;
    // Буфер для incoming retained-сообщений
    char incoming_topic[128];
    char incoming_payload[256];
    volatile bool has_incoming = false;
};

static MqttState mqtt_state;

// Блокирующее ожидание с таймаутом
bool wait_for(volatile bool &flag, unsigned long timeout_ms) {
    unsigned long start = millis();
    while (!flag) {
        yield();  // отдаём управление TCP стеку
        if (millis() - start > timeout_ms) return false;
    }
    return true;
}

// Ожидание всех PUBACK/PUBCOMP
bool wait_all_published(unsigned long timeout_ms) {
    unsigned long start = millis();
    while (mqtt_state.pending_qos_count > 0) {
        yield();
        if (millis() - start > timeout_ms) return false;
    }
    return true;
}
```

**Ограничение**: callback-и AsyncMqttClient вызываются из контекста TCP стека. Они должны быть максимально легковесными — только флаги и копирование данных. Нельзя вызывать `yield()` из callback-ов.

---

## 3. Трекинг пакетов

Для данных достаточно атомарного счётчика (не нужен полноценный трекинг по packetId):

```cpp
// При публикации
uint16_t id = mqttClient.publish(topic, qos, retain, payload, len);
if (qos > 0 && id != 0) {
    mqtt_state.pending_qos_count++;
}

// В callback onPublish (PUBACK для QoS 1, PUBCOMP для QoS 2)
void onMqttPublish(uint16_t packetId) {
    if (mqtt_state.pending_qos_count > 0)
        mqtt_state.pending_qos_count--;
}
```

Discovery публикуется с QoS 0 — трекинг не нужен.

---

## 4. Приём retained-команд от HA

Текущий `mqtt_callback` синхронно вызывает `publish()` внутри себя. В async-модели callback должен только буферизовать:

```cpp
// callback — только копируем данные
void onMqttMessage(char* topic, char* payload, ..., size_t len, ...) {
    strncpy(mqtt_state.incoming_topic, topic, sizeof(mqtt_state.incoming_topic));
    memcpy(mqtt_state.incoming_payload, payload, len);
    mqtt_state.incoming_payload[len] = 0;
    mqtt_state.has_incoming = true;
}

// Основной поток — обработка
void process_retained_messages(AsyncMqttClient &client, Settings &sett, ...) {
    unsigned long start = millis();
    while (millis() - start < MQTT_RETAINED_WAIT) {
        yield();
        if (mqtt_state.has_incoming) {
            mqtt_state.has_incoming = false;
            String topic(mqtt_state.incoming_topic);
            String payload(mqtt_state.incoming_payload);
            update_settings(topic, payload, sett, data, json_data);
            // Стереть retained
            client.publish(mqtt_state.incoming_topic, 0, true, "", 0);
            start = millis();  // сбрасываем — может прийти ещё
        }
    }
}
```

---

## 5. Новый flow sender_mqtt.h

```
connect_and_subscribe_mqtt():
  1. mqttClient.connect()              // non-blocking
  2. wait_for(connected, 5000ms)       // yield-loop
  3. if auto_discovery:
       mqttClient.subscribe(topic/#, 1)
       wait_for(subscribe_done, 3000ms)
       process_retained_messages()     // yield-loop 500ms

send_mqtt():
  4. if auto_discovery && (SETUP || MANUAL):
       publish_discovery(...)          // всё QoS 0, fire-and-forget
  5. publish_data(...)                 // QoS 1 или 2
  6. wait_all_published(5000ms)        // ← КЛЮЧЕВОЕ: ждём все ACK/PUBCOMP
  7. mqttClient.disconnect()
  8. wait_for(disconnected, 1000ms)
```

Максимальное время MQTT-фазы: ~15 секунд. Сопоставимо с текущим PubSubClient.

---

## 6. Подводные камни

### Flash/RAM
- AsyncMqttClient: ~25-40 KB flash (PubSubClient: ~12 KB). Прирост ~15-28 KB. При 82% (~819 KB) — хватит.
- RAM: ESPAsyncTCP уже в проекте (для WebServer в SETUP_MODE). MQTT работает в TRANSMIT_MODE — не пересекаются.

### ESPAsyncTCP fork
- Проект использует `ESP32Async/ESPAsyncTCP@2.0.0`. AsyncMqttClient (marvinroger) ожидает оригинальный `ESPAsyncTCP`. Нужна проверка совместимости заголовков.

### Streaming API нет
- AsyncMqttClient не имеет `beginPublish/write/endPublish`. Только `publish(topic, qos, retain, payload, len)`. Текущие `publish_big` / `publish_chunked` не нужны — AsyncMqttClient сам буферизует.

### cleanSession и QoS 2
- С `cleanSession=true` (обязательно для wake-sleep) брокер не хранит состояние между соединениями. Если ESP уснёт до PUBCOMP — транзакция не завершится. Mosquitto доставит сообщение уже после PUBREC, что фактически = QoS 1.

### Баг в текущем коде
- `subscribe.cpp:289` — `mqtt_connect()` возвращает `true` после всех неудачных попыток. При миграции баг устраняется автоматически.

---

## 7. Затрагиваемые файлы

| Файл | Изменения |
|---|---|
| `platformio.ini` | +async-mqtt-client, -PubSubClient |
| `senders/sender_mqtt.h` | **Полная перепись**: MqttState, sync-обёртки, callback-и |
| `ha/publish.h` + `.cpp` | **Перепись**: три режима → один `publish()` с QoS |
| `ha/subscribe.h` + `.cpp` | **Существенная перепись**: mqtt_connect/subscribe удаляются, callback буферизуется |
| `ha/publish_data.h` + `.cpp` | Смена сигнатур: `PubSubClient&` → `AsyncMqttClient&`, добавление QoS |
| `ha/publish_discovery.h` + `.cpp` | Смена сигнатур (механическая замена) |
| `ha/discovery_entity.h` | Смена include |
| `main.cpp` | Без изменений — API `connect_and_subscribe_mqtt()` / `send_mqtt()` сохраняется |
| `setup.h` | Без изменений (QoS задаётся define-ом или из reserved-байта) |

---

## 8. Резюме

- **Для Waterius QoS 1 достаточен** — данные идемпотентны, `cleanSession=true` нивелирует преимущества QoS 2
- Миграция на AsyncMqttClient — **средний объём работ** (~6-7 файлов), но архитектурно чистая
- Ключевой паттерн: **sync-обёртки с yield()** + **счётчик pending QoS** + **wait перед disconnect**
- ESPAsyncTCP уже в проекте — дополнительных зависимостей (кроме самого async-mqtt-client) нет

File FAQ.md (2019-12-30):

## Проблемы и их решение

По короткому нажатию светодиод быстро моргает и затухает
1. Ватериус не сконфигурирован. Нажмите кнопку 4-5 сек светодиод должен заморгать. Подключитесь и настройте.

В интерфейсе настроек http://192.168.4.1/wifi нет вашей точки доступ
1. Перезагрузите страницу

По короткому нажатию светодиод горит ~15 секунд и данные не передаются
1. Wi-Fi точка доступа выключена или не добивает радиосигнал или изменился пароль
2. Очень долгое подключение по DHCP. В ватериусе установлен таймаут 15 секунд. Напишите разработчикам.
3. Возможно вы несколько раз за минуту нажимали кнопку и роутер решил больше не подключать к себе клиента.

Ватериус не выходит на связь через сутки:
1. Ватериус обычно выходит через 25-26ч
2. Нажмите коротко кнопку и по длительности свечения, определите подключился ли он к точке доступа. Возможно при закрытой дверце связь хуже или роутер перенесли в другое место.

Значения не увеличиваются
1. Проверьте наличие контакта с счётчиком

Значения считаются неправильно:
1. Проверьте подключение: горячая вода слева, холодная справа. Сам пару раз путал.
2. Проверьте надежность крепления провода в разъёме: если не зажать провод, то Ватериус может насчитать ого-го. 
3. Если у вас счётчик на 1л/имп, то при настройке обязательно нужно вылить 4л холодной воды - Ватериус установит множитель в 1. Множители обоих счётчиков должны быть одинаковые.
Если у вас подключён только счётчик горячей воды и он на 1л/имп, то либо подключите его во вход холодной воды, либо замкните 4 раза контакты разъёма холодной воды (1 сек замыкание — 2 сек размыкание) во время настройки.
4. Проверьте целостность провода к счётчику. За год 1 раз встретился счётчик, который постоянно уходил вперёд в показаниях. При этом аналогичный рядом считался корректно. 

Если у вас другая проблема, пишите, будем диагностировать!

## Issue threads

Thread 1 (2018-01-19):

TODO:

dontsovcmc, 2018-01-19:
tiny: EEPROM - OK
esp: DNS сервер - OK
tiny: CRC
esp: DHCP запоминать ip, если в следующий раз ip не подойдет, включить DHCP и получить новый
esp: 2й wi-fi - ждем реализации от WifiManager
сервер: БД - скоро
сервер: визуализация - не нужно

Hardware:
конденсатор 10мкФ по питанию от вибрации батареек. - пока не надо
питание: включать ESP-01. экономия ~10мкА
UPD: ESP-01s почти ничего не потребляет.

tiny: заменить на  PIC16(L)F1454/5/9 или STM8L или TI430.

Функции:
esp: OTA update https://www.bakke.online/index.php/2017/06/02/self-updating-ota-firmware-for-esp8266/#more-328
esp: добавить настройки кол-во литров/импульс, начальные показания, хвс/гвс - OK
esp: NTP сервер https://github.com/arduino-libraries/NTPClient/blob/master/examples/Basic/Basic.ino  - можно через Blynk. Не нужно, т.к. будет сайт.
esp: передача сетевых настроек на сервер - не нужно

Доп. функционал:
esp: добавить датчик температуры. следить за горячей/хол водой..
tiny: точные показания по времени
tiny: датчик протечек - некуда

dontsovcmc, 2018-04-11:
Attiny хорошо бы заменить на современные аналоги: PIC16(L)F1454/5/9

dontsovcmc, 2018-05-01:
- питания через EN
- срезы только при изменении. отправка по заполнению буфера. или раз в N дней.

dontsovcmc, 2018-05-03:
Реализация без сервера:

1. добавить параметры в Web интерфейс счетчика
2. при просыпании, узнавать текущее время от NTP сервера. И при необходимости слать сообщение с текущими показаниями:
https://github.com/arduino-libraries/NTPClient/blob/master/examples/Basic/Basic.ino

dontsovcmc, 2018-05-08:
1. добавить диод на reset
2. запустить общий код в Atmel Studio
3. проверить регистр MCUSR при включении. Там инфа о перезагрузке.
4. сделать EEPROM
6. Проверить резистор на EN
5. отладить в Atmel Studio

dontsovcmc, 2018-05-08:
byte ResetSrc = MCUSR; // save reset source
  MCUSR = 0x00; //cleared for next reset detection
  if (ResetSrc & _BV(PORF)) Serial.println("PORF");
  if (ResetSrc & _BV(EXTRF)) Serial.println("EXTRF");
  if (ResetSrc & _BV(BORF)) Serial.println("BORF");
  if (ResetSrc & _BV(WDRF)) Serial.println("WDRF");

dontsovcmc, 2018-05-13:
1. кнопка на SDA - GND.
2. переписать код
3.

dontsovcmc, 2018-05-21:
1. потребление 2мА при включении?!
2. DNS сервер

может все таки можно без сервера?

dontsovcmc, 2018-06-19:
У библиотеки Blynk есть возможность синхронизации времени.
1. добавить параметр: день рассылки
Если день рассылки не пустой:
    Если месяц отправки не равен текущему
         Отослать

https://github.com/blynkkk/blynk-library/blob/master/examples/Widgets/RTC/RTC.ino

dontsovcmc, 2018-09-17:
Согласно [обзору STM8](https://www.terraelectronica.ru/news/5482) нам подходит этот: [STM8L051F3](https://docs-europe.electrocomponents.com/webdocs/1285/0900766b8128502b.pdf) на 20 пин. Можно взять и на 8 пин, но лучше больше, чтобы подключить датчик протечки и дополнительные входы.
PlatformioIO еще не поддерживает STM8L =(

dontsovcmc, 2018-09-24:
ESP32:
https://habr.com/post/418573/#comment_18937991
ULP Pulse Counting Example
examples/system/ulp/ вот что пишут:
With the default configuration (20ms ULP wakeup period), average current consumption in deep sleep mode is 16uA.

dontsovcmc, 2018-10-17:
Вот пример использования Радиомодуля с Attiny85. Т.к. мы автономны, нам нужно подавать на него питание. Это можно сделать, как отдельным стабилизатором, так и транзистором.

https://www.instructables.com/id/Mini-weather-station-with-Attiny85/

Проект с подключением LCD экрана тоже там.

dontsovcmc, 2022-01-13:
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

heX16, 2022-01-18:
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

"крутилки" которые с право внизу изменил - уменьшил у них "saturation", иначе они сильно бросаются в глаза и ухудшают восприятие картинки.

dontsovcmc, 2022-01-18:
> 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
>
> @dontsovcmc, вот так мне кажется лучше выглядит? - "крутилки" которые с право внизу изменил, уменьшил у них "saturation", иначе они сильно бросаются в глаза и ухудшают восприятие картинки.

Секс! Гордость за комьюнити! Спасибо! Хотите пул реквест на титул сделайте?)) будете в разработчиках ааха

Closed 2022-01-13.

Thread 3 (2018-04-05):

Обоснование: Питание

dontsovcmc, 2018-04-05:
ESP питается от 2.5 до 3.6В.
Attiny85 питается от 1.6 до 5.5В

Li-Po:
- требуется преобразователь
- требуется зарядка

Батарейки АА 2 шт:
+ цена
- емкость

Батарейки АА 3 шт:
+ цена
- требуется преобразователь

Согласно: https://geektimes.ru/company/madrobots/blog/243377/
Качественные и не дорогие батарейки имеют 2500 мА*В*ч при токе разряда 200мА.

== 2 батарейки ==
Согласно графику они разрядятся до 1.25В при 60% емкости. Значит в нашем распоряжении 1000 мА*В*ч. У нас две батарейки 2000 мА*В*ч и 3В, т.е. рассчитываем на ~850 мА*ч....

В году 8760 часов. 850 мА*ч израсходуем при токе 97мкА..
Если мы хотим работать 4 года, то ток должен быть 24мкА.

== 3 батарейки ==
потребление преобразователя 2-4мкА (MCP1700, HT7333)
лучше взять на 2.8В преобразователь, чтобы снизить напряжение входа.
MCP1700 есть в продаже. Вот статья про них http://www.microchip.ua/publicazii/02-08.pdf
https://eu.mouser.com/datasheet/2/268/20001826D-737536.pdf
Возьмем Vin на 0.6V больше Vout. 3.4В/3 = 1.15В
1.15В при 40% емкости.. Значит в нашем распоряжении будет 2500 мА*В*ч * 60% = 1500мА*В*ч. 3 батарейки = 4500 мА*В*ч! Это сильно больше 850 мА*ч, учитывая накладные расходы в 2мкА!

В году 8760 часов. 4500 мА*ч израсходуем при токе 500 мкА ...

dontsovcmc, 2018-04-12:
Еще подходящие регуляторы:
http://download.siliconexpert.com/pdfs/2010/3/17/18/51/48/247/tsc_/auto/ts9011_e07.pdf
TS9011PCY RM TS9011PCX RF  3.0В

Возможно этот http://ww1.microchip.com/downloads/en/devicedoc/21335c.pdf не пойму какое у него потребление при 25мкА

dontsovcmc, 2018-04-16:
При опросе входов через 16мс потребление вместо 70мкА (вместо 22 при опросе раз в секунду)

dontsovcmc, 2018-04-16:
В течении 3-х суток счетчик раз в 2 секунды проверял входы, раз в 30 минут выходил на связь.
175 раз. Из них 50 раз 134 байта, остальные разы 14 байт (проблемы i2c).
за это время напряжение 2х АА снизилось с 3.184 до 3.181В.

dontsovcmc, 2018-04-23:
2.6 sec первое включение
```
  NOTICE    (ESP) : Booted
000:00:00:00:041  NOTICE    (WIF) : Config loaded: IP=192.168.1.80, Subnet=255.255.255.0, Gw=192.168.1.1, Remote IP=192.168.1.42, Remote Port=5001
000:00:00:00:047  NOTICE    (WIF) : Device Id=11499, password=2627
000:00:00:00:052  NOTICE    (WIF) : Starting Wifi
000:00:00:00:057  NOTICE    (WIF) : Wifi status: 6
.....
000:00:00:02:373  NOTICE    (WIF) : Wifi status: 6
000:00:00:02:423  NOTICE    (WIF) : Wifi connected, got IP address: 192.168.1.80
000:00:00:02:424  NOTICE    (ESP) : Wifi-begined
000:00:00:02:424  NOTICE    (ESP) : I2C-begined
000:00:00:02:428  ERROR     (I2C end) : 2
000:00:00:02:433  ERROR     (I2C) : requestFrom failed
......
000:00:00:02:471  ERROR     (I2C) : requestFrom failed
000:00:00:02:475  NOTICE    (Stat: bytesReady) : 65535
000:00:00:02:480  NOTICE    (Stat: voltage) : 65535
000:00:00:02:485  CRITICAL  (I2C) : Slave is returning too much data
000:00:00:02:491  NOTICE    (WIF) : Making TCP connection to 192.168.1.42, Port 5001
000:00:00:02:558  NOTICE    (WIF) : Sending 14 bytes of data
000:00:00:02:559  NOTICE    (WIF) : Data sent successfully
000:00:00:02:660  ERROR     (I2C end) : 2
000:00:00:02:661  NOTICE    (ESP) : Going to sleep
```

650 ms когда данных 4 байта (700 ms при отсутствии данных),
```
000:00:00:00:188  NOTICE    (WIF) : Config loaded: IP=192.168.1.80, Subnet=255.255.255.0, Gw=192.168.1.1, Remote IP=192.168.1.42, Remote Port=5001
000:00:00:00:194  NOTICE    (WIF) : Device Id=11499, password=2627
000:00:00:00:200  NOTICE    (WIF) : Starting Wifi
000:00:00:00:206  NOTICE    (WIF) : Wifi status: 6
000:00:00:00:258  NOTICE    (WIF) : Wifi status: 6
000:00:00:00:309  NOTICE    (WIF) : Wifi status: 6
000:00:00:00:359  NOTICE    (WIF) : Wifi status: 6
000:00:00:00:409  NOTICE    (WIF) : Wifi status: 6
000:00:00:00:459  NOTICE    (WIF) : Wifi status: 6
000:00:00:00:510  NOTICE    (WIF) : Wifi status: 6
000:00:00:00:560  NOTICE    (WIF) : Wifi connected, got IP address: 192.168.1.80
000:00:00:00:560  NOTICE    (ESP) : Wifi-begined
000:00:00:00:560  NOTICE    (ESP) : I2C-begined
000:00:00:00:573  NOTICE    (Stat: bytesReady) : 4
000:00:00:00:573  NOTICE    (Stat: voltage) : 3146
000:00:00:00:574  NOTICE    (I2C) : Polling slave for 4 bytes
000:00:00:00:588  NOTICE    (I2C) : Data retreived
000:00:00:00:589  NOTICE    (WIF) : Making TCP connection to 192.168.1.42, Port 5001
000:00:00:00:650  NOTICE    (WIF) : Sending 18 bytes of data
000:00:00:00:651  NOTICE    (WIF) : Data sent successfully
000:00:00:00:654  NOTICE    (ESP) : Going to sleep
```

dontsovcmc, 2018-05-19:
Оптимизация wifi
https://www.bakke.online/index.php/2017/05/21/reducing-wifi-power-consumption-on-esp8266-part-2/

dontsovcmc, 2018-05-24:
EN - не ключ для питания ESP8266, а обычный пин включающий интерфейсы.
EN low питание в deepsleep около 10мкА.

Нужен силовой ключ для включения питания ESP8266.
Пример:
http://www.ti.com/lit/ds/symlink/tps22860.pdf
http://ww1.microchip.com/downloads/en/devicedoc/21335c.pdf

Посматриваемся, как сделана плата: http://www.ti.com/tool/TIDA-00484
http://www.ti.com/lit/df/tidrey5b/tidrey5b.pdf

dontsovcmc, 2018-06-14:
Статический IP для подключения к WiFi + сервер blynk...com + отправка данных = 3.8 сек
```
000:00:00:00:096  NOTICE    (WIF) : Starting Wifi
000:00:00:00:100  NOTICE    (WIF) : Wifi status: 6
000:00:00:00:305  NOTICE    (WIF) : Wifi status: 6
000:00:00:00:505  NOTICE    (WIF) : Wifi status: 6
000:00:00:00:705  NOTICE    (WIF) : Wifi status: 6
000:00:00:00:905  NOTICE    (WIF) : Wifi status: 6
000:00:00:01:106  NOTICE    (WIF) : Wifi status: 6
000:00:00:01:306  NOTICE    (WIF) : Wifi status: 6
000:00:00:01:506  NOTICE    (WIF) : Wifi status: 6
000:00:00:01:707  NOTICE    (WIF) : Wifi status: 6
000:00:00:01:907  NOTICE    (WIF) : Wifi status: 6
000:00:00:02:107  NOTICE    (WIF) : Wifi status: 6
000:00:00:02:308  NOTICE    (WIF) : Wifi status: 6
000:00:00:02:508  NOTICE    (WIF) : Wifi status: 6
000:00:00:02:708  NOTICE    (WIF) : Wifi status: 6
000:00:00:02:908  NOTICE    (WIF) : Wifi status: 6
000:00:00:03:109  NOTICE    (WIF) : Wifi status: 6
000:00:00:03:309  NOTICE    (WIF) : connected
000:00:00:03:562  NOTICE    (BLK) : run
000:00:00:03:763  ERROR     (BLK) : disconnected
```
Вроде ничего не менял в скетче, хз почему стал подключаться целых 3.5 секунды
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
dontsovcmc, 2018-12-03:
Китайцы представили свою энергоэффективную плату для ESP32. На ней стабилизатор 3.3В 1мкА до 0.6А: ETA3425

dontsovcmc, 2019-01-21:
Сравнительное тестирование литий-тионилхлоридных батареек
https://www.terraelectronica.ru/news/5706

dontsovcmc, 2019-04-05:
Будят GSM модуль транзистором irlml2502pbf
https://mysku.ru/blog/aliexpress/61934.html
https://www.infineon.com/dgdl/irlml2502pbf-1.pdf

terminuslat, 2019-12-16:
Я только только  срукожопил  девайс, пока на макетке. Настроить не могу пока, но для питания сразу выбрал LiFePO4. Плюсы: 1) Напряжение прям в точку, 3.65 при только с зарядки до 2.2 безвредного разряда - соответственно не нужен стабилизатор. 2) Нет прыжков напряжения, свойственным алкалинкам и (меньше) другим  Li-xxx. 3) Длительный срок службы (хранения) при слаботочной нагрузке - до 15 лет. 4) Это всё же АККУМУЛЯТОР! 5) Удовлетворительно средний саморазряд  до 5 % в месяц. 6) Термоустойчив, включая отсутствие ярко выраженного саморазряда как на морозе, так ми в жару.   Минусы: 1) Цена 2) низкая удельная емкость (типоразмер АА - 600 мА/ч., стоит в розницу на рынке 300 руб)

dontsovcmc, 2019-12-16:
@terminuslat Крутота! Только ватериус очень мало потребляет и аккумулятор скорее разрядится, чем сядет от нагрузки. Лучше всего ER14505 батарейку 3.6В 2.5А. От нее 7-10 лет должен пропахать, т.к. саморазряда нет. https://market.yandex.ru/search?cvredirect=2&text=ER14505&local-offers-first=0

terminuslat, 2019-12-16:
ну, я для себя, покамест, хочу. А поскольку слегка подвинут на зелёной энергетике, то вполне могу пельтьешку прикрутить к горячей трубе. Иэта музыка пообещает стать вечной )
Кстати,  у названной Вами батарейки приличная депассивация. Стало быть напряжение здорово может просесть при включении вайфая. То есть на излёте заряда легко опуститься ниже допустимого. Это сократит полезную ёмкость. Да, впрочем, даже в даташите быстрым назван разряд 30 миллиампер - при этом заявлена ёмкость уже 1300  мА/ч. В итоге по соотношению цена/мА/ч выигрывают среднеценовые алкалинки со стабилизатором... ИМХО...
Ладно, извиняюсь, что отвлекаю, пойду искать таки "прошивку с TEST_WATERIUS", не пойму где она лежит )), плата пока не работает ))

dontsovcmc, 2019-12-16:
@terminuslat хм.. может поэтому ставят кондеры побольше?

terminuslat, 2019-12-16:
спс )

dontsovcmc, 2020-03-23:
https://www.terraelectronica.ru/news/6478 по теме

Kabron287, 2021-02-18:
Собрал для погодного датчика такую схему питания.
Работает безупречно. Ток в отключке 10-20uA.
В качестве главных мозгов WEMOS D1 mini Pro.
Хороша тем что для USB моста используется CP2104, которая при отсутствие USB спит.
Питается она от WEMOS Battery Shield с встроенным зарядником и повышалкой до 5В.
Есть ньюанс, который не сразу выявился - необходима индуктивность, ибо при включении транзистора,  время нарастания питания очень мало и возникающая просадка ресетит тиньку.  Q8, Q9, Q5 - идеальный диод для развязки от питания тиньки при прошивке(она у меня  - Digispark).

Battery Shield нуждается в минимальной переделке: поскольку батарея, теперь подключается не напрямую, плюс батарейного контакта соединен с A0_ADC, а через RST выведен VBUS, чтобы при зарядке тинька знала что нужно включить ключ.
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

dontsovcmc, 2021-05-28:
LMR16006
https://www.revk.uk/2021/05/battery-powered.html

dontsovcmc, 2022-01-13:
@Kabron287 спасибо, что поделились!
сложности с включение esp-01 транзистором - у меня GPIO00, GPIO02 подтянуты к питанию т.к. линия i2c, а у GPIO02 внутренний резистор есть на плюс. Кажется их надо изолировать (но вопрос с прошивкой attiny возникает) или другие пины для i2c использовать. Так и поставили на паузу задачу...

dontsovcmc, 2023-09-15:
> LDO XC6206
Потребление 200mA (3.0V type). Т.е. надо ставить большой конденсатор, т.к. во время передачи.

dontsovcmc, 2024-03-31:
[CJ9113T6A](https://www.compel.ru/infosheet/JSCJ/CJ9113T6A)  - !
LM3670MF-3.3 https://rocelec.widen.net/view/pdf/ehgdv03kau/NATLS19550-1.pdf

MCP1640/B/C/D https://www.farnell.com/datasheets/1669480.pdf
MCP1623  https://docs.rs-online.com/e094/0900766b8132484e.pdf
BD70522GUL  https://fscdn.rohm.com/en/products/databook/datasheet/ic/power/switching_regulator/bd70522gul-e.pdf
[SP6651AEU](https://www.digikey.com/en/models/2472130)

tps736

dontsovcmc, 2024-12-11:
Хорошая статья про энергоэффективность плат на ESP32
https://diyi0t.com/reduce-the-esp32-power-consumption/

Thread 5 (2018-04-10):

i2c шум

dontsovcmc, 2018-04-10:
Длинные посылки оканчиваются FF FF FF.
Вероятные причины:
1) каллибровка Attiny85
2) уход частоты из-за 1мгц и напряжения (протестировать)
3) плохая библиотека (скорость нельзя поменять)
4) ESP

Исправления:
1) Попробовать https://github.com/rambo/TinyWire
2) Сделать общение с Arduino, посмотреть, как она опрашивает.
3) уменьшить скорость i2c (с другой уже библиотекой)

http://www.engbedded.com/fusecalc/

dontsovcmc, 2018-04-14:
https://github.com/rambo/TinyWire/issues/42
https://github.com/puuu/USIWire/issues/8 - посоветовали уменьшить скорость. Оказалось , можно в i2c master выбрать желаемую скоростью... =)
66000
33000
20000
улучшили количество принимаемых байт ,но картина все равно печальная - надо вводить crc и может быть повтор посылки =(

dontsovcmc, 2018-04-15:
roadmap отладки:

1.[Библиотека i2c для ESP8266 поддерживает не все скорости.](https://github.com/esp8266/Arduino/issues/2524):
[Текущая версия](https://github.com/esp8266/Arduino/blob/2105b8b06fef3e155dcdb775436ca1f77dccd586/cores/esp8266/core_esp8266_si2c.c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): меньше 100кгц только 50кгц

2. Есть функция [setClockStretchLimit](https://github.com/esp8266/Arduino/issues/3977)() по умолчанию 230.  В баг репортах народ до 2000 поднимал для связи с железками.

3. эти ребята [что-то поправили ](https://github.com/enjoyneering/ESP8266-I2C-Driver)в i2c. протестируем.

4. быстрый i2c на ассемблере. может заработает. https://github.com/pasko-zh/brzo_i2c

5. тут явно пишут, что поддерживают медленный i2c: https://github.com/Seeed-Studio/Arduino_Software_I2C

6. и тут https://github.com/felias-fogg/SlowSoftI2CMaster

dontsovcmc, 2018-04-17:
с setClockStretchLimit(1500) уже сутки 100% связь. 40 попыток.

dontsovcmc, 2018-04-18:
80 раз нормально, потом опять Attiny85 перестал отвечать по i2c

dontsovcmc, 2018-05-08:
setClockStretchLimit(1500) убрала шум из i2c!

Closed 2018-05-08.

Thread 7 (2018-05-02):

ESP8266 wakeup time

dontsovcmc, 2018-05-02:
This is wake up by EN_CH: 2.6 sec
```
rl␀l��|␀�l�|␂␌␌␌�␌l�␌b|��␂�␒�r�bl␌b��nn�lnn���␌b␜p��lrlrlp�n�␐␂␌␌�␌l␌��␌␌␌b␌n�|␂l�␌␌�b��nn�␀l��l`␂�␒␒nn␌l`␂␎␂nr���n␌␌b␌�␎l␎r��n␌␌b␌�␎l���␒b�␒␒l`␂��n�␂000:00:00:00:055  NOTICE    (ESP) : Booted
000:00:00:00:056  NOTICE    (WIF) : Config loaded: IP=192.168.1.192, Subnet=255.255.255.0, Gw=192.168.1.1, Remote IP=1.1.1.1, Remote Port=5002
000:00:00:00:061  NOTICE    (WIF) : Device Id=11111, password=1111
000:00:00:00:067  NOTICE    (WIF) : Starting Wifi
000:00:00:00:072  NOTICE    (WIF) : Wifi status: 6
.....
000:00:00:02:387  NOTICE    (WIF) : Wifi status: 6
000:00:00:02:437  NOTICE    (WIF) : Wifi connected, got IP address: 192.168.1.192
000:00:00:02:437  NOTICE    (ESP) : Wifi-begined
000:00:00:02:437  NOTICE    (ESP) : I2C-begined
000:00:00:02:442  ERROR     (I2C end) : 2
000:00:00:02:447  ERROR     (I2C) : requestFrom failed
....
000:00:00:02:484  ERROR     (I2C) : requestFrom failed
000:00:00:02:489  NOTICE    (Stat: bytesReady) : 65535
000:00:00:02:494  NOTICE    (Stat: voltage) : 65535
000:00:00:02:499  CRITICAL  (I2C) : Slave is returning too much data
000:00:00:02:505  NOTICE    (WIF) : Making TCP connection to 1.1.1.1, Port 5002
000:00:00:02:559  NOTICE    (WIF) : Sending 14 bytes of data
000:00:00:02:560  NOTICE    (WIF) : Data sent successfully
000:00:00:02:661  ERROR     (I2C end) : 2
000:00:00:02:662  NOTICE    (ESP) : Going to sleep
```

This is wake up from deep sleep:  0.7 sec
```
rl␀l��|␀�l�|␂␌␌␌�␌l�␌b|��␂�␒�r�b�␌b��nn�lnn���␌b␜p��lrlrlp�n�␐␂␌␌�␌l␌��␌␌␌b␌n�|␂l�␌␌�b��nn�␀l��l`␂�␒␒nn␌l`␂␎␂nr���n␌␌b␌�␎l␎r��n␌␌b␌�␎l���␒b�␒␒l`␂��n�␂000:00:00:00:202  NOTICE    (ESP) : Booted
000:00:00:00:202  NOTICE    (WIF) : Config loaded: IP=192.168.1.192, Subnet=255.255.255.0, Gw=192.168.1.1, Remote IP=1.1.1.1, Remote Port=5002
000:00:00:00:208  NOTICE    (WIF) : Device Id=11111, password=1111
000:00:00:00:214  NOTICE    (WIF) : Starting Wifi
000:00:00:00:220  NOTICE    (WIF) : Wifi status: 6
....
000:00:00:00:524  NOTICE    (WIF) : Wifi status: 6
000:00:00:00:574  NOTICE    (WIF) : Wifi connected, got IP address: 192.168.1.192
000:00:00:00:574  NOTICE    (ESP) : Wifi-begined
000:00:00:00:575  NOTICE    (ESP) : I2C-begined
000:00:00:00:587  NOTICE    (Stat: bytesReady) : 44
000:00:00:00:587  NOTICE    (Stat: voltage) : 2873
000:00:00:00:588  NOTICE    (I2C) : Polling slave for 44 bytes
000:00:00:00:671  NOTICE    (I2C) : Data retreived
000:00:00:00:671  NOTICE    (WIF) : Making TCP connection to 1.1.1.1, Port 5002
000:00:00:00:719  NOTICE    (WIF) : Sending 58 bytes of data
000:00:00:00:720  NOTICE    (WIF) : Data sent successfully
000:00:00:00:723  NOTICE    (ESP) : Going to sleep
```

dontsovcmc, 2018-05-03:
20mkA ESP deepsleep  ~ 1 second ESP work. It is more good to turn off ESP between rare working

Closed 2018-05-03.

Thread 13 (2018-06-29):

English please???

nardev, 2018-06-29:
Hello,

it looks like i have same meter. I would love to see this project translated and if possible, little bit about how the measuring is being done.

can we expect that soon?

dontsovcmc, 2018-06-29:
Thanks for you interest!

Quick info:

This is impulses counter for water meters or same devices that transmitts current values through WiFi to Blynk.cc mobile application or you own TCP server.
It consists from Attiny85 and ESP8266-01.

Current when counting 15-25uA. When transmitting 80mA for ~5sec.

Press button to setup Wi-Fi settings.
ESP starts access point with ip 192.168.4.1
Write your wifi title and password, static ip (i don't use dhcp for fast connect), you router ip and etc.

nardev, 2018-06-29:
Thnx,

is it related in any way with "M-Bus cyble"?

dontsovcmc, 2018-06-29:
It connects to water meters by "dry contact" or discrete output. Every 10 litres contacts closed = 1 impuls.

nardev, 2018-06-29:
I understand, i just read some about "M-Bus" looks like similar purpose, but completely differently defined protocol. This is the one i have: https://www1.itron.com/local/Poland%20Product%20Portolio/GA-CYBLEMBUSSTD-01-EN-10-14.pdf

dontsovcmc, 2018-06-30:
You want to read meter data from M-bus protocol and transmit it through Wi-Fi?
You should find M-bus library for ESP8266. ESP8266 can be in sleep mode (10uA) and wake up every 30 min (AA batteries live ~3 month), or turned off by external chip (you can find external timers for this aims).

nardev, 2018-06-30:
That about sleep mode and ESP is all fine, but i have no idea about m-bus. So far i only found two, old and not so well documented projects about this. Unfortunately i can't find some simplified docs about m-bus.

At first sight i thought this is m-bus project so i run to ask few questions.

Anyway, thank you very much.

p.s. here is what concerns me: [here](https://github.com/rscada/libmbus/issues/139)

Closed 2018-07-17.

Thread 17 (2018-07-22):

Плата: исправления

dontsovcmc, 2018-07-22:
1. вынести U3 над разъемом
2. добавить текст с выводами над/под разъемом ESP
3. исправить C2, R4

dontsovcmc, 2018-07-30:
4. Исправить на схеме напряжение стабилизатора

IvKovalenko, 2018-07-31:
Исправил всё.

Closed 2018-08-05.

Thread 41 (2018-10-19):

Вотериус 1.5 - STM Resurection

dontsovcmc, 2018-10-19:
Плюс от использования STM8:
- уместимся в батарейном блоке при 3*АА.
- добавим датчик протечек или еще 2 входа на выбор (в хвост платы должны влезть)
- главный конкурент Саурес сделан на STM8 ))

На этом плюсы заканчиваются...
Да, ESP32 потребует для себя 2 слота АА, можно запитать от 2*АА литиевых (150р/шт). Без стабилизатора. Упрощение конструкции.

Согласно [обзору STM8](https://www.terraelectronica.ru/news/5482) нам подходит этот: [STM8L051F3](https://docs-europe.electrocomponents.com/webdocs/1285/0900766b8128502b.pdf) на 20 пин. Можно взять и на 8 пин, но лучше больше, чтобы подключить датчик протечки и дополнительные входы.
PlatformioIO еще не поддерживает STM8L =(

dontsovcmc, 2018-10-29:
https://www.aliexpress.com/item/Atmosphetic-Air-Pressure-Sensor-BMP280-chip-and-height-module-STM8L051F3-chip-WT-BMP280/32901774427.html
https://www.chipdip.ru/product/stm8l051f3p6
https://www.aliexpress.com/item/STM8L051F3-Development-Board-Core-Board-Low-Power-Consumption-0-35uA-One-Button-Burning/32919982547.html

dontsovcmc, 2018-11-16:
Ну нафиг =). Пока не появится нормальных фреймворков, смысла нет переходить.

Для дополнительных пинов можно использовать: Attiny84.
#if defined(__AVR_ATtiny84__)
	#define WDTCR WDTCSR
#endif
и всё должно заработать.

Кто хочет покопаться с STM8, напишите дам платы.

Closed 2018-11-16.

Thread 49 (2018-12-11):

2-й запуск настройки - не подключится к предыдущему wi-fi

dontsovcmc, 2018-12-11:
Это ошибка в библиотеке WiFiManager.
Вы 1-й раз настроили Wi-Fi, подключились - ок.
Если 2-й раз запустить настройку Wi-Fi и ввести то же имя сети&пароль (но можно и не вводить, он помнит), то ESP не подключится к той же сети Wi-Fi (светодиод не погаснет).
Новые настройки при этом не сохраняться =(.

Как вариант - можно использовать ветку development, а не waterius_release в репозитории WiFiManager.

dontsovcmc, 2019-02-07:
Кажется исправили. Надо протестировать.
https://github.com/tzapu/WiFiManager/issues/782#issuecomment-461265011

dontsovcmc, 2019-04-02:
Ошибка была в esp8266 Arduino framework.
В следующем релизе будет исправлено! =)

dontsovcmc, 2019-05-19:
Вышла новая версия Arduino 2.5.1. https://github.com/esp8266/Arduino/releases/tag/2.5.1
Platformio поддерживает с 2.1.1: https://github.com/platformio/platform-espressif8266/releases/tag/v2.1.1

Надо протестировать.

dontsovcmc, 2019-09-15:
Исправлено

Closed 2019-09-15.

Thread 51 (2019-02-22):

Подключение датчика протечки

OloloevReal, 2019-02-22:
Добрый день!

Возможно предусмотреть на новой ревизии платы место под установку компонентов для подключения датчика протечки к пину RESET?

Например вот так:
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

- Добавить пин GND для подключения непосредственно датчика к RESET/GND
- Добавить ограничивающий резистор R12 в цепь датчика
- Добавить джампер или DIP свитч для отключения pullup резистора R5 от RESET Pin. При прошивки Fuse RSTDISBL он становится лишним

OloloevReal, 2019-02-22:
Пробовал совместно с R5 отключать и C3, но плата ведет себя не стабильно - перезагружается при касании RESET. В МК понимаю чуть больше чем ничего, но думал что при прошивки RSTDISBL в нем необходимость так же отпадет

dontsovcmc, 2019-02-22:
RESET не получится задействовать, т.к. он "не ресетом" может быть до половины уровня питания. Т.е. слишком "скользкое" решение будет. Гораздо проще и лучше заменить attiny85 на attiny84! https://github.com/dontsovcmc/waterius/issues/41#issuecomment-439402464
Надо только плату перерисовать. Вы сможете с этим помочь?
Я сейчас заказал 2ю версию платы, чтобы она по длине как АА был - меньше резать корпус. Вот на ее основе можно развести дорожки под attiny84, добавив разъем для протечки.

OloloevReal, 2019-02-22:
У меня с датчиком на RESET работает, пока без замечаний.
Хотел попробовать сделать с attiny84, никакой мороки с HVProg, но не нашел их в свободной продаже

dontsovcmc, 2019-02-22:
Ого! Крутяк! А какое сопротивление при затоплении водой датчика? Как часто проверяете его? Это же чтение аналогового входа, значит и компаратор надо включать при пробуждении? 8 раз в секунду проверять смысла нет... раз в минуту бы хорошо.

Смотрите, то, что плата перезагружается от касания - это более чем нормально и штатно. Т.к. она работает в deep sleep и потребляет <10мкА, то любое внешнее воздействие, а особенно человеком - электрошокер для нее. Но конденсатор отключать плохо, он нужен как раз для стабильности. Резистор от reset можно отключить в принципе. Он рекомендательный.

А код покажете? Может сделать отдельную ветку под датчик протечки?

p.s. в blynk передается кол-во перезагрузок и причина последней перезагрузки.

OloloevReal, 2019-02-23:
Сопротивление получается что-то около ~50 кОм + защитный резистор

Компаратор как я понял из кода выключен почти все время что бы уменьшить потребление, поэтому сделал вот так:

```
	pinMode(INPUT2_PIN, INPUT_PULLUP);
	delayMicroseconds(5000); //Charging C2, 5ms
	uint8_t waterSensorState = digitalRead(INPUT2_PIN);
	pinMode(INPUT2_PIN, INPUT);
```

На самом деле не до конца понимаю почему происходит переключение уровней, по спецификации при питании от 3V низким уровнем считается напряжение ниже 0.9V, а 50кОм такого падения не дадут.

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

Опрос сенсора вставил в основной цикл, каждые ~7-8 секунд, плюс защита от ложных срабатываний

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

dontsovcmc, 2019-02-23:
Вот тут другая версия даташита... https://electronics.stackexchange.com/questions/195146/use-the-reset-pin-on-attiny85-as-input-with-voltage-divider в конце документа обычно указывают версию и изменения.

PULLUP резистор 47к, поэтому получается 0.5*3v = 1.5v на входе - 0.
Во-первых, резистор 47к можно установить штатно - его нет на входах счетчика, т.к. счетчики могут остановится в момент замыкания входа и будет высокое потребление. Для датчика протечки это не актуально - протечка нештатное событие и длится конечный период. Значит, если я правильно понял, можно убрать `delayMicroseconds(5000);`

Я не пойму, а почему 3к3 вы на GND подключили, а не на вывод датчика к Reset?

Я давно читал даташит, напомните мне и читателям, почему от протечки не перезагружается attiny85?

OloloevReal, 2019-02-23:
> Я давно читал даташит, напомните мне и читателям, почему от протечки не перезагружается attiny85?

Прошит Fuse RSTDISBL

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

avrdude -p t85 -c linuxspi -b 16000 -B 4 -P /dev/spidev0.0 -U efuse:w:0xFF:m -U hfuse:w:**0x5F**:m -U lfuse:w:0x62:m

После этого, перепрошить attiny можно будет только сбросив фьюзы высоковольтным программатором. [https://habr.com/ru/post/249967/](url)

dontsovcmc, 2019-02-25:
Отлично! Но, все равно Attiny85 перезагружается если пальцем теребонькать пин, верно?

А как выглядит сам датчик протечки? Я видел несколько вариантов в энторнетах... Я предполагаю, что  самый простой способ - вытравить змейку на плате, но надо чем то покрыть от коррозии. Есть готовое что-то?

Если сделать чтение аналогового сигнала - это позволит разместить на датчике резистор для детектирования разрыва связи с ним! Если не делать, то можно на датчик припаять кнопку "ТЕСТ"+резистор50к и проверить при установки, что всё ОК.

OloloevReal, 2019-02-25:
> Отлично! Но, все равно Attiny85 перезагружается если пальцем теребонькать пин, верно?

Нет, не перезагружается, работает стабильно, конденсатор С2 сглаживает всплески от касаний. Но для его зарядки приходится вставлять паузу delayMicroseconds(5000); перед digitalRead(INPUT2_PIN);

Из готовых датчиков должен подойти WSP [https://gidrolock.ru/production/datchiki-protechki-vody-gidrolock/](url)

Пробовал делать с аналоговым чтением, но так до конца и не разобрался, у меня после нескольких циклов чтения analogRead() получались одни и те же значения = 338, как будто ADC зависал или выключался. Как правильно разбудить attiny включить и настроить adc курить даташит надо

dontsovcmc, 2019-02-25:
> Но для его зарядки приходится вставлять паузу delayMicroseconds(5000); перед digitalRead(INPUT2_PIN);
Так я предлагаю впаять между RESET и Vcc резистор на 50к.

> WSP хех 500руб =). да, позолоченные контакты норм.
ого! У них заключение от [renata](https://gidrolock.ru/uploads/Lifetime%20calculation_Scanti_2450N_Gidrolock_130628.pdf) о работе их датчиков беспроводных. 2.5мкА - очень не дурно.

> Пробовал делать с аналоговым чтением, но так до конца и не разобрался

Так, нужен большой резистор параллельно датчику ~200к между RESET - GND

Алгоритм:
```
unsigned int check_leak_level(uint8_t pin)
{
unsigned int level = 0;
adc_enable();
pinMode(INPUT_PULLUP, LEAK_PIN);
//нужно ждать зарядки конденсатора, если параллельно ему теперь резисто?
level = analogRead(LEAK_PIN);
adc_disable();
return level;
}

unsigned int noleak_value;

в setup()
noleak_value = check_leak_level(LEAK_PIN) - SOME_VALUE; //запоминаем текущий уровень + чуток отступить
```

в цикле опроса:
```
я бы добавил проверку 1 раз в минуту [сюда](https://github.com/dontsovcmc/waterius/blob/master/Attiny85/src/main.cpp#L169)

info.leak = check_leak_level(LEAK_PIN) < noleak_value;
if (info.leak) {
    break;
}
```

OloloevReal, 2019-03-05:
Остановился пока на такой реализации:
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

При погружении в воду ток через датчик протекает 0.02mA, на входе RESET напряжение падает с 3.15 до 0.5В (в схеме стоит стабилизатор на 3.3В, что был в наличии)

Соответственно всякие задержки на зарядку C3 можно убрать, оставив только

```
        #define INPUT2_PIN  5

        pinMode(INPUT2_PIN, INPUT);
	uint8_t waterSensorState = digitalRead(INPUT2_PIN);
```
Сенсор наколхозил из того что было в леруамерлен:
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

dontsovcmc, 2019-03-05:
Очень круто!! Мои поздравления! И конструкция датчика вдохновляет!
Хм. А входы разве не 1-2 ? )
Я закину фото в https://www.facebook.com/waterius?

OloloevReal, 2019-03-05:
> Я закину фото в https://www.facebook.com/waterius?

Конечно

OloloevReal, 2019-04-09:
В коллекцию фотографий, готовый комплект для установки в квартиру с двумя стояками

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

dontsovcmc, 2019-04-10:
Ваааау! Класс!
Я сейчас НАМУР добавляю и упрощаю интерфейс настройки. Придумал показывать в вебморде, Есть ли связь со счетчиками - у кого контакты в пыли или плохо всовываются актуально.

dontsovcmc, 2019-04-10:
@OloloevReal  кстати , под датчик протечки можно Eventor использовать - Push уведомление.
Я планирую добавить вашу схему в новую версию платы. А, кстати, analogRead возможен для reseta? Я исследовал время опроса - analogRead лишь чуть чуть медленнее digitalRead.

Xa6ep, 2019-12-07:
> В коллекцию фотографий, готовый комплект для установки в квартиру с двумя стояками
>
> 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

А можно фото платы? Хочется понять как вы разводили это на плате. R12 наверное в корпус самого датчика можно засунуть...

OloloevReal, 2019-12-22:
Уф, пришлось опять лезть в сантехнишу что бы вспомнить что и как переделывал
Итого: R5 заменен на 210k, а R12 нет, использую землю GND1.

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

Белый герметик для фиксация кабеля.

PS. При таком использовании прошивка ATtiny будет не возможна без высоковольтного программатора, это важно.

dontsovcmc, 2019-12-22:
@OloloevReal а в прошивке опрос PB5 как обычного INPUT? ну и пробуждение по замыканию, верно?

OloloevReal, 2019-12-22:
Так точно

```
#define INPUT2_PIN  5

pinMode(INPUT2_PIN, INPUT);
uint8_t waterSensorState = digitalRead(INPUT2_PIN);
```

dontsovcmc, 2021-11-09:
Появилась идея - подключать датчик протечки параллельно счётчику воды (если он ГЕРКОН).
Минусы:
 нельзя будет детектировать короткое замыкание, но вроде это совсем исключительная ситуация.
 не сделать поддержку НАМУР, потому что "протечка" бывает разного сопротивления.

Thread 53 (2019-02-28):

Добавить температуру/давление в Вотериус

dontsovcmc, 2019-02-28:
Для этого, либо каждый раз просыпаться, что не экономично, либо записывать данные в кольцевой буфер. Буфер есть, надо только начало и конец отмечать. +вернуть код, взятый за основу, когда по i2c передавали вектор значений.

Существенно расшириться сфера применения Вотериуса!

Пример датчика:
https://www.banggood.com/CJMCU-75-LM75A-I2C-Temperature-Sensor-Development-Board-Module-p-987306.html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

dontsovcmc, 2019-03-27:
Датчик мечты: https://cdn-shop.adafruit.com/datasheets/1899_HTU21D.pdf

dontsovcmc, 2019-05-18:
В attiny85 есть температурный датчик, но он тоже от 1.1В зависит, т.е. будет не точным
https://www.avrfreaks.net/forum/attiny85-temp-sensor

Closed 2019-12-30.

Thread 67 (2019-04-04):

Поддержка NAMUR (Намур)

dontsovcmc, 2019-04-04:
1. Можно поддержать НАМУР без изменения в схемотехнике!

analogRead:

1. Последовательно с счетчиком 2.2к, пин с GND 5.6к.
2. Включаем PULLUP при замере

Замкнут 56
Разомкнут 146
Обрыв 1000

В Ватериусе будут другие цифры, т.к. там еще + 3к3 на входе.

2. Т.к. НАМУР без изменения в схемотехнике - это чтение аналогового входа, то это существенно замедлит цикл чтения (в 7 раз против текущего), который длится много раз в секунду. Точное изменение энергии я смогу замерить позже.

Я провел тесты с Nano 16MGh, чтобы посмотреть на разницу между функциями Ардуино и работы с битами. На дискретных входах разница до 7 раз (!). На аналоговом входе разницы почти нет.

Результаты тестов:

digitalRead, 1 pin, 89840
digitalRead, 2 pins, 35181
битами digital, 1 pin, 269510
битами digital, 2 pins, 248400
analogRead, 1 pin, 4770
analogRead, 2 pins, 3103
битами analog аналогичные значения

Ватериус на частоте 1МГц работает, поэтому цифры будут другие. Кстати, если цифры будут отличаться в 8 раз для частоты 8МГц, то стоит ее поднять (потребление в 4 раза выше).

```
#include <Arduino.h>

/*
  Тестируем скорость работы портов за 1 секунду
  Arduino Nano 16Mhz, 5V (atmega328p)
*/

#define adc_disable() (ADCSRA &= ~(1<<ADEN)) // disable ADC
#define adc_enable()  (ADCSRA |=  (1<<ADEN)) // re-enable ADC

#define INPUT1 A2
#define INPUT2 A3

unsigned long t = 0;
unsigned long count = 0;

int i = 0;
uint16_t result = 0;

void setup() {
  Serial.begin(9600);

}

void loop() {

  t = millis();
  count = 0;
  while (millis() - t < 1000) {

// ДИСКРЕТНЫЙ ВХОД

/*
    //89840 1 вход
    //35181 2 входа

    pinMode(INPUT1, INPUT_PULLUP);
    pinMode(INPUT2, INPUT_PULLUP);
    i = digitalRead(INPUT1);
    i = digitalRead(INPUT2);
    pinMode(INPUT1, INPUT);
    pinMode(INPUT2, INPUT);
*/

/*
    //269510  1 вход
    //248400  2 входа

    //A2 = PC2
    DDRC &= ~_BV(2);  PORTC |= _BV(2);  // INPUT_PULLUP
    i = bit_is_clear(PINC, 2);
    DDRC &= ~_BV(2);  PORTC &= ~_BV(2); //INPUT

    //DDRC &= ~_BV(2);  можно вынести в setup и
    //тогда скорость будет
    //265000 2 входа !!!
*/

// АНАЛОГОВЫЙ ВХОД
/*
    //4726 раз при
    adc_enable();
    pinMode(INPUT1, INPUT_PULLUP);
    int i = analogRead(INPUT1);
    pinMode(INPUT1, INPUT);
    adc_disable();

*/

 /*
    //4770  1 аналог. вход
    //3103  2 аналог. вход
    //A2 = PC2
    //A3 = PC3
    DDRC &= ~_BV(2);  PORTC |= _BV(2);  // INPUT_PULLUP
    DDRC &= ~_BV(3);  PORTC |= _BV(3);  // INPUT_PULLUP

    ADMUX = _BV(REFS0); // Select Vref=AVcc  https://embedds.com/adc-on-atmega328-part-1/
    ADCSRA |= (1<<ADPS2)|(1<<ADPS1)|(1<<ADPS0); //set prescaller to 128 and enable ADC

    adc_enable();

    //ADC3
    ADMUX = (ADMUX & 0xF0) | (3 & 0x0F);
    ADCSRA |= _BV(ADSC); // Start conversion
    while (bit_is_set(ADCSRA,ADSC)); // measuring

    uint8_t low  = ADCL; // must read ADCL first - it then locks ADCH
    uint8_t high = ADCH; // unlocks both

    result = (high<<8) | low;

    //ADC2
    ADMUX = (ADMUX & 0xF0) | (2 & 0x0F);

    ADCSRA |= _BV(ADSC); // Start conversion
    while (bit_is_set(ADCSRA,ADSC)); // measuring

    low  = ADCL; // must read ADCL first - it then locks ADCH
    high = ADCH; // unlocks both

    result = (high<<8) | low;

    //Выключаем ADC
    adc_disable();

    //A2 = PC2
    DDRC &= ~_BV(3);  PORTC &= ~_BV(3); //INPUT
    DDRC &= ~_BV(2);  PORTC &= ~_BV(2); //INPUT

*/
  /*
    Serial.println(result);
    delay(100);
  */

  // ---------
    count++;
  }

  Serial.println(count);

  delay(500);
}
```

dontsovcmc, 2019-04-14:
0.7 сделал. опрос analogRead.

Closed 2019-04-14.

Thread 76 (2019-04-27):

Намур (Берегун)

OloloevReal, 2019-04-27:
Добрый день!

При подключении счетчика ГВС Берегун обнаружил проблему

При нажатии на кнопку происходит изменение величины считываемой со входов. Например, если состояние входа NAMUR_CLOSED, в моем случае значение 149, и происходит нажатие кнопки, то значение на входе изменяется со 149 на 224

```
12437 [D]: 149
12437 [D]: 149
12437 [D]: 224 <- изменение, фактически NAMUR_CLOSED -> NAMUR_OPEN
37883 [I]: Data:
37910 [I]: 13
37933 [I]: 0
```
Это приводит к ложным увеличениям счетчика импульсов, т.е. при каждой принудительной отправке показаний кнопкой происходит +1 счетчика.

dontsovcmc, 2019-04-27:
Вау! Да, не протестировал "в поле".
Выставите LIMIT_NAMUR_CLOSED 210.

OloloevReal, 2019-04-27:
Да, та кнопка что для отправки/настройки

Если вот сюда вставить дебаг, то при нажатии кнопки будет видно что считываемое значение увеличится
```
    bool is_close()
    {
        //bool value = digRead();
        //state = value2state(value ? 1024 : 0);
        uint16_t value = aRead();
        LOG_DEBUG(value);
        state = value2state(value);
        return state == CounterState_e::CLOSE || state == CounterState_e::NAMUR_CLOSE;
    }
```

Временно вышел из положения таким образом:

```
inline void counting() {

    power_adc_enable(); //т.к. мы обесточили всё а нам нужен компаратор
    adc_enable();       //после подачи питания на adc

	if(button.digBit() == LOW){
		adc_disable();
    	        power_adc_disable();
		LOG_DEBUG(F("Skip!"));
		return;
	}
.....
```
Т.е. откидывая значение если кнопка нажата перед чтением данных со входов.

Мне кажется это как-то связанно с тем что контроллер находится power save, а нажатие кнопки просаживает напряжение

dontsovcmc, 2019-04-28:
Хм... Не понимаю. Это же разные пины и они не должны влиять друг на друга.

1. Странно, что лог работает, мне казалось LOG_BEGIN всегда после пробуждения нужно делать.
2. А как увеличивается значение value? Оно всегда плавает - это же компаратор от 0 до 1023.
```
uint16_t value = aRead();
LOG_DEBUG(value);
```

3. А можете протестировать вызов counting() в условии, вместо изменения ее содержимого:
```
		while ( wdt_count > 0 ) {
			noInterrupts();

			if (button_pressed()) {
				interrupts();  // Пользователь нажал кнопку
				break;
			} else 	{
			        counting(); //Опрос входов
				interrupts();
				sleep_mode();  // Спим (WDTCR)
			}
		}
```

OloloevReal, 2019-04-29:
> А как увеличивается значение value? Оно всегда плавает - это же компаратор от 0 до 1023.

При постоянном значении нагрузки на входах значение плавает +- 1
А вот так оно меняется при нажатии на кнопку:
0:             109 -> 188
1.6 кОм:  143 -> 220
5.6 кОм:  221 -> 290
обрыв:    1020 -> 1023

> А можете протестировать вызов counting() в условии, вместо изменения ее содержимого:

С таким кодом работает корректно, ложных срабатываний не фиксируется
```
23803 [D]: 143
23803 [D]: 143
23803 [D]: 143
23803 [D]: 143
23803 [D]: 143
23803 [D]: 143
23803 [D]: 143
23803 [D]: 143
23803 [D]: 143
23803 [D]: 143
23803 [D]: 143
23803 [D]: 143
23803 [D]: 143
23808 [I]: Data:
23832 [I]: 4
23853 [I]: 0
24379 [D]: wake up for transmitting

```

dontsovcmc, 2019-05-04:
ААААА! Нашел ошибку!
Теперь counting() нужен Компаратор, а он выключается в функции readVcc!
И поэтому после каждой отсылки может быть дополнительный +10л..

dontsovcmc, 2019-05-04:
Я сейчас попробовал у себя - у меня вообще нет этой ошибки.. Придется вам код показать, а то не ясно, что вы переделали =(

dontsovcmc, 2019-05-04:
Проверьте, что включен компаратор в том месте. Потому что в readVcc  он выключается и я удивился, когда увидел другое значение сразу после вызова функции.

OloloevReal, 2019-05-04:
Проверяю на v0.8, стоковой версии, все отличия это активированный лог, уменьшенный таймер  #define WAIT_ESP_MSEC    5000UL и добавленный принтаут в функцию is_close()
Записал лог, в нем видно что при нажатии кнопки посылки показаний происходит скачек значения и счетчик импульсов увеличивает значение

ESP отключена, нагрузка на Input_0 подключена 1.6 кОм
[log.log](https://github.com/dontsovcmc/waterius/files/3144590/log.log)

OloloevReal, 2019-05-04:
Пробовал убирать из кода запрос напряжения
`//info.voltage = readVcc();   // Текущее напряжение`
ни на что не повлияло, проблема сохраняется

dontsovcmc, 2019-05-04:
Упс. WAIT_ESP_MSEC надо вернуть.
Я вставляю печать в is_close  и нет никакой разницы в показаниях. Т.е. кнопка нажата,нет. Нет разницы.
У вас она есть. пришлите кусок кода где вы нажимаете кнопку, пожалуйста.

OloloevReal, 2019-05-04:
WAIT_ESP_MSEC ставлю небольшим значением что бы проблему отлавливать быстрее - проблема проявляется когда Attiny в повер сейве и выходит из него. Если она уже проснулась, и например, ждет ESP, то жми, не жми кнопку результат стабильный, изменений не происходит.

Вот все изменения сделанные поверх master версии, все сток [diff ](https://gist.github.com/OloloevReal/df41f2b75453a0c0729c97dfdeea40bf)

dontsovcmc, 2019-05-04:
да, да. я также сделал. у меня нет разницы в aRead(). Слушайте, а на плате у вас нет замыкания какого-нибудь? Ну если код одинаковый, МК тоже, то только плата осталась...

OloloevReal, 2019-05-05:
Не похоже на замыкание, померил ток:
0.01 mA - power save
1.56 mA - кнопка нажата, attiny проснулась и ждет ESP

Очень странно, ладно, видимо нужно собирать еще одну тестовую плату, на новом МК

dontsovcmc, 2019-05-05:
Второй человек сегодня отписал об этой проблеме... Мне не сложно перенести counting() в условие, но это костыль, а нужно понять причину.
Я смотрел в сторону AREF - опорное напряжение компаратора, но этот пин SDA, а кнопка замыкает SLK.

dontsovcmc, 2019-05-05:
о! я проверял без ESP всунутой. А ведь она может как-то влиять. У вас ошибка без ESP воспроизводится?

OloloevReal, 2019-05-05:
Я проверяю без ESP, ошибка воспроизводится без ESP

dontsovcmc, 2019-05-06:
> Я проверяю без ESP, ошибка воспроизводится без ESP

И ошибка будет только если замкнут НАМУР?

dontsovcmc, 2019-05-19:
Оставил пока так:
```
{
interrupts();  // Пользователь нажал кнопку
break;
} else {
    counting(); //Опрос входов
    interrupts();
    sleep_mode();  // Спим (WDTCR)
}
```

Closed 2019-05-19.

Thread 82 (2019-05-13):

Если после настройки делать HTTPS - падение

dontsovcmc, 2019-05-13:
Хочу переделать, так, чтобы после успешной настройки показания сразу улетали на сервер.
Столкнулся с тем, что не хватает памяти. Падение в вызове new в недрах SSL.

Вопрос: как очистить память после работы WiFi точки доступа?
Вряд ли библиотеку BearSSL можно оптимизировать.

```
Включение без настройки
000:00:00:03:600  NOTICE    (MQT) : heap1=32672
000:00:00:03:604  NOTICE    (MQT) : stack1=2640
000:00:00:03:608  NOTICE    (SND) : -- START -- Send new data
000:00:00:03:615  NOTICE    (MQT) : heap2=32440
000:00:00:03:618  NOTICE    (MQT) : stack2=2160
ОК

000:00:00:03:599  NOTICE    (MQT) : heap1=32672
000:00:00:03:603  NOTICE    (MQT) : stack1=2640
000:00:00:03:608  NOTICE    (SND) : -- START -- Send new data
000:00:00:03:614  NOTICE    (MQT) : heap2=32440
000:00:00:03:617  NOTICE    (MQT) : stack2=2128
ОК

После настройки
000:00:00:34:722  NOTICE    (MQT) : heap1=29224
000:00:00:34:726  NOTICE    (MQT) : stack1=1760
000:00:00:34:730  NOTICE    (SND) : -- START -- Send new data
000:00:00:34:737  NOTICE    (MQT) : heap2=28992
000:00:00:34:740  NOTICE    (MQT) : stack2=1760
падение

Поменял JSON на DynamicJson 1024

000:00:00:03:599  NOTICE    (MQT) : heap1=32672
000:00:00:03:603  NOTICE    (MQT) : stack1=2640
000:00:00:03:608  NOTICE    (SND) : -- START -- Send new data
000:00:00:03:614  NOTICE    (MQT) : heap2=32440
000:00:00:03:617  NOTICE    (MQT) : stack2=2160
падение

000:00:00:48:134  NOTICE    (MQT) : heap1=29144
000:00:00:48:138  NOTICE    (MQT) : stack1=1856
000:00:00:48:143  NOTICE    (SND) : -- START -- Send new data
000:00:00:48:149  NOTICE    (MQT) : heap2=27880
000:00:00:48:152  NOTICE    (MQT) : stack2=1856
000:00:00:48:157  NOTICE    (RQT) : -- START -- Send JSON POST request
000:00:00:48:163  INFO      (RQT) : URL:	https://cloud.waterius.ru
000:00:00:48:169  INFO      (RQT) : Body:	{"delta0":0,"delta1":0,"good":1,"boot":9,"ch0":0.07,"ch1":0.03,"imp0":7,"imp1":3,"version":5,"voltage":2.948,"version_esp":"0.8.2","key":"","resets":1,"email":"@mail.ru"}
000:00:00:48:460  NOTICE    (NTP) : Waiting for NTP time sync:
000:00:00:48:560  NOTICE    (NTP) : Current time: Mon May 13 02:14:44 2019

000:00:00:48:561  INFO      (RQT) : Begin client
000:00:00:48:562  NOTICE    (MQT) : heap3=21960
000:00:00:48:565  NOTICE    (MQT) : stack3=1856
падение

Выключил все сертификаты, кроме 1го

000:00:02:00:155  NOTICE    (MQT) : heap1=29016
000:00:02:00:159  NOTICE    (MQT) : stack1=1556
000:00:02:00:163  NOTICE    (SND) : -- START -- Send new data
000:00:02:00:170  NOTICE    (MQT) : heap2=27752
000:00:02:00:173  NOTICE    (MQT) : stack2=1556
000:00:02:00:177  NOTICE    (RQT) : -- START -- Send JSON POST request
000:00:02:00:184  INFO      (RQT) : URL:	https://cloud.waterius.ru
000:00:02:00:190  INFO      (RQT) : Body:	{"delta0":0,"delta1":0,"good":1,"boot":9,"ch0":0.07,"ch1":0.03,"imp0":7,"imp1":3,"version":5,"voltage":2.948,"version_esp":"0.8.2","key":"","resets":1,"email":"mail.ru"}
000:00:02:00:280  NOTICE    (NTP) : Waiting for NTP time sync:
000:00:02:00:380  NOTICE    (NTP) : Current time: Mon May 13 08:14:56 2019

000:00:02:00:381  INFO      (RQT) : Begin client
000:00:02:00:382  NOTICE    (MQT) : heap3=26400
000:00:02:00:385  NOTICE    (MQT) : stack3=1556

падение
```

стек:
```
Decoding 56 results
0x4021ff50: operator new[](unsigned int) at /workdir/arena/gcc/xtensa-lx106-elf/libstdc++-v3-nox/libsupc++/../../../../../dl/gcc-xtensa/libstdc++-v3/libsupc++/new_opv.cc line 33
0x4020e01f: BearSSL::WiFiClientSecure::_connectSSL(char const*) at ?? line ?
0x402137a8: esp_yield at ?? line ?
0x40201e33: delay at ?? line ?
0x4020cdf9: WiFiClient::connect(IPAddress const&, unsigned short) at ?? line ?
0x4020e236: BearSSL::WiFiClientSecure::connect(char const*, unsigned short) at ?? line ?
0x40217d58: WiFiServer::_s_discard(void*, ClientContext*) at ?? line ?
0x402177c0: HTTPClient::connected() at ?? line ?
0x40210ec8: HTTPClient::connect() at ?? line ?
0x40212a27: String::changeBuffer(unsigned int) at ?? line ?
0x40212a00: String::~String() at ?? line ?
0x402116b0: HTTPClient::sendRequest(char const*, unsigned char*, unsigned int) at ?? line ?
0x40212a27: String::changeBuffer(unsigned int) at ?? line ?
0x40212a73: String::reserve(unsigned int) at ?? line ?
0x40211764: HTTPClient::POST(unsigned char*, unsigned int) at ?? line ?
0x40211782: HTTPClient::POST(String) at ?? line ?
0x40204a4a: WateriusHttps::sendJsonPostRequest(String const&, char const*, char const*, String const&) at ?? line ?
0x40212a27: String::changeBuffer(unsigned int) at ?? line ?
0x40212abc: String::copy(char const*, unsigned int) at ?? line ?
0x40212af2: String::String(char const*) at ?? line ?
0x40203ec9: UserClass::sendNewData(Settings const&, SlaveData const&, CalculatedData const&) at ?? line ?
0x4021a120: _printf_i at /home/earle/src/esp-quick-toolchain/arena/newlib-install/xtensa-lx106-elf/newlib/libc/stdio/../../../../../../dl/newlib-xtensa/newlib/libc/stdio/nano-vfprintf_i.c line 244
0x4026b5e5: sleep_reset_analog_rtcreg_8266 at ?? line ?
0x4021ea17: _svfprintf_r at /home/earle/src/esp-quick-toolchain/arena/newlib-install/xtensa-lx106-elf/newlib/libc/stdio/../../../../../../dl/newlib-xtensa/newlib/libc/stdio/nano-vfprintf.c line 660
0x40212038: HardwareSerial::write(unsigned char const*, unsigned int) at ?? line ?
0x40212335: Print::write(char const*) at ?? line ?
0x40212038: HardwareSerial::write(unsigned char const*, unsigned int) at ?? line ?
0x40265a94: sleep_reset_analog_rtcreg_8266 at ?? line ?
0x40212335: Print::write(char const*) at ?? line ?
0x4021e606: __ssputs_r at /home/earle/src/esp-quick-toolchain/arena/newlib-install/xtensa-lx106-elf/newlib/libc/stdio/../../../../../../dl/newlib-xtensa/newlib/libc/stdio/nano-vfprintf.c line 233
0x4021a020: _printf_i at /home/earle/src/esp-quick-toolchain/arena/newlib-install/xtensa-lx106-elf/newlib/libc/stdio/../../../../../../dl/newlib-xtensa/newlib/libc/stdio/nano-vfprintf_i.c line 194 (discriminator 1)
0x4021e606: __ssputs_r at /home/earle/src/esp-quick-toolchain/arena/newlib-install/xtensa-lx106-elf/newlib/libc/stdio/../../../../../../dl/newlib-xtensa/newlib/libc/stdio/nano-vfprintf.c line 233
0x4021e540: __ssputs_r at /home/earle/src/esp-quick-toolchain/arena/newlib-install/xtensa-lx106-elf/newlib/libc/stdio/../../../../../../dl/newlib-xtensa/newlib/libc/stdio/nano-vfprintf.c line 180
0x4021a120: _printf_i at /home/earle/src/esp-quick-toolchain/arena/newlib-install/xtensa-lx106-elf/newlib/libc/stdio/../../../../../../dl/newlib-xtensa/newlib/libc/stdio/nano-vfprintf_i.c line 244
0x40217d58: WiFiServer::_s_discard(void*, ClientContext*) at ?? line ?
0x4026b5e5: sleep_reset_analog_rtcreg_8266 at ?? line ?
0x40206fe4: send_blynk(Settings const&, SlaveData const&, CalculatedData const&) at ?? line ?
0x40208c50: update_data(String&) at ?? line ?
0x4021ea17: _svfprintf_r at /home/earle/src/esp-quick-toolchain/arena/newlib-install/xtensa-lx106-elf/newlib/libc/stdio/../../../../../../dl/newlib-xtensa/newlib/libc/stdio/nano-vfprintf.c line 660
0x40264c8b: sleep_reset_analog_rtcreg_8266 at ?? line ?
0x402649b4: sleep_reset_analog_rtcreg_8266 at ?? line ?
0x4021a96c: sprintf at /home/earle/src/esp-quick-toolchain/arena/newlib-install/xtensa-lx106-elf/newlib/libc/stdio/../../../../../../dl/newlib-xtensa/newlib/libc/stdio/sprintf.c line 646
0x4021a020: _printf_i at /home/earle/src/esp-quick-toolchain/arena/newlib-install/xtensa-lx106-elf/newlib/libc/stdio/../../../../../../dl/newlib-xtensa/newlib/libc/stdio/nano-vfprintf_i.c line 194 (discriminator 1)
0x4021e606: __ssputs_r at /home/earle/src/esp-quick-toolchain/arena/newlib-install/xtensa-lx106-elf/newlib/libc/stdio/../../../../../../dl/newlib-xtensa/newlib/libc/stdio/nano-vfprintf.c line 233
0x40212038: HardwareSerial::write(unsigned char const*, unsigned int) at ?? line ?
0x40212335: Print::write(char const*) at ?? line ?
0x40212348: Print::print(char const*) at ?? line ?
0x40212a27: String::changeBuffer(unsigned int) at ?? line ?
0x40217d98: WiFiServer::_s_discard(void*, ClientContext*) at ?? line ?
0x40207b4c: loop at ?? line ?
0x40205585: setup at ?? line ?
0x40217d58: WiFiServer::_s_discard(void*, ClientContext*) at ?? line ?
0x40213854: loop_wrapper() at core_esp8266_main.cpp line ?
0x40101511: cont_wrapper at ?? line ?
```

OloloevReal, 2019-05-13:
Можно перезагрузить ESP и затем выполнить отправку

dontsovcmc, 2019-05-13:
Да, но тогда надо слать команду "Restart" в Attiny. Она должна рестартануть в режиме Transmit...
Я еще не пробовал выключать WiFiClient. Не знаете, как грамотно это проделать?

OloloevReal, 2019-05-14:
Решение в лоб,  установить в Attiny режим TRANSMIT_MODE после того как сказали ESP SETUP_MODE

```
		case 'M':  // Разбудили ESP для настройки или передачи данных?
			txBuffer[0] = setup_mode;
			if(setup_mode == SETUP_MODE){
				setup_mode = TRANSMIT_MODE;
			}
			break;

```

dontsovcmc, 2019-05-14:
@OloloevReal может нужно просто ребутнуть WiFi?

Вот вижу доку:
https://arduino-esp8266.readthedocs.io/en/latest/esp8266wifi/soft-access-point-class.html#softapdisconnect

WiFi.softAPdisconnect(true); вызвать надо точно. это выключит веб сервер и отрубит клиентов. возможно уже эта мера очистит память.

может достаточно вызова WiFi.mode(WIFI_STA);  после настройки? Могли бы протестировать?

OloloevReal, 2019-05-15:
Попробовал, никакого толку, куча не уменьшается

```
            //Запускаем точку доступа с вебсервером
            LOG_NOTICE("ESP", "Heap1: " << ESP.getFreeHeap());
            setup_ap(sett, data, cdata);
            LOG_NOTICE("ESP", "Heap2: " << ESP.getFreeHeap());
            WiFi.softAPdisconnect(true);
            LOG_NOTICE("ESP", "Heap3: " << ESP.getFreeHeap());
```

```
000:00:00:00:180  NOTICE    (ESP) : Heap1: 33848
000:00:00:00:185  NOTICE    (ESP) : I2C-begined: mode SETUP
..........
.........
000:00:00:32:293  NOTICE    (AP) : impulses1=0
000:00:00:32:297  NOTICE    (CFG) : Config stored OK
*WM: freeing allocated params!
000:00:00:32:304  NOTICE    (ESP) : Heap2: 28272
000:00:00:32:308  NOTICE    (ESP) : Heap3: 28272
000:00:00:32:813  NOTICE    (WIF) : Starting
000:00:00:32:814  NOTICE    (WIF) : Status: 6
000:00:00:33:014  NOTICE    (WIF) : Connected, IP: 192.168.1.253
```

dontsovcmc, 2019-11-28:
После динамической загрузки SSID сетей, памяти стало больше. Уменьшилась фрагментация:
[MEM] free: 31080 | max: 25648 | frag:  18%

dontsovcmc, 2020-05-02:
Кажется я теряю 4кб памяти не вызывая EEPROM.end() после чтения настроек )

dontsovcmc, 2022-03-30:
Решил тем, что перезапускаю ESP после настройки.

Closed 2022-03-30.

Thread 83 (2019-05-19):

Blynk + HTTPS - return -1

dontsovcmc, 2019-05-19:
Если включить Blynk, MQTT, то после них HTTPS возвращает -1...
upd: После Blynk такая ерунда...
```
 (ESP) : Booted
2 000:00:00:00:055  NOTICE    (I2C) : mode=2
9 1 D3 B 0 0 1 0 1 1 1 0 0 0 3 0 0 0 000:00:00:00:070  NOTICE    (I2C) : version: 9
000:00:00:00:070  NOTICE    (I2C) : service: 1
000:00:00:00:070  NOTICE    (I2C) : voltage: 3027
000:00:00:00:072  NOTICE    (I2C) : resets: 1
000:00:00:00:076  NOTICE    (I2C) : state0: 1
000:00:00:00:080  NOTICE    (I2C) : state1: 1
000:00:00:00:084  NOTICE    (I2C) : impulses0: 1
000:00:00:00:088  NOTICE    (I2C) : impulses1: 3
000:00:00:00:093  NOTICE    (CFG) : CRC ok
000:00:00:00:096  NOTICE    (CFG) : WATERIUS.RU
000:00:00:00:101  NOTICE    (CFG) : email=x@mail.ru
000:00:00:00:106  NOTICE    (CFG) : host=https://cloud.waterius.ru key=x
000:00:00:00:115  NOTICE    (CFG) : BLYNK.CC
000:00:00:00:119  NOTICE    (CFG) : host=blynk-cloud.com key=x
000:00:00:00:128  NOTICE    (CFG) : email=x@mail.ru
000:00:00:00:133  NOTICE    (CFG) : MQTT
000:00:00:00:137  NOTICE    (CFG) : host=broker.hivemq.com port=1883
000:00:00:00:143  NOTICE    (CFG) : login= pass=
000:00:00:00:147  NOTICE    (CFG) : topic=waterius/1234/
000:00:00:00:152  NOTICE    (CFG) : COUNTERS
000:00:00:00:156  NOTICE    (CFG) : channel0_start=0.00, impulses0_start=1, factor=10
000:00:00:00:164  NOTICE    (CFG) : channel1_start=0.00, impulses1_start=3
000:00:00:00:171  NOTICE    (ESP) : new impulses=1 3
000:00:00:00:175  NOTICE    (ESP) : new value0=0.00 value1=0.00
000:00:00:00:181  NOTICE    (ESP) : delta0=0 delta1=0
000:00:00:00:186  NOTICE    (WIF) : Starting
000:00:00:00:191  NOTICE    (WIF) : Status: 6
000:00:00:00:394  NOTICE    (WIF) : Status: 6
000:00:00:00:594  NOTICE    (WIF) : Status: 6
000:00:00:00:795  NOTICE    (WIF) : Status: 6
000:00:00:00:995  NOTICE    (WIF) : Status: 6
000:00:00:01:196  NOTICE    (WIF) : Status: 6
000:00:00:01:396  NOTICE    (WIF) : Status: 6
000:00:00:01:597  NOTICE    (WIF) : Status: 6
000:00:00:01:797  NOTICE    (WIF) : Status: 6
000:00:00:01:998  NOTICE    (WIF) : Status: 6
000:00:00:02:198  NOTICE    (WIF) : Status: 6
000:00:00:02:399  NOTICE    (WIF) : Status: 6
000:00:00:02:599  NOTICE    (WIF) : Status: 6
000:00:00:02:800  NOTICE    (WIF) : Status: 6
000:00:00:03:000  NOTICE    (WIF) : Status: 6
000:00:00:03:201  NOTICE    (WIF) : Status: 6
000:00:00:03:402  NOTICE    (WIF) : Status: 6
000:00:00:03:602  NOTICE    (WIF) : Connected, IP: 192.168.1.52
000:00:00:03:880  NOTICE    (BLK) : run
000:00:00:04:282  NOTICE    (BLK) : virtualWrite OK
000:00:00:04:283  NOTICE    (BLK) : send email: don-and-home@mail.ru
000:00:00:04:349  NOTICE    (BLK) : email was send
000:00:00:04:350  NOTICE    (BLK) : Новые показания {DEVICE_NAME}
000:00:00:04:350  NOTICE    (BLK) : Горячая: 0.0м3, Холодная: 0.0м3<br>За день:<br>Горячая: +0л, Холодная: +0л<br>Напряжение:3.027В
000:00:00:04:403  NOTICE    (BLK) : disconnected
000:00:00:04:403  NOTICE    (BLK) : send ok
000:00:00:04:886  NOTICE    (MQT) : send ok
000:00:00:04:886  NOTICE    (SND) : -- START -- Send new data
000:00:00:04:888  NOTICE    (RQT) : -- START -- Send JSON POST request
000:00:00:04:891  INFO      (RQT) : URL:	https://cloud.waterius.ru
000:00:00:04:897  INFO      (RQT) : Body:	{"delta0":0,"delta1":0,"good":1,"boot":9,"ch0":0,"ch1":0,"imp0":1,"imp1":3,"version":5,"voltage":3.027,"version_esp":"0.8.2","key":"x","resets":1,"email":"x@mail.ru"}
000:00:00:05:186  NOTICE    (NTP) : Waiting for NTP time sync:
000:00:00:05:287  NOTICE    (NTP) : Current time: Sun May 19 21:59:33 2019

000:00:00:05:288  INFO      (RQT) : Begin client
000:00:00:42:098  INFO      (RQT) : Response code:	-1
000:00:01:05:328  INFO      (RQT) : Response body:
000:00:01:05:329  INFO      (RQT) : Result:	Success
000:00:01:05:329  NOTICE    (RQT) : -- END --
000:00:01:05:330  INFO      (SND) : Send HTTP code:	-1
000:00:01:05:335  INFO      (SND) : Send result:	Error
000:00:01:05:340  NOTICE    (SND) : -- END --
000:00:01:05:344  NOTICE    (CFG) : Config stored OK
000:00:01:05:349  NOTICE    (ESP) : Going to sleep
```

dontsovcmc, 2019-05-20:
Как найти ошибку:
- вставить в качестве сервера блинк их IP
- вставить в качестве HTTP сервера IP
мы узнаем, есть ли проблема в mDNS модуле
- поменять местами отправку HTTP и Blynk

OloloevReal, 2019-05-27:
Вот так работает (Blynk + HTTPS):

`platform = https://github.com/platformio/platform-espressif8266.git#v2.1.1`

```
000:00:00:02:796  NOTICE    (WIF) : Status: 6
000:00:00:02:996  NOTICE    (WIF) : Status: 6
000:00:00:03:196  NOTICE    (WIF) : Connected, IP: 192.168.1.253
000:00:00:03:463  NOTICE    (BLK) : run
000:00:00:03:865  NOTICE    (BLK) : virtualWrite OK
000:00:00:03:913  NOTICE    (BLK) : disconnected
000:00:00:03:913  NOTICE    (BLK) : send ok
000:00:00:03:913  NOTICE    (SND) : -- START -- Send new data
000:00:00:03:917  NOTICE    (RQT) : -- START -- Send JSON POST request
000:00:00:03:922  INFO      (RQT) : URL:        https://cloud.waterius.ru
000:00:00:03:928  INFO      (RQT) : Body:       {"delta0":0,"delta1":0,"good":1,"boot":9,"ch0":0,"ch1":0,"imp0":0,"imp1":0,"version":5,"voltage":3.011,"version_esp":"0.8.2","key":"513B2AED3D21473D59F2341F694F4B7A","resets":7,"email":""}
000:00:00:04:213  NOTICE    (NTP) : Waiting for NTP time sync:
000:00:00:04:313  NOTICE    (NTP) : Current time: Mon May 27 21:08:18 2019

000:00:00:04:314  INFO      (RQT) : Begin client
000:00:00:05:145  INFO      (RQT) : Response code:      400
000:00:00:05:147  INFO      (RQT) : Response body:      {"email":["Это поле не может быть пустым."]}
000:00:00:05:150  INFO      (RQT) : Result:     Success
000:00:00:05:154  NOTICE    (RQT) : -- END --
000:00:00:05:158  INFO      (SND) : Send HTTP code:     400
000:00:00:05:163  INFO      (SND) : Send result:        Error
000:00:00:05:168  NOTICE    (SND) : -- END --
000:00:00:05:173  NOTICE    (CFG) : Config stored OK
000:00:00:05:177  NOTICE    (ESP) : Going to sleep

```

Кстати, с самой последней версией platform-espressif8266.git#v2.2.1 при заходе в Настройки происходит краш

dontsovcmc, 2019-05-27:
@OloloevReal а можете провести тест:
1. заполнить email у https. Возникнет ошибка?
2. Заполнить email у Блинка. Возникнет ошибка?

В моем логе это приводит к ошибке =(.
Да, видел, что падает, расстроился, т.к. там мой коммит с повторным подключением.
Значит в WiFiManager что-то не так.. мда, она так медленно развивается, что надо искать замену. Вы не смотрели?

OloloevReal, 2019-05-27:
@dontsovcmc заполнил, работает без ошибок

```
000:00:00:03:201  NOTICE    (WIF) : Connected, IP: 192.168.1.253
000:00:00:03:389  NOTICE    (BLK) : run
000:00:00:03:791  NOTICE    (BLK) : virtualWrite OK
000:00:00:03:791  NOTICE    (BLK) : send email: nikolay.sikorsky@gmail.com
000:00:00:03:858  NOTICE    (BLK) : email was send
000:00:00:03:858  NOTICE    (BLK) : Новые показания {DEVICE_NAME}
000:00:00:03:859  NOTICE    (BLK) : Горячая: 0.0м3, Холодная: 0.0м3<br>За день:<br>Горячая: +0л, Холодная: +0л<br>Напряжение:3.011В
000:00:00:03:955  NOTICE    (BLK) : disconnected
000:00:00:03:956  NOTICE    (BLK) : send ok
000:00:00:03:956  NOTICE    (SND) : -- START -- Send new data
000:00:00:03:960  NOTICE    (RQT) : -- START -- Send JSON POST request
000:00:00:03:964  INFO      (RQT) : URL:        https://cloud.waterius.ru
000:00:00:03:970  INFO      (RQT) : Body:       {"delta0":0,"delta1":0,"good":1,"boot":9,"ch0":0,"ch1":0,"imp0":0,"imp1":0,"version":5,"voltage":3.011,"version_esp":"0.8.2","key":"D26FD0AA69300FDDB3FD7069EBD28762","resets":1,"email":"nikolay.sikorsky@gmail.com"}
000:00:00:04:258  NOTICE    (NTP) : Waiting for NTP time sync:
000:00:00:04:358  NOTICE    (NTP) : Current time: Mon May 27 22:14:50 2019

000:00:00:04:359  INFO      (RQT) : Begin client
000:00:00:05:415  INFO      (RQT) : Response code:      200
000:00:00:05:415  INFO      (RQT) : Response body:
000:00:00:05:416  INFO      (RQT) : Result:     Success
000:00:00:05:418  NOTICE    (RQT) : -- END --
000:00:00:05:422  INFO      (SND) : Send HTTP code:     200
000:00:00:05:427  INFO      (SND) : Send result:        Success
000:00:00:05:432  NOTICE    (SND) : -- END --
000:00:00:05:437  NOTICE    (CFG) : Config stored OK
000:00:00:05:441  NOTICE    (ESP) : Going to sleep

```

Dev ветка WiFiManager гораздо стабильнее, хотя бы не падает

```
platform = https://github.com/platformio/platform-espressif8266.git#v2.2.1
WifiManager = https://github.com/tzapu/WiFiManager.git#development
```

dontsovcmc, 2019-06-05:
`хотя бы не падает`
@OloloevReal это очень важно: в какой вы ветке тестируете, что не падает? И какая версия arduino фреймворка?

dontsovcmc, 2019-07-02:
Аналогично MQTT+HTTPS не работают =(

dontsovcmc, 2019-09-15:
С новым фреймворком все окей

Closed 2019-09-15.

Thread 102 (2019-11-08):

Уменьшить шаблон письма

dontsovcmc, 2019-11-08:
Окащыается напряжение, перезагрузка не входит в 200 символов

dontsovcmc, 2019-11-26:
Показания:<br>Холодная: {V1}м³(+{V4}л)<br>Горячая: {V0}м³ (+{V3}л)<hr>Питание: {V2}В<br>Reset: {V5}

Closed 2019-11-26.

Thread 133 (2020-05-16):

Заменить синхронизацию времени

dontsovcmc, 2020-05-16:
Не обновить версию фреймворка, т.к. они сломали configTime
https://github.com/esp8266/Arduino/issues/7141#issuecomment-629638092

dontsovcmc, 2020-05-16:
Может на эту либу перейти https://github.com/gmag11/NtpClient

g4m3r-87, 2021-03-02:
Доброго времени суток!
`#include <ESP8266WiFi.h>
#include <WiFiClient.h>
#include <time.h>

const char *ssid     = "MTSRouter_042190";
const char *password = "23121987";

void setup()
{
  // put your setup code here, to run once:
  Serial.begin(115200);
  WiFi.begin(ssid, password);

**// конфигтайм выше чем проверка статуса вафай так работает почти всегда**
configTime(0, 0, "pool.ntp.org");

  while ( WiFi.status() != WL_CONNECTED ) {
      delay ( 500 );
      Serial.print ( "." );
  }

**// конфигтайм ниже чем проверка статуса вафай так в 90% случаев не работает**
//configTime(0, 0, "pool.ntp.org");

  Serial.println("Waiting for NTP time sync");
  unsigned long start_ = millis();

  time_t now = time(nullptr);

  while (now < 50000 && millis() - start_ < 3000UL)
  {
    delay(100);
    now = time(nullptr);
  }

  if (millis() - start_ >= 3000UL)
  {
    Serial.print("NTP error");
  }
  else
  {
    time_t now = time(nullptr);
    struct tm timeinfo;
    gmtime_r(&now, &timeinfo);
    Serial.print("Current time: ");
    Serial.print(asctime(&timeinfo));
  }
}

void loop()
{

}`

heX16, 2021-03-03:
> Доброго времени суток!
> ...

Что это?

neitri, 2022-01-22:
Проверил сейчас на версии 3.2.0 синхронизация времени работает.
Часть лога:
000:00:00:03:980  INFO      (WIF ) : mode N
000:00:00:03:984  INFO      (WIF ) : Connected, IP: 192.168.0.112
000:00:00:03:990  DEBUG     (WIF ) : RSSI: -68
000:00:00:03:994  INFO      (BLK ) : SKIP
000:00:00:03:998  INFO      (MQT ) : SKIP
000:00:00:04:002  INFO      (SND ) : -- START -- Send new data
000:00:00:04:008  INFO      (SND ) : JSON size: 371
000:00:00:04:012  INFO      (RQT ) : -- START -- Send JSON POST request
000:00:00:04:018  INFO      (RQT ) : URL:       https://cloud.waterius.ru
000:00:00:04:024  INFO      (RQT ) : Body:      {"delta0":0,"delta1":0,"good":1,"boot":1,"ch0":321,"ch1":654,"imp0":3,"imp1":5,"version":22,"voltage":3.476,"version_esp":"0.10.5","key":"AAA7FE7D1ABAD041F6197751B43A9446","resets":2,"email":"***","voltage_low":false,"voltage_diff":11,"f0":1,"f1":1,"rssi":-68,"waketime":10083,"setuptime":496505,"adc0":0,"adc1":0,"period_min":1440,"serial0":"","serial1":""}
000:00:00:04:272  INFO      (NTP ) : Waiting for NTP time sync:
000:00:00:04:373  INFO      (NTP ) : Current time: Sat Jan 22 12:26:36 2022

000:00:00:04:374  INFO      (RQT ) : Begin client
000:00:00:05:677  INFO      (RQT ) : Response code:     200
000:00:00:05:678  INFO      (RQT ) : Response body:
000:00:00:05:678  INFO      (RQT ) : -- END --
000:00:00:05:680  INFO      (SND ) : Send HTTP code:    200
000:00:00:05:685  INFO      (SND ) : -- END --
000:00:00:05:764  INFO      (CFG ) : Config stored OK
000:00:00:05:765  INFO      (ESP ) : Going to sleep

dontsovcmc, 2022-02-21:
Да, работает. Закрываем задачу.

Closed 2022-02-21.

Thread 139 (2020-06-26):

Чтение напряжения питания с батареек аналоговым входом ESP

OloloevReal, 2020-06-26:
Добрый день!

Для ESP32 замер напряжения с элементов питания (4xAA или 1x18650) делал следующим образом:

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

Где:
VBAT  - выход элементов питания
GPIO-13 - Выход ESP разрешающий замер
GPIO-27 - Аналоговый вход ESP

Т.к. напряжение снимается с делителя 50/50, то АЦП считывает значение эквивалентное половине VBAT

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

Цель всей этой схемотехники избежать постоянной утечки на землю, и делать замер только по запросу.
Необходимы конечно свободные IO, с ESP32 с этим все в порядке, а вот ESP8266 дефицит
Может пригодится

dontsovcmc, 2020-06-26:
Мне Иван рисовал похожую схему:
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

Дмитрий ее реализовал на большой плате:
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

На текущий ватериус не ясно, куда ее запихнуть =( А вот на ESP-12F влезает.

OloloevReal, 2020-06-27:
Так-то тоже самое, только на полевиках. С ESP01, если правильно помню, только один ADC и тот не распаян, вариант только подпаиваться к чипу.  И попасть в диапазон от 0 до 1.0 V придется

Closed 2021-03-22.

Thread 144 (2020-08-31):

Добавить настройку периода отправки

dontsovcmc, 2020-08-31:
ESP8266
1.1. Добавить в дополнительные настройки wifiManger поле “Как часто обновлять данные о показаниях, мин.” Значение по умолчанию: 1440 (1 день). Для инициализации использовать константу WAKE_EVERY_MIN.
1.2. Добавить в структуру настроек параметр short wakeup_period_min, отвечающий за период отправки данных.
1.3.  Добавить передачу данных по I2C от ESP Attiny сразу после инициализации. Используемые поля: ID команды, данные(период), CRC.

Attiny85
1.4.  Добавить прием данных по I2C с использованием ID команды из п. 1.3. Осуществить проверку CRC.
1.5. Добавить сохранение периода отправки в EEPROM, а также чтение при начальной инициализации.
1.6. Использовать заданное значение периода отправки для пробуждения ESP.

obrianw, 2020-11-26:
Нужный параметр, особенно когда есть Умный дом. 👍

dontsovcmc, 2020-12-03:
> Нужный параметр, особенно когда есть Умный дом. 👍
> Понятно, что при увеличении передачи данных (будим ESP8266, wifi, согласование) потребуется сменить на более мощные аккумуляторы или ставить БП.

У меня проработал около 2-х лет при передачи каждые 30 сек.

obrianw, 2020-12-04:
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

Не ожиданно! Это же меняет всё (!) Так часто это конечно сильно, но для проверки начальных показаний самое-то!

И значит не зря, что затеял собрать себе таких три штуки, и даже по Вашему шаблону из гайда таки заказал с десяток плат (3-ей версии :) ) на PCBWay (использовав скидку на первый заказ) оплатив только доставку и комиссию за оплату (1$ комиссии с $5 это конечно сильно, но что-ж возьмешь с банков, ещё те крахоборы) и опять же по Вашему списку так же заказал недостающие компоненты, коих нет под рукой...
Огромное спасибо за такой подробный и открытый проект!

dontsovcmc, 2021-01-27:
Заголовок поля: "Как часто обновлять данные о показаниях, мин"

dontsovcmc, 2021-02-25:
Можно задать период выхода на связь в минутах. По умолчанию 1 сутки (1440 мин). Период хранится в памяти ESP. При каждом пробуждении она передает в attiny это значение.

Closed 2021-02-25.

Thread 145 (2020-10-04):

Не компилируется прошивка

NOV62, 2020-10-04:
Добрый день! Пытаюсь собрать прошивку для ESP8266 в Arduino IDE, не выходит, компилятор ругается на  Дополнение к WifiManager.

In file included from sketch\setup_ap.h:8:0,
                 from sketch\setup_ap.cpp:2:
D:\����� �����\Arduino\libraries\WiFiManager/WiFiManager.h: In constructor 'LongParameter::LongParameter(const char*, const char*, long int, uint8_t)':
D:\����� �����\Arduino\libraries\WiFiManager/WiFiManager.h:65:10: error: 'void WiFiManagerParameter::init(const char*, const char*, const char*, int, const char*)' is private
     void init(const char *id, const char *placeholder, const char *defaultValue, int length, const char *custom);
          ^
In file included from sketch\setup_ap.cpp:2:0:
setup_ap.h:25:9: error: within this context
         init(id, placeholder, String(value).c_str(), length, " type=\"number\"", WFM_LABEL_BEFORE);
         ^
setup_ap.h:25:82: error: 'WFM_LABEL_BEFORE' was not declared in this scope
         init(id, placeholder, String(value).c_str(), length, " type=\"number\"", WFM_LABEL_BEFORE);
                                                                                  ^
In file included from sketch\setup_ap.h:8:0,
                 from sketch\setup_ap.cpp:2:
D:\����� �����\Arduino\libraries\WiFiManager/WiFiManager.h: In constructor 'FloatParameter::FloatParameter(const char*, const char*, float, uint8_t)':
D:\����� �����\Arduino\libraries\WiFiManager/WiFiManager.h:65:10: error: 'void WiFiManagerParameter::init(const char*, const char*, const char*, int, const char*)' is private
     void init(const char *id, const char *placeholder, const char *defaultValue, int length, const char *custom);
          ^
In file included from sketch\setup_ap.cpp:2:0:
setup_ap.h:39:9: error: within this context
         init(id, placeholder, String(value,3).c_str(), length, " type=\"number\" step=\"0.001\" placeholder=\"0,000\"", WFM_LABEL_BEFORE);
         ^
setup_ap.h:39:121: error: 'WFM_LABEL_BEFORE' was not declared in this scope
         init(id, placeholder, String(value,3).c_str(), length, " type=\"number\" step=\"0.001\" placeholder=\"0,000\"", WFM_LABEL_BEFORE);
                                                                                                                         ^
In file included from sketch\setup_ap.h:8:0,
                 from sketch\setup_ap.cpp:2:
D:\����� �����\Arduino\libraries\WiFiManager/WiFiManager.h: In constructor 'IPAddressParameter::IPAddressParameter(const char*, const char*, IPAddress)':
D:\����� �����\Arduino\libraries\WiFiManager/WiFiManager.h:65:10: error: 'void WiFiManagerParameter::init(const char*, const char*, const char*, int, const char*)' is private
     void init(const char *id, const char *placeholder, const char *defaultValue, int length, const char *custom);
          ^
In file included from sketch\setup_ap.cpp:2:0:
setup_ap.h:58:9: error: within this context
         init(id, placeholder, val.c_str(), 16, "minlength=\"7\" maxlength=\"15\" size=\"15\" pattern=\"^((\\d{1,2}|1\\d\\d|2[0-4]\\d|25[0-5])\\.){3}(\\d{1,2}|1\\d\\d|2[0-4]\\d|25[0-5])$\"", WFM_LABEL_BEFORE);
         ^
setup_ap.h:58:191: error: 'WFM_LABEL_BEFORE' was not declared in this scope
         init(id, placeholder, val.c_str(), 16, "minlength=\"7\" maxlength=\"15\" size=\"15\" pattern=\"^((\\d{1,2}|1\\d\\d|2[0-4]\\d|25[0-5])\\.){3}(\\d{1,2}|1\\d\\d|2[0-4]\\d|25[0-5])$\"", WFM_LABEL_BEFORE);
                                                                                                                                                                                               ^
In file included from sketch\setup_ap.h:8:0,
                 from sketch\setup_ap.cpp:2:
D:\����� �����\Arduino\libraries\WiFiManager/WiFiManager.h: In function 'void handleStates()':
D:\����� �����\Arduino\libraries\WiFiManager/WiFiManager.h:123:39: error: 'std::unique_ptr<esp8266webserver::ESP8266WebServerTemplate<WiFiServer> > WiFiManager::server' is private
     std::unique_ptr<ESP8266WebServer> server;
                                       ^
setup_ap.cpp:100:6: error: within this context
   wm.server->send(200, F("text/plain"), message);
      ^
sketch\setup_ap.cpp: In function 'void handleNetworks()':
setup_ap.cpp:107:6: error: 'class WiFiManager' has no member named 'WiFi_scanNetworks'
   wm.WiFi_scanNetworks(wm.server->hasArg(F("refresh")),false); //wifiscan, force if arg refresh
      ^
In file included from sketch\setup_ap.h:8:0,
                 from sketch\setup_ap.cpp:2:
D:\����� �����\Arduino\libraries\WiFiManager/WiFiManager.h:123:39: error: 'std::unique_ptr<esp8266webserver::ESP8266WebServerTemplate<WiFiServer> > WiFiManager::server' is private
     std::unique_ptr<ESP8266WebServer> server;
                                       ^
setup_ap.cpp:107:27: error: within this context
   wm.WiFi_scanNetworks(wm.server->hasArg(F("refresh")),false); //wifiscan, force if arg refresh
                           ^
setup_ap.cpp:108:6: error: 'class WiFiManager' has no member named 'getScanItemOut'
   wm.getScanItemOut(message);
      ^
In file included from sketch\setup_ap.h:8:0,
                 from sketch\setup_ap.cpp:2:
D:\����� �����\Arduino\libraries\WiFiManager/WiFiManager.h:123:39: error: 'std::unique_ptr<esp8266webserver::ESP8266WebServerTemplate<WiFiServer> > WiFiManager::server' is private
     std::unique_ptr<ESP8266WebServer> server;
                                       ^
setup_ap.cpp:109:6: error: within this context
   wm.server->send(200, F("text/plain"), message);
      ^
In file included from sketch\setup_ap.h:8:0,
                 from sketch\setup_ap.cpp:2:
D:\����� �����\Arduino\libraries\WiFiManager/WiFiManager.h: In function 'void bindServerCallback()':
D:\����� �����\Arduino\libraries\WiFiManager/WiFiManager.h:123:39: error: 'std::unique_ptr<esp8266webserver::ESP8266WebServerTemplate<WiFiServer> > WiFiManager::server' is private
     std::unique_ptr<ESP8266WebServer> server;
                                       ^
setup_ap.cpp:113:6: error: within this context
   wm.server->on(F("/states"), handleStates);
      ^
In file included from sketch\setup_ap.h:8:0,
                 from sketch\setup_ap.cpp:2:
D:\����� �����\Arduino\libraries\WiFiManager/WiFiManager.h:123:39: error: 'std::unique_ptr<esp8266webserver::ESP8266WebServerTemplate<WiFiServer> > WiFiManager::server' is private
     std::unique_ptr<ESP8266WebServer> server;
                                       ^
setup_ap.cpp:114:6: error: within this context
   wm.server->on(F("/networks"), handleNetworks);
      ^
sketch\setup_ap.cpp: In function 'void setup_ap(Settings&, const SlaveData&, const CalculatedData&)':
setup_ap.cpp:120:8: error: 'class WiFiManager' has no member named 'debugPlatformInfo'
     wm.debugPlatformInfo();
        ^
setup_ap.cpp:121:8: error: 'class WiFiManager' has no member named 'setWebServerCallback'
     wm.setWebServerCallback(bindServerCallback);
        ^
Что надо подправить?
Спасибо

UPD: Заменил WiFiManager на рекомендованный (изWiFiManager#waterius_release_099), ошибки стали другими, но там же:
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
dontsovcmc, 2020-10-04:
Все верно. Дело в том, что нужна моя ветка Wifimanager:   https://github.com/dontsovcmc/WiFiManager.git#waterius_release_100
ее в архиве и подкладывать в Arduino IDE

NOV62, 2020-10-04:
Сделал. Не помогло.

И Platformio не хочет компилировать, ругается на саму себя. Хотя другие проекты в той же папке собираются без проблем. Скрин прилагаю.
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

Прошу прощения за назойливость. Я начинающий, хочу разобраться, как у Вас реализовано открытие окна доп. настроек WiFiManager. Как я понял, при отметке чекбокса вызывается функция advSett(), которая должна быть в скрипте, но её нет! И в исходниках advSett нигде не находится.
Непонятно...

NOV62, 2020-10-04:
В функции handleNetworks() вкладки setap_ap.cpp вызываются wm.WiFi_scanNetworks и wm.getScanItemOut, которых тоже нет в библиотеке, по Вашей ссылке тоже.

OloloevReal, 2020-10-04:
advSett() как раз в форке  WifiManager и реализован, в файле strings_en.h смотрите

dontsovcmc, 2020-10-04:
> Сделал. Не помогло.
>
> И Platformio не хочет компилировать, ругается на саму себя. Хотя другие проекты в той же папке собираются без проблем. Скрин прилагаю.

в Platformio ничего не надо менять , там все должно собраться сразу...
а какая версия у вас?

да, чекбокс на JS сделан

NOV62, 2020-10-04:
Спасибо, теперь понятно. Просто я не оттуда скачивал.
Platformio 1.49.3, не собирается, скрин выше. Остальные проекты компилируются нормально, в том числе импортированные из Ардуино, специально попробовал ещё раз. Ничего не понимаю...

NOV62, 2020-10-04:
Вот строчка, на которой стопится:

UnicodeDecodeError: 'charmap' codec can't decode byte 0x98 in position 365: character maps to <undefined>
The terminal process "C:\Users\O1962\.platformio\penv\Scripts\platformio.exe 'run'" terminated with exit code: 1.

dontsovcmc, 2020-10-04:
А попробуйте удалить все русские символы из platformio.ini

NOV62, 2020-10-05:
Ещё раз Спасибо за помощь! Разобрался. Из-за бардака в ноуте запутался в версиях WM.
Трудно осваивать что-то новое в 58 лет, до последнего времени программированию учился в институте в 1985г и с тех пор не имел отношения к этой теме вообще. А сейчас затянуло, очень интересно, но мозги ворочаются с трудом.
У Вас замечательный проект, хочу к весне на его базе сделать автономные датчики влажности почвы на дачу для управления системой полива и переделать веб-морды уже работающих устройств - датчики температуры, RF-MQTT-HTTP мост с контроллером охранной сигнализации, контроллер управления UPS  для насосной станции, чтобы при отсутствии сети он включался только на время работы насоса (пока недоделано).
p.s. А platformio так и дурит - теперь, после удаления кирилицы и установки платформы ESP 2.4.0 вместо 2.6.2 компиляция начинается, молотит минуты полторы, потом просто вылетает с сообщением:

collect2.exe: error: ld returned 1 exit status
*** [.pio\build\esp01_1m\firmware.elf] Error 1.

Для меня это слишком сложно...

NOV62, 2020-10-05:
Всё, разобрался. Лишние папки надо выкидывать из рабочих директорий. Я ардуиновскую версию там оставил, из-за неё и глючило. Ещё раз спасибо всем, кто откликнулся. И простите за глупые вопросы.

dontsovcmc, 2020-10-05:
@NOV62 Отлично! Заходите в чат https://t.me/waterius_forum
Arduino ide и platformio разные продукты. Абсолютное большинство юзеров не знают, что у них под капотом. Поэтому ваши ошибки не являются простыми.
У Platformio есть свой менеджер библиотек, тянуть arduino ide не нужно.
Посмотрите в сторону ESPHome и подобных конструкторов, вдруг там уже есть решение из коробки.
Веб морда это тяжелая тема. Аналогов Wifimanager не знаю, а он не очень хорошо сделан.

Closed 2020-10-05.

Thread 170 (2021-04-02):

странная перезагрузка attiny85 по Watchdog Reset Flag

dontsovcmc, 2021-04-02:
Работает работает, а через сутки перестает пробуждаться. Но не перестает считать.
При этом после нажатия на кнопку - регистр MCUSR равен 8
1000 - WDRF: Watchdog Reset Flag. Завершение работы таймера

Причина перезагрузки (регистр MCUSR datasheet 8.5.1):
         0001 - PORF: Power-on Reset Flag. Напряжение питания было низкое или 0.
         0010 - EXTRF: External Reset Flag. Пин ресет был в низком уровне.
         0100 - BORF: Brown-out Reset Flag. Напряжение питание было ниже требуемого.
         1000 - WDRF: Watchdog Reset Flag. Завершение работы таймера.
 
Подробное описание:
https://electronix.ru/forum/index.php?app=forums&module=forums&controller=topic&id=160954

dontsovcmc, 2021-04-04:
5 тестовых устройств с WDTCR |= bit( WDIE ) в ISR(WDT_vect) продолжают исправно работать, когда без него через сутки точно зависали.
Дополнительно убрал WDE из WDTCR = bit( WDCE ) | bit( WDE ), т.к. бит отвечает за перезагрузку МК.

Версия прошивки attiny 19.

Closed 2021-04-04.

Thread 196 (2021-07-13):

Добавить перезагрузку по watchdog

dontsovcmc, 2021-07-13:
В ватериусе не работает перезагрузка attiny при наступлении таймаута watchdog. Возможно именно это является причиной редких зависаний.
Проверяется добавлением паузы, скажем в функцию counting:

```
	if (counter1.is_impuls()) {
		info.data.value1++;
		info.states.state1 = counter1.state;
		info.adc.adc1 = counter1.adc;
		storage.add(info.data);

		delayMicroseconds(65000);
		delayMicroseconds(65000);
		delayMicroseconds(65000);
		delayMicroseconds(65000);
		delayMicroseconds(65000);
	}
```

Конфигурирование watchdog для этой цели:

MCUSR = 0;
WDTCR = bit( WDCE ) | bit( WDE );
WDTCR = bit( WDIE ) | **bit( WDE )** | bit( WDP2 );   //Именно тут нужно взводить бит WDE для перезагрузки

Обязательно очищать MCUSR - без этого МК не перезапуститься после ресета (потребление скачет 240-400мкА)

И добавить WDTCR |= _BV(WDIE); перед  sleep_mode();

Теперь при замыкании input1 - будет сброс по watchgod изза паузы в 300мс и мы видим reset++ и service=8.

dontsovcmc, 2021-07-13:
В последней экспериментальной версии сейчас это выглядит так:

```
ISR( WDT_vect ) {
	++wdt_count;
}

setup() {
	noInterrupts();
	info.service = MCUSR; // причина перезагрузки
	MCUSR = 0;            // без этого не работает после перезагрузки по watchdog
	wdt_disable();
	interrupts();

	set_sleep_mode( SLEEP_MODE_PWR_DOWN );
	....
}

void loop() {
	power_all_disable();  // Отключаем все лишнее: ADC, Timer 0 and 1, serial interface

        wdt_enable(WDTO_250MS);
	interrupts();

	wdt_count = 0;
	while ((wdt_count < wakeup_period) && !button.pressed())
	{
		counting();
		WDTCR |= _BV(WDIE);
		sleep_mode();
	}

	wdt_disable();
	interrupts();

	power_all_enable();
}
```

dontsovcmc, 2021-09-20:
Если будут вопросы, открою задачу

Closed 2021-09-20.

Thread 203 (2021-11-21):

Загрузка лога из 192.168.4.1

dontsovcmc, 2021-11-21:
Может быть проблемы:
- с подключением к серверу
- с подключением к роутеру
- с синхронизацией времени

В момент запуска это никак не отследить, а нужна информация о причинах для отладки.

Идея: возможность скачать лог, запустив режим настройки (192.168.4.1).

Пусть скажем GET запрос 192.168.4.1/tracelog.txt - скачивается кольцевой(?) буфер лога последних действий устройства.
Надо на главной странице (под кнопкой Настройка) + на последней странице (где подключение) разместить текстовую ссылку "трейслог" (192.168.4.1/tracelog.txt).

Насколько я понимаю нужно использовать: [LittleFS](https://github.com/littlefs-project/littlefs)
Изучить: https://github.com/lorol/LITTLEFS/issues/10

Для экономии места, можно запихнуть в 1 строчку логирование опроса i2c. И даже пожертвовать метками времени (лейблами точно):
```
000:00:00:01:033  INFO      (I2C) : version: 19
000:00:00:01:033  INFO      (I2C) : service: 7
000:00:00:01:034  INFO      (I2C) : voltage: 3352
000:00:00:01:035  INFO      (I2C) : resets: 19
000:00:00:01:039  INFO      (I2C) : MODEL: 0
000:00:00:01:043  INFO      (I2C) : state0: 0
000:00:00:01:047  INFO      (I2C) : state1: 0
000:00:00:01:051  INFO      (I2C) : impulses0: 10
000:00:00:01:056  INFO      (I2C) : impulses1: 14
000:00:00:01:060  INFO      (I2C) : adc0: 0
000:00:00:01:064  INFO      (I2C) : adc1: 0
000:00:00:01:068  INFO      (I2C) : CRC ok
```
000:00:00:01:033  INFO      (I2C) : 19-7-3352-19-0 0-10-0 0-14-0

dontsovcmc, 2023-10-31:
Закрыл, т.к. сделал новую тему: https://github.com/dontsovcmc/waterius/issues/292

Closed 2023-10-31.

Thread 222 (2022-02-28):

Время подключения к сети.

neitri, 2022-02-28:
Обратил внимание, что время подключения зависит от используемого канала. У меня был 13 канал динамический адрес, время работы около 6-7 секунд. Со статическим адресом около 5.
Поменял канал на 1 и подключение произошло буквально мгновенно. 1-2 раза напряжение успевает измерить.
Но тут ечть вопросы и к себе.
Я пробывал указывать и канал и мак адрес точки доступа. Но даже если я указываю при подключении 13 канал, время подключения увеличивается. При подключении esp сканирует все каналы пока не найдет свою сеть. Почему при указании канала все равно их сканирует мне не понятно.

Давайте попытаемся собрать статистику у кого какой канал и сколько время подключается.

Tls соединение 2-4 секунды занимает. А то и все 6. Но там вопросы к качеству интернета.

dontsovcmc, 2022-02-28:
Я видел большие темы по поводу каналов Wi-Fi, но не вдавался в подробности.. А мы можем сохранять канал в памяти и подключаться к конкретному?

dontsovcmc, 2022-02-28:
[тема на гитхабе про время подключения](https://github.com/espressif/arduino-esp32/issues/1675#issuecomment-850994388)

Тут документ просто про частоты и легитимность в странах: https://www.espressif.com/sites/default/files/documentation/esp8266_wi-fi_channel_selection_guidelines_en.pdf

neitri, 2022-03-01:
Эта тема мне уже попадалась. Но результат пока отрицательный.
Указание мак адреса сети вроде ускоряет процес подключения. Но сканирование каналов никуда не девается. С 1 каналом подключается быстрее.
На данный момент получается что для сокращения времени работы необходимо установить статический ip адресс и использовать по возможности наименьший канал.

По прописыванию мак адреса точки доступа время подключения может и сокращается, но время с отправкой занимает примерно тоже самое.

dontsovcmc, 2022-12-18:
@neitri я кстати подумал, что хорошо бы для эксперимента уменьшить версию прошивки фреймворка. Потому что у кого-то типа esphome используется одна из первых версий прошивки как stable.
эксперимент может быть: очистка памяти  (чтобы настройки вайфая точно стерлись), прошивка версией Х с захардкоженными настройками wi-fi, замер времени подключения.

vzagorovskiy, 2023-02-15:
fixed https://github.com/dontsovcmc/waterius/commit/76eb2bf4c77cbecfdc889b3541fd2145284fe187

dontsovcmc, 2023-04-29:
да, 0.11.0 подключается за 2.5 сек. соберем статистику. посмотрим еще

Closed 2023-04-29.

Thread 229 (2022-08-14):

Не подключается к ASUS RT-AX86U при WPA2

dontsovcmc, 2022-08-14:
Если на этом роутере включить WPA2/WPA3-Personal, тогда нужно отключить параметр WiFi Agile Multiband
ASUS RT-AX86U

Вот описание ошибки. Кажется в новой версии ядра починили.
https://github.com/esp8266/Arduino/issues/8299

dontsovcmc, 2022-11-14:
TP-Link AX5400 роутер. Настройка статического адреса.
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

dontsovcmc, 2022-12-01:
ASUS RT-AX82U кажется аналогичная проблема

dontsovcmc, 2022-12-18:
ASUS RT-AX58U, прошивка 388.1 от мерлина
Привязка по Мак адресу есть. Период 720мин, 0.10.7.  Выходит на связь 2 дня, потом нет.

Вручную по кнопке лог роутера:

Dec 18 14:18:08 wlceventd: wlceventd_proc_event(505): eth5: Auth 48:55:19:D0:23:A3, status: Successful (0)
Dec 18 14:18:08 hostapd: eth5: STA 48:55:19:d0:23:a3 IEEE 802.11: associated
Dec 18 14:18:08 wlceventd: wlceventd_proc_event(534): eth5: Assoc 48:55:19:D0:23:A3, status: Successful (0)
Dec 18 14:18:08 hostapd: eth5: STA 48:55:19:d0:23:a3 RADIUS: starting accounting session 16929F3708ADD8EF
Dec 18 14:18:08 hostapd: eth5: STA 48:55:19:d0:23:a3 WPA: pairwise key handshake completed (RSN)
Dec 18 14:18:29 hostapd: eth5: STA 48:55:19:d0:23:a3 IEEE 802.11: disassociated
Dec 18 14:18:29 wlceventd: wlceventd_proc_event(469): eth5: Deauth_ind 48:55:19:D0:23:A3, status: 0, reason: Disassociated due to inactivity (4)
Dec 18 14:18:29 hostapd: eth5: STA 48:55:19:d0:23:a3 IEEE 802.11: disassociated
Dec 18 14:18:29 wlceventd: wlceventd_proc_event(469): eth5: Deauth_ind 48:55:19:D0:23:A3, status: 0, reason: Previous authentication no longer valid (2)
Dec 18 14:18:30 hostapd: eth5: STA 48:55:19:d0:23:a3 IEEE 802.11: disassociated
Dec 18 14:18:30 wlceventd: wlceventd_proc_event(486): eth5: Disassoc 48:55:19:D0:23:A3, status: 0, reason: Disassociated because sending station is leaving (or has left) BSS (8)

dontsovcmc, 2023-02-20:
"После последнего обновления роутера ASUS RT-AX86 перестал подключаться. В роутере был режим wpa2/wpa3. Раньше подключался нормально. Пришлось в роутере перейти на чистый wpa2, тогда подключается нормально."
riurii

dontsovcmc, 2023-03-24:
Юрий докопался до еще одних "нюансов":

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

равнивал работу роутера с двумя ESP.  Вашем и Тайпитовским, который работает устойчиво. Если какие-либо имена разнятся в двух Ваших прошивках, тогда проблема не в ESP. Роутер привязывает эти имена и прочие настройки к MAC и сохраняет в своей памяти. Если имена на устройстве поменять, не меняя мак адреса, то это устройство уже будет игнорироваться роутером (асусом). Для корректной работы esp нужно всего лишь удалить его из памяти роутера. Как это сделать: 1 либо с мобильного устройства. Ну здесь все просто «Устройства-Не в сети», найти устройство из списка и сдвинуть влево.

Все само тогда исправится до следующей изменений в именах.
Теперь о причине и как исправить это через веб морду.
2. Заходим в «Локальная сеть-DHCP сервер» Отключаем новый параметр, которого в старой прошивке не было «Advertise router's IP in addition to user-specified DNS» ставим «Нет». Далее включить назначение вручную «Да» Если ранее было включено, не трогаем. В таблице есть столбик «Имя клиента» рядом с ним красная стрелочка, вот ее и нажимаем. В выпадающем меню нажимаем «Показать отключенных клиентов в списке», находим интересующий нас ESP и нажимаем крестик напротив него. Внизу страницы нажимаем «Применит». Далее, если не актуально выключаем «Включить назначение вручную» «Нет» и после всего этого обязательно возвращаем на место параметр «Advertise router's IP in addition to user-specified DNS» «Да» нажимаем в конце страницы применить. После этого роутер видит новое устройство и без проблем коннектит. Ключи здесь ни причем.

Если параметр «Advertise router's IP in addition to user-specified DNS» оставить «нет» тогда с современными устройствами  возможны сбои при подключении.

И ещё: если в локалке ранее не подключали ни один ESP, тогда с первым подключением проблем не будет у клиентов. Если были ранее подключены, тогда с роутера удаляем все неиспользуемые устройства для надежности. Либо, делаем роутеру Хард сброс и настраиваем с нуля, не применяя никаких сохраненных профилей. Да и прошивать роутер лучше через аварийную утилиту в том случае, если давно прошивка на роутере не менялась.
Короче, у Асуса - «чем дальше в лес, тем больше дров»

Еще одна особенность в работе ESP с Асусами ( у других устройств такого нет) :
Если в роутере переименовать или изменить пиктограмму отключенного ESP через веб морду , то далее конекта уже не будет. На подключенном можно, но не успеть это сделать. Если кому-то это нужно тогда пусть меняют имя через мобильное приложение AsusRouter там это работает и подключение не нарушится.

Итог: проблема не в шифровании и не в WiFi, а в несовместимости работы по DHCP. Там все время что-то меняют. Народ пишет, что какие-то флаги ввели ведущий-ведомый/свой-чужой.  На примере Apple: если на сервере роутера назначить имя, ip по Mac, но не подключать устройство, то при первом подключении Apple меняют все настройки роутера под себя и только потом дают изменить в роутере ip или что-то еще. У китайских дешевых камер, которые через Wi-Fi работат, нельзя в камере ставить статический ip, если он установлен в роутере (либо там, либо там) если и там и там тогда ровно через 12 часов роутер зависает. Люди роутеры меняют и провайдеров дергают. Не зная проблему не решить. Вообщем у всех свои недостатки есть.

dontsovcmc, 2023-03-25:
Пользователь Юрий написал подробную инcтрукцию по настройке  DHCP сервера Asus. :
[Исправление_ошибки_передачи_показаний_на_сервер_Ватериус_из_локальной.pdf](https://github.com/dontsovcmc/waterius/files/11068774/_._._._._._._._.pdf)

dontsovcmc, 2023-04-29:
Требуется проверить с такими роутерами новую прошивку 0.11.3

Closed 2023-04-29.

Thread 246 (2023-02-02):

Поиск причины ошибки подключения к некоторым роутерам

dontsovcmc, 2023-02-02:
Для того, чтобы выяснить причину ошибки подключения к роутерам (https://github.com/dontsovcmc/waterius/issues/229, https://github.com/dontsovcmc/waterius/issues/131) предлагаю:

При наличии «плохого» роутера:

1. Залить пример обычного подключения к WiFi последней версии arduinoframework.
2. Залить пример из WiFiManager последней версии (master ветку https://github.com/tzapu/WiFiManager/tree/master) и проверить, подключиться ли к роутеру.
3. Залить https://github.com/arendst/Tasmota последней версии и проверить, подключиться ли к роутеру.

Важно выяснить при каких настройках роутера возникает ошибка, поэтому сначала стоит перебрать эти варианты, а затем уже перенастраивать роутер.

vzagorovskiy, 2023-02-15:
partially fixed #247 #252

dontsovcmc, 2023-07-05:
не подключается:
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

dontsovcmc, 2023-08-07:
Нашёл в коде ESP описание точки доступа. Все поля требуется вывести, чтобы видеть отличия.

```
struct bss_info {
    STAILQ_ENTRY(bss_info)     next;

    uint8 bssid[6];
    uint8 ssid[32];
    uint8 ssid_len;
    uint8 channel;
    sint8 rssi;
    AUTH_MODE authmode;
    uint8 is_hidden;
    sint16 freq_offset;
    sint16 freqcal_val;
    uint8 *esp_mesh_ie;
    uint8 simple_pair;
    CIPHER_TYPE pairwise_cipher;
    CIPHER_TYPE group_cipher;
    uint32_t phy_11b:1;
    uint32_t phy_11g:1;
    uint32_t phy_11n:1;
    uint32_t wps:1;
    uint32_t reserved:28;
};
```

Fortunatto, 2023-08-27:
Не подключается к роутеру в принципе.
Роутер - Mikrotik hap ac^2 (RBD52G-5HacD2HnD-TC) - версия прошивки 7.11.
Waterius - esp v. 0.11.7.

Менял настройки роутера: стандарты связи (b/g/n и их комбинации), ширину каналов, страну использования (влияет на используемые частоты, как я понимаю) - ничего не помогло. Кстати, при выборе страны "rissia 4", esp Ватериуса мою сеть не видела в принципе.

В качестве теста залил на esp: [Tasmota 13.1.0 by Theo Arends](https://bit.ly/tasmota) - все подключилось и работает.

dontsovcmc, 2023-08-27:
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

Ооо низкий поклон за такое подробное исследование!

Кажется код подключения к точке доступа тут:
https://github.com/arendst/Tasmota/blob/23d6c0f5d5f2882a3c744669cdcbfee832f5ab52/tasmota/tasmota_support/support_wifi.ino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

У WifiManager вот (наша ветка):
https://github.com/dontsovcmc/WiFiManager/blob/waterius_release_112/WiFiManager.cpp#L1143

dontsovcmc, 2023-08-27:
> Не подключается к роутеру в принципе. Роутер - Mikrotik hap ac^2 (RBD52G-5HacD2HnD-TC) - версия прошивки 7.11. Waterius - esp v. 0.11.7.

А точка доступа содержит пробелы? Если да, то точно из-за них. В веб морде вручную введите пожалуйста пробел.

vzagorovskiy, 2023-08-27:
wAP ac, cAp ac, hAp ac2 у всех 7.11  работает все норм. Проблема в конфигурации.

Fortunatto, 2023-09-03:
> А точка доступа содержит пробелы? Если да, то точно из-за них. В веб морде вручную введите пожалуйста пробел.
Имя точки доступа без пробелов, содержит заглавные и строчней буквы, цифры и знак "-". До этого прошивку своих Ватериусов обновлял в 2022 году - переход прошел безболезненно.

> Ещё вопрос: а до обновления была прошивка уже? стоит очистить память перед новой прошивкой..
Чистил память заливкой пустой прошивки.

> hAp ac2 у всех 7.11 работает все норм. Проблема в конфигурации.
Имеете в виду конфигурацию роутера? Tasmota же подключилась...

dontsovcmc, 2023-09-03:
Хм не знаю, что предположить тогда.
Я увидел, что wifimanager посадил ошибку с пробелом в имени сети. Может конечно они с тире тоже сделали такое :(. Удобно проверить: вручную введя имя точки доступа в строку под списком вайфаев?

0.11.8 исправлен только пробел, можно на 0.11.7 проверить. Спасибо!
А вам удобно снять лог с вывода LOG у ESP? Очень пригодится

Fortunatto, 2023-09-09:
> wAP ac, cAp ac, hAp ac2 у всех 7.11 работает все норм. Проблема в конфигурации.

Возможно Вы правы - попробовал подключиться к виртуальной ТД на телефоне - соединение прошло. Можете поделиться своей конфигурацией?

dontsovcmc, 2023-09-09:
> > wAP ac, cAp ac, hAp ac2 у всех 7.11 работает все норм. Проблема в конфигурации.
>
> Возможно Вы правы - попробовал подключиться к виртуальной ТД на телефоне - соединение прошло. Можете поделиться своей конфигурацией?

А вы тоже можете поделиться своей?

Ещё недавно писали, что не подключается к only n. А если bgn, то норм

Fortunatto, 2023-09-09:
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

Подтверждаю. Перешел в b/g/n, ширину канала перевел в 20 МГц - удалось подключиться. Видимо это в совокупности и сработало. В прошлый раз менял на b/g/n, но это не помогло.

dontsovcmc, 2023-10-31:
В версии 1.0.0 подключаемся по другому.
Нужно проверить её с проблемными роутерами!

Closed 2023-12-25.

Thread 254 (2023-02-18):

Обновить версию WiFiManager

dontsovcmc, 2023-02-18:
WiFiManager выложен в декабре 2022 г.
Наш 2020г и можно обновить. Возможно это поможет с проблемными роутерами, т.к. первичное подключение именно WiFiManager делает.

dontsovcmc, 2023-02-23:
> Hi, Have you included local Blynk server extra settings in this release?

Haven’t add..
But maybe you help us?
What parameters we should add to settings page?
host: string
port: integer
?

Stas15, 2023-02-23:
Honestly I’m not good in programming, I’m just end user. But I believe if you could add host,IP and port for local Blynk server in WiFi manager it will be a great job which could solve issues with this integration. Thank you in advance.

dontsovcmc, 2023-02-23:
> Just as mine pain, now I cannot connect waterius with mobile app. It connects, but dosnt send data to App, and sends only to your cloud. Im happy with it, but I liked it in my phone. I have no problems with my other projects, but to be honest, they much simpler then yours.

Do you have you own Blynk server?

Stas15, 2023-02-23:
Yes, but it is not finished, there are few problems to solve

Stas15, 2023-02-26:
Solved :)

Closed 2023-04-29.

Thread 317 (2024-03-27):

Напряжение питания с esp нужно делить на 1.024

dontsovcmc, 2024-03-27:
ADC_MODE(ADC_VCC);

float voltaje=0.00f;
voltaje = ESP.getVcc();
Serial.print(voltaje/1024.00f);
Serial.println(" V");

https://cloud.githubusercontent.com/assets/7408539/14331035/c7ffd4b4-fc43-11e5-9357-795c0b0b239b.jpg

https://github.com/esp8266/Arduino/issues/721

dontsovcmc, 2024-03-27:
1.1.3

Closed 2024-03-27.

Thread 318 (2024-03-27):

Если чип памяти от Giant (0xC4), то после deep sleep может не включиться

dontsovcmc, 2024-03-27:
Пользоватлеь Александр пишет:
та плата, на которой моя прошивка работала, оказалась как раз платой с другой ранней партии...
Проблема во флеше.
https://github.com/esp8266/Arduino/issues/6007#issuecomment-1205892703
deepSleep походу переводит и флеш в сон, а выйти она из него не может. А если долго СH_PD в 0, то RTC RAM затирается и идет полная инициализация, и неважно в каком режиме была флешина.

Лучшее решение проблемы - не использовать в твоем случае deepSleep.

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
```
>esptool.exe --port COM17
flash_idesptool.py v3.1
Serial port COM17
Connecting....
Detecting chip type...
ESP8266Chip is ESP8266EX
Features:
WiFiCrystal is 26MHz
MAC: 2c:f4:32:1b:e8:c7Uploading stub...
Running stub...Stub running...
Manufacturer: c4
Device: 6014
Detected flash size: 1MBHard resetting via RTS pin...
```

dontsovcmc, 2024-03-27:
1.1.3
Добавил вызов deepSleepIntant только если не C4 производитель памяти

Closed 2024-05-16.

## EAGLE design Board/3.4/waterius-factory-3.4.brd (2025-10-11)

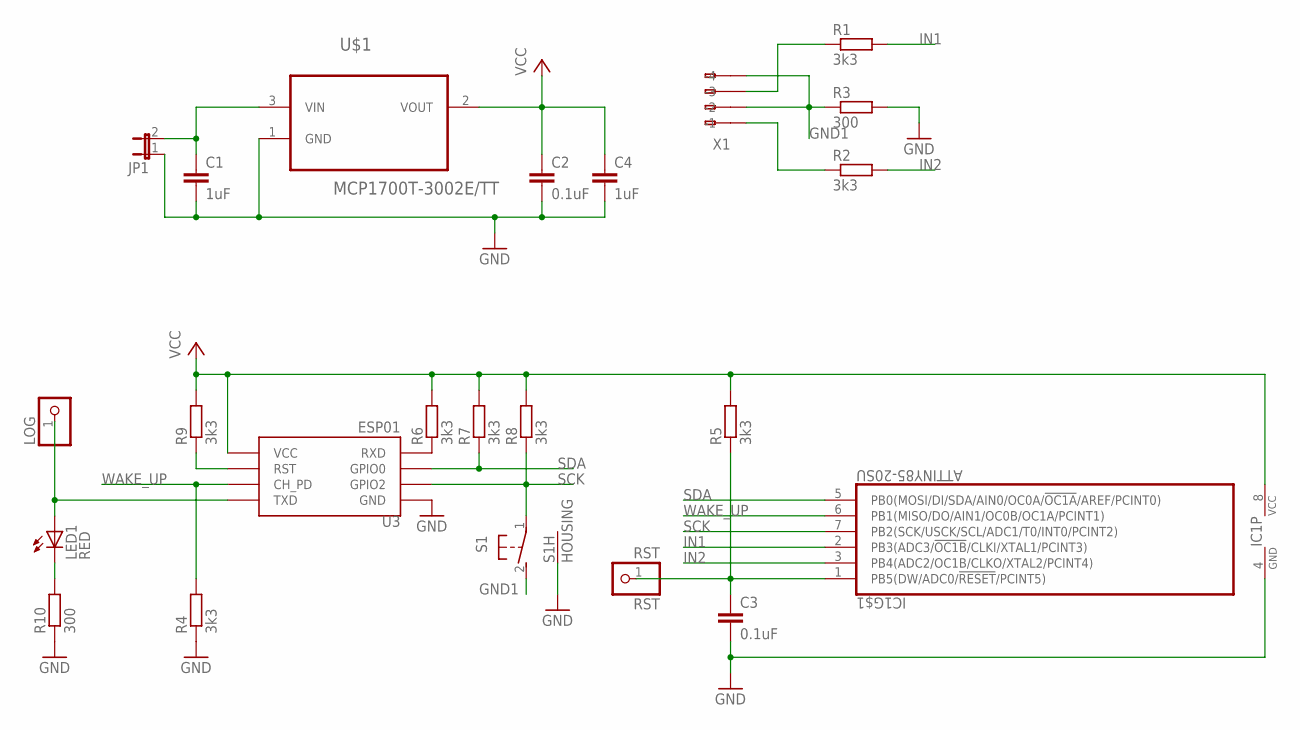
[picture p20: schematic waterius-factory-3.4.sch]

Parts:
C1, C4: 1uF; C0805
C2, C3: 0.1uF; C0805
IC1: ATTINY85-20SU; 8S2
JP1: JP1E; JP1
LED1: RED; LED3MM
LOG: PINHD-1X1; 1X01
R1, R2, R4, R5, R6, R7, R8, R9: 3k3; R0805
R3, R10: 300; R0805
RST: RST; 1X01
S1: 31-XX; B3F-31XX
U3: ESP01
U$1: MCP1700T-3002E/TT; SOT95P237X112-3N
X1: 233-104

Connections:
+3V: C2.1, C4.1, IC1.8 (VCC), R5.2, R6.2, R7.2, R8.2, R9.2, U3.VCC, U$1.2 (VOUT)
GND: C1.2, C2.2, C3.2, C4.2, IC1.4 (GND), JP1.1, R3.2, R4.1, R10.1, S1.3 (HOUSING), S1.4 (HOUSING), U3.GND, U$1.1 (GND)
GND1: R3.1, S1.2 (S), X1.A2 (-2), X1.A4 (-4)
IN1: IC1.2 (PB3(ADC3/!OC1B!/CLKI/XTAL1/PCINT3)), R1.2
IN2: IC1.3 (PB4(ADC2/OC1B/CLKO/XTAL2/PCINT4)), R2.2
unnamed: R6.1, U3.RX (RXD)
unnamed: R9.1, U3.RST
unnamed: LED1.A, LOG.1, U3.TX (TXD)
unnamed: LED1.K (C), R10.2
unnamed: R1.1, X1.A3 (-3)
unnamed: R2.1, X1.A1 (-1)
PRG_RST: C3.1, IC1.1 (PB5(DW/ADC0/!RESET!/PCINT5)), R5.1, RST.1
SCK: IC1.7 (PB2(SCK/USCK/SCL/ADC1/T0/INT0/PCINT2)), R8.1, S1.1, U3.GPIO2
SDA: IC1.5 (PB0(MOSI/DI/SDA/AIN0/OC0A/!OC1A!/AREF/P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), R7.1, U3.GPIO0
VBAT: C1.1, JP1.2, U$1.3 (VIN)
WAKE_UP: IC1.6 (PB1(MISO/DO/AIN1/OC0B/OC1A/PCINT1)), R4.2, U3.CH_PD

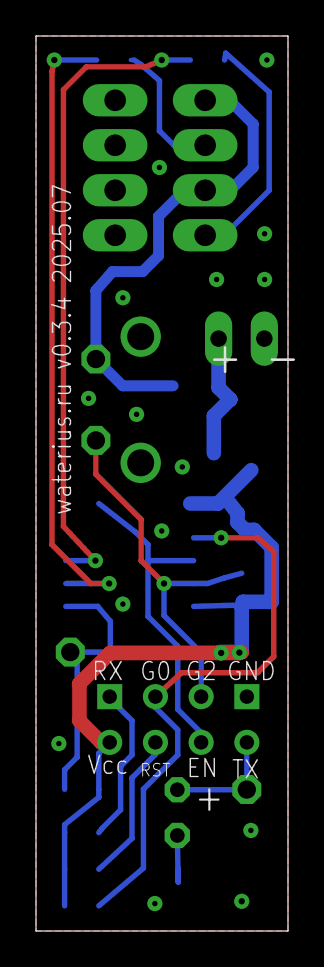
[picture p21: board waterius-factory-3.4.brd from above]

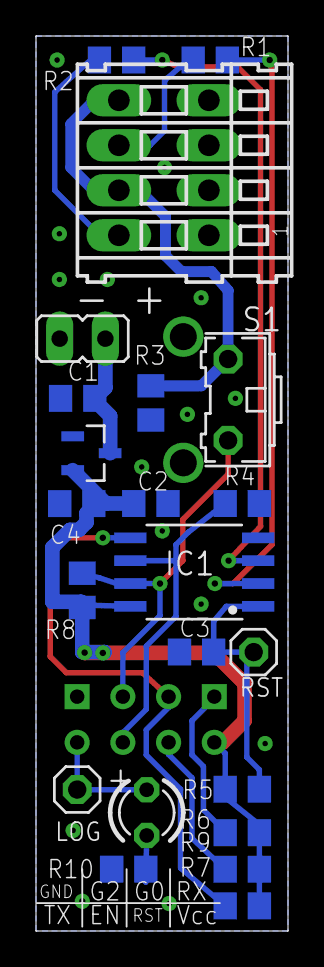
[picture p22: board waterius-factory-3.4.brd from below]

Board: 2 copper layers, 14.0 x 49.7 mm, 23 parts (23 on the bottom side), 16 nets.

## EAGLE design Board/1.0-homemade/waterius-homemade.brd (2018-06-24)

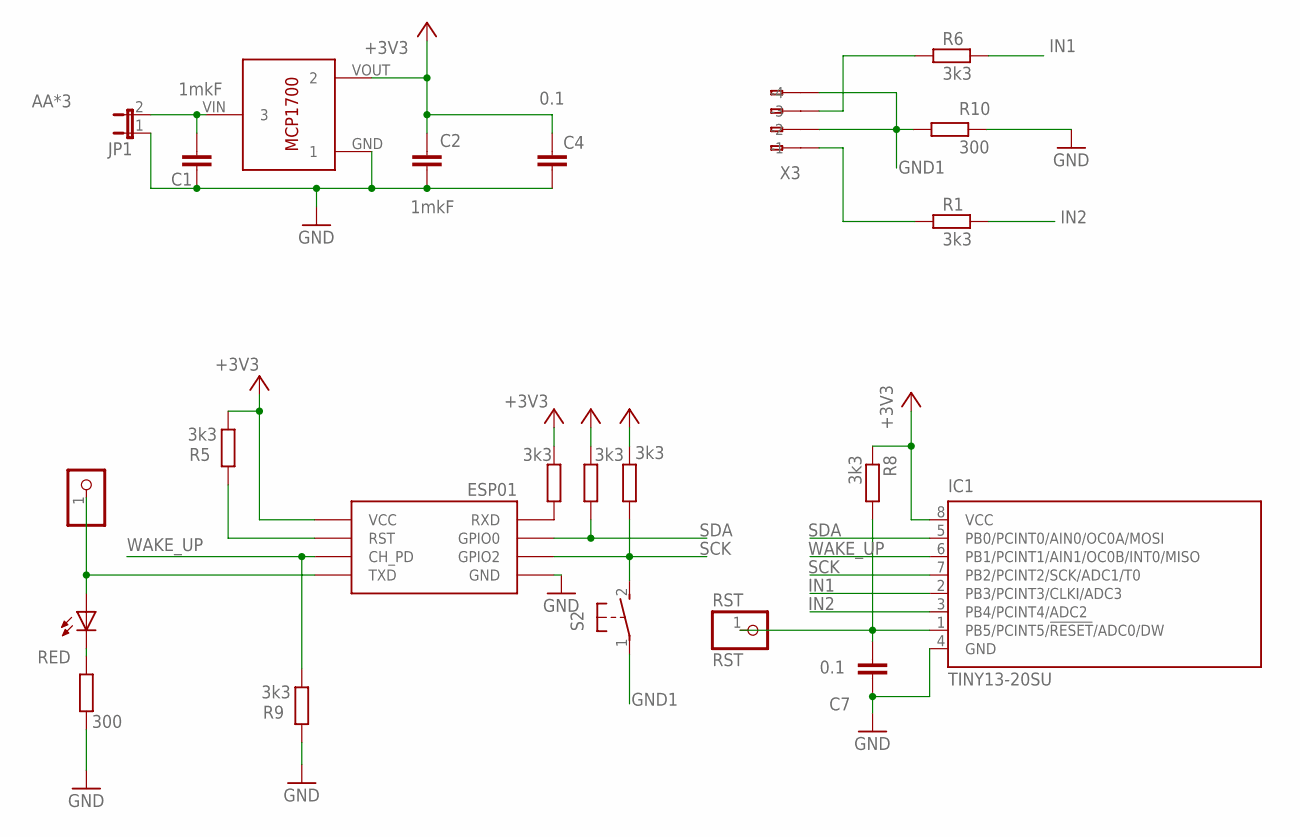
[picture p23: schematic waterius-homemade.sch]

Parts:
C1, C2: 1mkF; C0805
C4, C7: 0.1; C0805
IC1: TINY13-20SU; 8S2
JP1: JP1E; JP1
LED1: RED; LED3MM
LOG: LOG; 1X01
R1, R6: 3k3; M0805
R2, R3, R5, R7, R8, R9: 3k3; R0805
R4: 300; R0805
R10: 300; M0805
RST: RST; 1X01
S2: 31-XX; B3F-31XX
U$1: ESP01
U$2: MCP1700T-3302E/TT
X3: 233-104

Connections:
+3V3: C2.1, C4.1, IC1.8 (VCC), R2.1, R3.1, R5.1, R7.1, R8.1, U$1.VCC, U$2.VOUT (2)
AA*3: C1.1, JP1.2, U$2.VIN (3)
GND: C1.2, C2.2, C4.2, C7.1, IC1.4 (GND), JP1.1, R4.2, R9.2, R10.2, U$1.GND, U$2.GND (1)
GND1: R10.1, S2.1, X3.A2 (-2), X3.A4 (-4)
IN1: IC1.2 (PB3/PCINT3/CLKI/ADC3), R6.2
IN2: IC1.3 (PB4/PCINT4/ADC2), R1.2
unnamed: LED1.A, LOG.1, U$1.TX (TXD)
unnamed: R6.1, X3.A3 (-3)
unnamed: R1.1, X3.A1 (-1)
unnamed: LED1.K (C), R4.1
unnamed: R5.2, U$1.RST
unnamed: C7.2, IC1.1 (PB5/PCINT5/!RESET!/ADC0/DW), R8.2, RST.1
RX: R7.2, U$1.RX (RXD)
SCK: IC1.7 (PB2/PCINT2/SCK/ADC1/T0), R2.2, S2.2 (S), U$1.GPIO2
SDA: IC1.5 (PB0/PCINT0/AIN0/OC0A/MOSI), R3.2, U$1.GPIO0
WAKE_UP: IC1.6 (PB1/PCINT1/AIN1/OC0B/INT0/MISO), R9.1, U$1.CH_PD

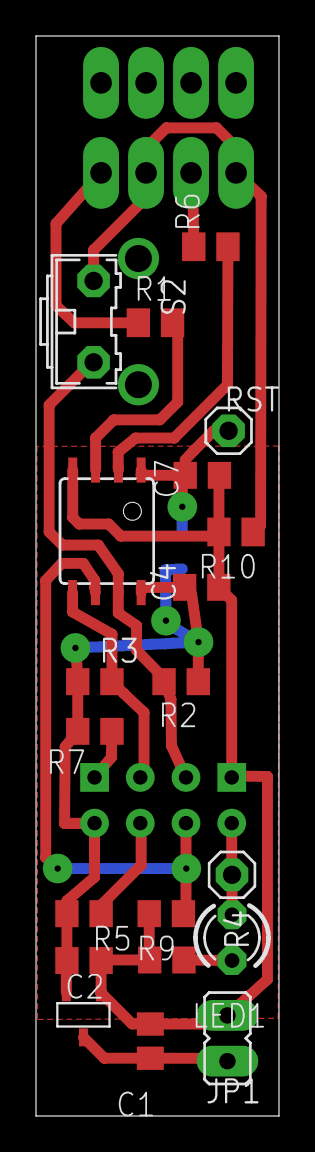
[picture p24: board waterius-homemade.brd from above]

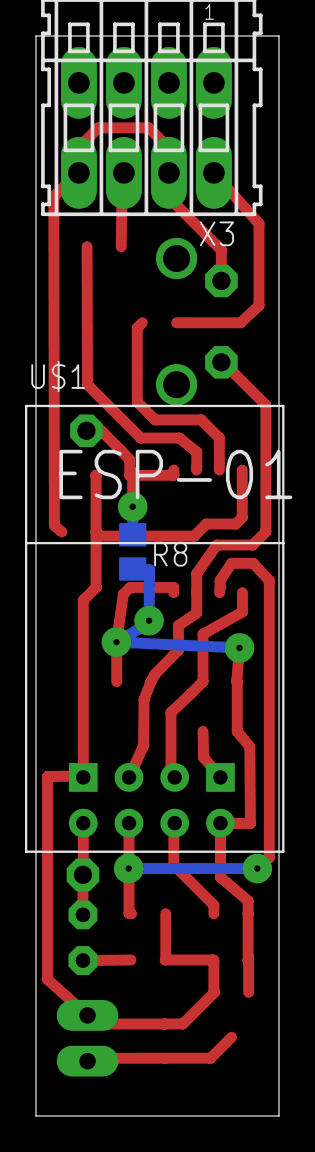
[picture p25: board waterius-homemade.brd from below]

Board: 2 copper layers, 13.5 x 60.0 mm, 23 parts (3 on the bottom side), 16 nets.

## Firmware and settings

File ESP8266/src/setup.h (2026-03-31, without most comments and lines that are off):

#define _WATERIUS_SETUP_h
#include <Arduino.h>
#ifndef FIRMWARE_VERSION
#error "Please define environment variable FIRMWARE_VERSION=x.x.x"
#endif
#define BRAND_NAME "waterius"
#define WATERIUS_DEFAULT_DOMAIN "https://cloud.waterius.ru"
#define ESP_CONNECT_TIMEOUT 10000UL // Время подключения к точке доступа, ms
#define SERVER_TIMEOUT 12000UL // Время ответа сервера, ms
#define I2C_SLAVE_ADDR 10 // i2c адрес Attiny85
#define VER_8 8
#define VER_9 9
#define VER_10 10
#define VER_11 11
#define VER_12 12
#define CURRENT_VERSION VER_11
#define EMAIL_LEN 40
#define WATERIUS_KEY_LEN 34
#define HOST_LEN 64
#define COMPANY_LEN 20
#define PLACE_LEN 40
#define BLYNK_RESERVED 38
#define MQTT_LOGIN_LEN 32
#define MQTT_PASSWORD_LEN 66 //ansible образ home assistant генерирует пароль длиной 64
#define MQTT_TOPIC_LEN 64
#define MQTT_DEFAULT_TOPIC_PREFIX BRAND_NAME // Проверка: mosquitto_sub -h test.mosquitto.org -t "waterius/#" -v
#define MQTT_DEFAULT_PORT 1883
#define DISCOVERY_TOPIC "homeassistant"
#define MQTT_AUTO_DISCOVERY true // если true то публикуется автодискавери топик для Home Assistant
#define MQTT_FORCE_UPDATE true // Сенсор в HA будет обновляться даже если значение не обновилось
#define CHANNEL_NUM 2
#define HARDWARE_VERSION "1.0.0"
#define MANUFACTURER "Waterius"
#define JSON_SMALL_STATIC_MSG_BUFFER 256
#define ROUTER_MAC_LENGTH 8
#define MAC_LENGTH 18
#define IP_LENGTH 16
#define SERIAL_LEN 16
#define DEFAULT_WAKEUP_PERIOD_MIN 1440
#define AUTO_IMPULSE_FACTOR 3
#define AS_COLD_CHANNEL 7
#define DEF_FALLBACK_DNS "8.8.8.8"
#define WIFI_CONNECT_ATTEMPTS 2
#define WIFI_SSID_LEN 32
#define WIFI_PWD_LEN 64
#define DEFAULT_GATEWAY "192.168.0.1"
#define DEFAULT_MASK "255.255.255.0"
#define DEFAULT_NTP_SERVER "ru.pool.ntp.org"
#define WATERIUS_MODEL_1 0
#define WATERIUS_MODEL_2 2
#define SETUP_MODE 1
#define TRANSMIT_MODE 2
#define MANUAL_TRANSMIT_MODE 3
#define CH0_LED_PIN 12
#define CH1_LED_PIN 13
#define BUTTON_STATE_PIN 14
#if WATERIUS_MODEL == WATERIUS_MODEL_1
#define GREEN_LED_PIN 1
#define ERROR_RED_LED_PIN 1
#endif
#if WATERIUS_MODEL == WATERIUS_MODEL_2
#define GREEN_LED_PIN 19
#define ERROR_RED_LED_PIN CH0_LED_PIN
#endif
enum OtaError
{
    OTA_ERR_NONE = 0,
    OTA_ERR_PARSE = 1,
    OTA_ERR_FS_UPDATE = 2,
    OTA_ERR_FW_UPDATE = 3,
    OTA_ERR_LOW_BATTERY = 4
};
enum InputColor
{
    INPUT0_RED = 0,  // 0 - Красный вход, ГВС
    INPUT1_BLUE = 1  // 1 - Синий вход, ХВС
};
enum CounterType
{
    NAMUR = 0,
    DISCRETE = 1,
    ELECTRONIC = 2,
    HALL = 3,
    NONE = 0xFF   // 255
};
enum CounterName
{
    WATER_COLD = 0,
    WATER_HOT = 1,
    ELECTRO = 2,
    GAS = 3,
    HEAT_GCAL = 4,
    PORTABLE_WATER = 5,
    OTHER = 6,
    HEAT_KWT = 7
};
enum DataType
{
    COLD_WATER = 0,
    HOT_WATER = 1,
    ELECTRICITY = 2,
    GAS_DATA = 3,
    HEATING_GCAL = 4,
    ELECTRICITY_DAY = 5,
    ELECTRICITY_NIGHT = 6,
    ELECTRICITY_PEAK = 7,
    ELECTRICITY_HALF_PEAK = 8,
    POTABLE_WATER = 9,
    OTHER_TYPE = 10,
    ELECTRICITY_TOTAL = 11,  // not used here
    HEATING_KWT = 12
};
struct CalculatedData
{
    float channel0 = 0.0;
    float channel1 = 0.0;
    uint32_t delta0 = 0;
    uint32_t delta1 = 0;
};
struct Settings
{
    uint8_t version = CURRENT_VERSION; // Версия конфигурации
    uint8_t reserved0 = 0;
    char waterius_host[HOST_LEN] = {0};
    char waterius_key[WATERIUS_KEY_LEN] = {0};
    char waterius_email[EMAIL_LEN] = {0};
    char company[COMPANY_LEN] = {0};
    char place[PLACE_LEN] = {0};
    char reserved_blynk[BLYNK_RESERVED] = {0};
    char http_url[HOST_LEN] = {0};
    char mqtt_host[HOST_LEN] = {0};
    uint16_t mqtt_port = MQTT_DEFAULT_PORT;
    char mqtt_login[MQTT_LOGIN_LEN] = {0};
    char mqtt_password[MQTT_PASSWORD_LEN] = {0};
    char mqtt_topic[MQTT_TOPIC_LEN] = {0};
    float channel0_start = 0.0;
    float channel1_start = 0.0;
    uint8_t wifi_connect_errors = 0;
    uint8_t wifi_connect_attempt = 0;
    char serial0[SERIAL_LEN] = {0};
    char serial1[SERIAL_LEN] = {0};
    uint32_t impulses0_start = 0;
    uint32_t impulses1_start = 0;
    uint32_t impulses0_previous = 0;
    uint32_t impulses1_previous = 0;
    uint32_t wake_time = 0;
    uint32_t setup_time = 0;
    uint32_t ip = 0;
    uint32_t gateway = 0;
    uint32_t mask = 0;
    uint16_t wakeup_per_min = DEFAULT_WAKEUP_PERIOD_MIN;
    uint16_t period_min_tuned = DEFAULT_WAKEUP_PERIOD_MIN;
    time_t last_send = 0; // Size of time_t: 8
    uint8_t mode = SETUP_MODE; // SETUP_MODE
    uint8_t setup_finished_counter = 0;
    uint8_t mqtt_auto_discovery = (uint8_t)MQTT_AUTO_DISCOVERY;
    uint8_t ntp_error_counter = 0;
    char mqtt_discovery_topic[MQTT_TOPIC_LEN] = DISCOVERY_TOPIC;
    char ntp_server[HOST_LEN] = {0};
    char wifi_ssid[WIFI_SSID_LEN] = {0};
    char wifi_password[WIFI_PWD_LEN] = {0};
    uint8_t wifi_bssid[6] = {0};
    uint8_t wifi_channel = 1;
    uint8_t wifi_phy_mode = 0;
    uint8_t counter0_name = CounterName::WATER_HOT;
    uint8_t counter1_name = CounterName::WATER_COLD;
    uint16_t factor0 = AS_COLD_CHANNEL;
    uint16_t factor1 = AUTO_IMPULSE_FACTOR;
    uint8_t waterius_on = (uint8_t) true;
    uint8_t http_on = (uint8_t) false;
    uint8_t mqtt_on = (uint8_t) false;
    uint8_t ota_error = OTA_ERR_NONE;
    uint8_t dhcp_off = (uint8_t) false;
    uint8_t mqtt_retain = (uint8_t)true;
    time_t base_time = 0; // Size of time_t: 8
    uint8_t voltage_cal = 100;
    uint8_t reserved8 = 0;
    uint8_t reserved9[74] = {0};
}; // 960 байт

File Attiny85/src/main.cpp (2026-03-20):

#include "Setup.h"

#include <avr/pgmspace.h>
#include <Wire.h>

#include "Power.h"
#include "SlaveI2C.h"
#include "Storage.h"
#include "counter.h"
#include "button.h"
#include <avr/wdt.h>
#include <avr/sleep.h>
#include <avr/power.h>

// Для логирования раскомментируйте LOG_ON в Setup.h
#if defined(LOG_ON)
TinyDebugSerial mySerial;
#endif


/*
Версии прошивок

33 - 2025.09.29 - dontsov
    1. 250мс замыкание + 750мс размыкание = импульс
	2. ADC замыкания теперь 150 ~2кОм. Был 170 ~3.5кОм 
	LOG_ON=6820 bytes

32 - 2023.11.17 - abrant
	1. Добавлен тип входа "Датчик Холла", он требует питания, которое подается вместо второго канала.
	2. Реализовано переключение типов входа.

31 - 2023.10.13 - abrant
	1. После смены типа входа теперь не нужна перезагрузка attiny.

30 - 2023.08.01 - abrant
	1. Исправлено хранилище. 

29 - 2023.04.15 - neitri, dontsovcmc
	1. Задержка отключения ESP после команды перехода в сон

28 - 2023.04.19 - dontsovcmc
	1. Настройка типа входов

27 - 2023.03.31 - abrant
	1. Исправлен подсчет контрольной суммы. 
	2. Переписано хранилище, теперь хранятся все последние показания и при старте читается блок с верной контрольной суммой и максимальными показаниями.
	3. Добавлено хранение в EEPROM настроек и их получение по I2C

26 - 2023.03.25 - abrant
	1. Исправление потерь импульсов во время связи

25 - 2023.02.02 - abrant
	1. поддержка электронных импульсов

24 - 2022.02.22 - neitri, dontsovcmc
	1. Передача флага о том, что пробуждение по кнопке
	2. Передача количества включений режима настройки
	3. Убрано измерение напряжение, пусть его считает ESP

23 - ветка "8times" - 8 раз в секунду проверка входов

22 - 2021.07.13 - dontsovcmc
	1. переписана работа с watchdog: чип перезагрузится в случае сбоя

21 - 2021.07.01 - dontsovcmc
	1. переписана работа с watchdog
	2. поле voltage стало uint16 (2 байта от uint32 пустые для совместимости с 0.10.3)
	3. период пробуждения 15 мин, от ESP получит 1440 или другой.

20 - 2021.05.31 - dontsovcmc
	1. atmelavr@3.3.0
	2. конфигурация для attiny45

19 - 2021.04.03 - dontsovcmc
	1. WDTCR = _BV( WDCE ); в resetWatchdog

18 - 2021.04.02 - dontsovcmc
	1. WDTCR |= _BV( WDIE ); в прерывании

17 - 2021.04.01 - dontsovcmc
	1. Рефакторинг getWakeUpPeriod

16 - 2021.03.29 - dontsovcmc
	1. Отключение подтягивающих резисторов в I2C (ошибка в tinycore)
	2. Отключение ESP с задержкой 100мс после получения команды на сон (потребление ESP ниже на 7мкА).

15 - 2021.02.07 - kick2nick
	Время пробуждения ESP изменено с 1 суток (1440 мин.) на настриваемое значение
	1. Добавил период пробуждения esp.
	2. Добавил команду приема периода пробуждения по I2C.

14 - 2020.11.09 - dontsovcmc
	1. поддержка attiny84 в отдельной ветке

13 - 2020.06.17 - dontsovcmc
	1. изменил формулу crc
	2. поддержка версии на 4 счетчика (attiny84)
	   -D BUILD_WATERIUS_4C2W

12 - 2020.05.15 - dontsovcmc
	1. Добавил команду T для переключения режима пробуждения
	2. Добавил отправку аналогового уровня замыкания входа в ЕСП
	3. Исправил инициализацию входов. Кажется после перезагрузки +1 импульс
	4. Добавил crc при отправке данных

11 - 2019.10.20 - dontsovcmc
	1. Обновил алгоритм подсчёта импульсов.
	   Теперь импульс: 1 раз замыкание + 3 раза разомкнуто. Период 250мс +- 10%.

10 - 2019.09.16 - dontsovcmc
	1. Замеряем питание пока общаемся с ESP
	2. Время настройки 10 минут.

9 - 2019.05.04 - dontsovcmc
	1. USIWire заменен на Wire

8 - 2019.04.05 - dontsovcmc
	1. Добавил поддержку НАМУР. Теперь чтение состояния analogRead
	2. Добавил состояние входов.

7 - 2019.03.01 - dontsovcmc
	1. Обновил фреймворк до Platformio Atmel AVR 1.12.5
	2. Время аварийного отключения ESP 120сек.
	   Даже при отсутствии связи ESP раньше в таймауты уйдет и пришлет "спим".
*/

// Счетчики импульсов

// Waterius Classic: https://github.com/dontsovcmc/waterius
//
//                                +-\/-+
//       RESET   (D  5/A0)  PB5  1|    |8  VCC
//  *Counter1*   (D  3/A3)  PB3  2|    |7  PB2  (D  2/ A1)         SCL   *Button*
//  *Counter0*   (D  4/A2)  PB4  3|    |6  PB1  (D  1)      MISO         *Power ESP*
//                          GND  4|    |5  PB0  (D  0)      MOSI   SDA
//                                +----+
//
// https://github.com/SpenceKonde/ATTinyCore/blob/master/avr/extras/ATtiny_x5.md

static CounterB counter0(4, 2, 3); 	// Вход 1, Blynk: V0, горячая вода PB4 ADC2
static CounterB counter1(3, 3); 	// Вход 2, Blynk: V1, холодная вода (или лог) PB3 ADC3

static ESPPowerPin esp(1); // Питание на ESP

#if WATERIUS_MODEL == WATERIUS_MODEL_1
static ButtonB button(2);  // PB2 кнопка (на линии SCL)
                           // Долгое нажатие: ESP включает точку доступа с веб сервером для настройки
                           // Короткое: ESP передает показания
#endif
#if WATERIUS_MODEL == WATERIUS_MODEL_2
static ButtonB2 button(1);  // PB1 кнопка (на линии wakeup)
                           // Долгое нажатие: ESP включает точку доступа с веб сервером для настройки
                           // Короткое: ESP передает показания
#endif

// Данные - designated initializers для битовых полей
struct Header info = {
    .version = FIRMWARE_VER,
    .service = 0,
    .on_pulse0 = 0,
    .on_pulse1 = 0,
    .voltage = 0,
    .reserved2 = 0,
    .config = {0, 0, WATERIUS_MODEL, {counter0.type, counter1.type}},
    .data = {0, 0},
    .adc = {0, 0},
    .crc = 0,
    .reserved3 = 0
};

uint32_t wakeup_period;

//Кольцевой буфер для хранения показаний на случай замены питания или перезагрузки
//Кольцовой нужен для того, чтобы превысить лимит записи памяти в 100 000 раз
//Записывается каждый импульс, поэтому для 10л/импульс срок службы памяти 10 000м3
// 100к * 20 = 2 млн * 10 л / 2 счетчика = 10 000 000 л или 10 000 м3
static EEPROMStorage<Data> storage(20); // 8 byte * 20 + crc * 20
static EEPROMStorage<Config> config(2, storage.size()); // 5 byte * 2 + crc * 2

SlaveI2C slaveI2C;

volatile uint32_t 		wdt_count;
volatile CounterEvent 	event;
volatile uint8_t		storage_write_limit = 0; 

/* Вектор прерываний сторожевого таймера watchdog */
ISR(WDT_vect)
{
	++wdt_count;
	event = CounterEvent::TIME;
	if (storage_write_limit > 0)
	{
		storage_write_limit--;
	}
}

/* Вектор прерываний Pin Change */
ISR(PCINT0_vect)
{
	event = CounterEvent::FRONT;
}

// Проверяем входы на замыкание.
// Замыкание засчитывается только при повторной проверке.
inline void counting(CounterEvent ev)
{
	if (counter0.is_impuls(ev))
	{
		info.data.value0++; 				//нужен т.к. при пробуждении запрашиваем данные
		info.adc.adc0 = counter0.adc;
#ifdef LOG_ON
		LOG(F("Input0:"));
		LOG(info.data.value0);
		LOG(F("ADC0:"));
		LOG(info.adc.adc0);
#endif
		if (storage_write_limit == 0)
		{
			storage.add(info.data);
			storage_write_limit = 60*4;		// пишем в память не чаще раза в минуту
		}
	}
	info.on_pulse0 = counter0.on_time > 0;
#ifndef LOG_ON
	if (counter1.is_impuls(ev))
	{
		info.data.value1++;
		info.adc.adc1 = counter1.adc;
		if (storage_write_limit == 0)
		{
			storage.add(info.data);
			storage_write_limit = 60*4;		// пишем в память не чаще раза в минуту
		}
	}
	info.on_pulse1 = counter1.on_time > 0;
#endif

#ifdef COUNTER_DEBUG
	noInterrupts();
	if (counter0.on_time || counter1.on_time)
    	PORTB |= _BV(1);
	else
        PORTB &= ~_BV(1);
	interrupts();
#endif

	adc_disable();
	power_adc_disable();
}

void saveConfig()
{
	// записываем 2 раза чтобы полностью переписать хранилище
	config.add(info.config);
	config.add(info.config);
}

void extendWakeUpPeriod()
{
	esp.extend_wake_up();
}

//Запрос периода при инициализции. Также период может изменится после настройки.
// Настройка. Вызывается однократно при запуске.
void setup()
{
	noInterrupts();
	info.service = MCUSR; // причина перезагрузки
	MCUSR = 0;			  // без этого не работает после перезагрузки по watchdog
	wdt_disable();
	wdt_enable(WDTO_250MS);
	interrupts();

	set_sleep_mode(SLEEP_MODE_PWR_DOWN);

	if (config.init())
	{
		// Конфигурация найдена
		config.get(info.config);
		info.config.resets++;
		counter0.set_type((CounterType)info.config.types.type0);
		counter1.set_type((CounterType)info.config.types.type1);
	}
	else
	{
		// Конфигурации нет или повреждена
		info.config.resets = 0;
		info.config.setup_started_counter = 0;
		info.config.types.type0 = counter0.type;
		info.config.types.type1 = counter1.type;
	}
	saveConfig();

	if (storage.init())
	{
		storage.get(info.data);
	}

	wakeup_period = WAKEUP_PERIOD_DEFAULT;
	LOG_BEGIN(9600);
	LOG(F("==== START ===="));
	LOG(F("MCUSR"));
	LOG(info.service);
	LOG(F("RESET"));
	LOG(info.config.resets);
	LOG(F("EEPROM used:"));
	LOG(storage.size() + config.size());
	LOG(F("Data:"));
	LOG(info.data.value0);
	LOG(info.data.value1);
}

void counting_1ms(uint8_t &delay_loop_count)
{
	wdt_reset();
	if (delay_loop_count < 250)
	{
		delay_loop_count++;
	}
	else
	{
		// Получаем период опроса входов 250мс, как и от ватчдога
		delay_loop_count = 0;
		event = CounterEvent::TIME;
	}
	if (event != CounterEvent::NONE)
	{
		// Если получили фронт изменения сигнала или набежало время - проверяем входы
		noInterrupts();
		CounterEvent ev = event;
		event = CounterEvent::NONE;
		interrupts();
		counting(ev);
	}
	delayMicroseconds(1000);
}

// Главный цикл, повторящийся раз в сутки или при настройке вотериуса
void loop()
{
	power_all_disable(); 		// Отключаем все лишнее: ADC, Timer 0 and 1, serial interface

	GIMSK = _BV(PCIE);			// Включаем прерывания по фронту счетчиков и кнопки
	PCMSK = _BV(PCINT2);

	counter0.set_type((CounterType)info.config.types.type0);
	counter1.set_type((CounterType)info.config.types.type1);

	wdt_count = 0;
	while ((wdt_count < wakeup_period) && !button.pressed(event))
	{
		noInterrupts();
		CounterEvent ev = event;
		event = CounterEvent::NONE;
		interrupts();

		counting(ev);

		if (event == CounterEvent::NONE)
		{
			WDTCR |= _BV(WDIE);
			sleep_mode();
		}

		LOG_BEGIN(9600);
	}

	storage.add(info.data);
	power_all_enable();

	LOG_BEGIN(9600);
	LOG(F("Data:"));
	LOG(info.data.value0);
	LOG(info.data.value1);

	// Если пользователь нажал кнопку SETUP, ждем когда отпустит
	// иначе ESP запустится в режиме программирования (кнопка на i2c и 2 пине ESP)
	// Если кнопка не нажата или нажата коротко - передаем показания

	unsigned long wake_up_limit = SETUP_TIME_MSEC;  // 10 мин при настройке

	if (button.press == ButtonPressType::LONG)
	{ 
		LOG(F("SETUP pressed"));
		slaveI2C.begin(SETUP_MODE);
		info.config.setup_started_counter++;
		saveConfig();
	}
	else
	{
		if (button.press == ButtonPressType::SHORT)
		{
			LOG(F("Manual transmit wake up"));
			slaveI2C.begin(MANUAL_TRANSMIT_MODE);
		}
		else
		{
			wake_up_limit = WAIT_ESP_MSEC; // 15 секунд при передаче данных
			LOG(F("wake up for transmitting"));
			slaveI2C.begin(TRANSMIT_MODE);
		}
	}

	// Нажатие кнопки обработали и удаляем
	button.reset();
	info.voltage = readVcc(); // Прочитаем Vcc после включения ESP

	esp.power(true);

	LOG(F("ESP turn on"));

	uint8_t delay_loop_count = 0;		
	while (!slaveI2C.masterGoingToSleep() && !esp.elapsed(wake_up_limit))
	{
		counting_1ms(delay_loop_count);
	}
	uint8_t sleep_delay_ms = 20;
	while (sleep_delay_ms--) {
		counting_1ms(delay_loop_count);
	}

	slaveI2C.end(); // выключаем i2c slave.

	if (!slaveI2C.masterGoingToSleep())
	{
		LOG(F("ESP wake up fail"));
	}
	else
	{
		LOG(F("Sleep received"));
	}

	esp.power(false);
}

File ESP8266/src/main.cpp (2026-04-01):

#include <user_interface.h>
#include <umm_malloc/umm_heap_select.h>
#include <ESP8266WiFi.h>
#include "json.h"
#include "Logging.h"
#include "config.h"
#include "master_i2c.h"
#include "senders/send_data.h"
#include "ha/apply_settings.h"
#include "portal/active_point.h"
#include "voltage.h"
#include "utils.h"
#include "porting.h"
#include "sync_time.h"
#include "wifi_helpers.h"
#include "config.h"
#include "wleds.h"
#include "ota_update.h"

MasterI2C masterI2C;     // Для общения с Attiny85 по i2c
AttinyData data;         // Данные от Attiny85 при включении
AttinyData runtime_data; // Копия данных от Attiny85. Обновляются в webportal на странице детектирования и ввода значений счётчиков.
Settings sett;           // Настройки соединения и предыдущие показания из EEPROM
CalculatedData cdata;    // вычисляемые данные
ADC_MODE(ADC_VCC);
Voltage voltage;


/*
Выполняется однократно при включении
*/
void setup()
{
    setup_leds();

    LOG_BEGIN(115200); // Включаем логгирование на пине TX, 115200 8N1
    LOG_INFO(F("Waterius\n========\n"));
    LOG_INFO(F("Build: ") << __DATE__ << F(" ") << __TIME__);

    static_assert((sizeof(Settings) == 960), "sizeof Settings != 960");

    masterI2C.begin(); // Включаем i2c master

    HeapSelectIram ephemeral;
    LOG_INFO(F("IRAM free: ") << ESP.getFreeHeap() << F(" bytes"));
    {
        HeapSelectDram ephemeral;
        LOG_INFO(F("DRAM free: ") << ESP.getFreeHeap() << F(" bytes"));
    }
    LOG_INFO(F("ChipId: ") << String(getChipId(), HEX));
    LOG_INFO(F("FlashChipId: ") << String(ESP.getFlashChipId(), HEX));
}

void loop()
{
    uint8_t mode = TRANSMIT_MODE; // TRANSMIT_MODE;
    bool config_loaded = false;

    // спрашиваем у Attiny85 повод пробуждения и данные true)
    if (masterI2C.getMode(mode) && masterI2C.getAttinyData(data))
    {
        runtime_data = data;

        voltage.update();
#if WATERIUS_MODEL == WATERIUS_MODEL_2
        if (mode == MANUAL_TRANSMIT_MODE)
        {
            mode = wait_button_release();
        }
        if (mode == SETUP_MODE) // Если режим "Настройка"
        {
            masterI2C.setSetupMode(); 
        }
#endif
        // Загружаем конфигурацию из EEPROM
        config_loaded = load_config(sett);
        sett.mode = mode;
        LOG_INFO(F("Startup mode: ") << mode);

        // Вычисляем текущие показания
        calculate_values(sett, data, cdata);

        if (mode == SETUP_MODE)
        {
            LOG_INFO(F("Entering in setup mode..."));
            // Режим настройки - запускаем точку доступа на 192.168.4.1
            // Запускаем точку доступа с вебсервером
            start_active_point(sett, cdata);

            store_config(sett);

            wifi_shutdown();

            LOG_INFO(F("Set mode MANUAL_TRANSMIT to attiny"));
            masterI2C.setTransmitMode(); // Режим "Передача"

            LOG_INFO(F("Restart ESP"));
            LOG_END();

            LOG_INFO(F("Finish setup mode..."));
            ESP.restart();

            return; // сюда не должно дойти никогда
        }

        if (config_loaded)
        {
            if (wifi_connect(sett))
            {
                voltage.update();
                log_system_info();

                JsonDocument json_data;
                JsonDocument json_settings_received;

                // Подключаемся и подписываемся на мктт
#ifndef MQTT_DISABLED
                if (is_mqtt(sett))
                {
                    connect_and_subscribe_mqtt(sett, json_settings_received);
                }
#endif

                // устанавливать время только при использовани хттпс или мктт
                if (is_mqtt(sett) || is_https(sett.waterius_host) || is_https(sett.http_url))
                {
                    if (!sync_ntp_time(sett)) {
                        sett.ntp_error_counter++;
                    }
                }

                LOG_INFO(F("Free memory: ") << ESP.getFreeHeap());

                send_data(sett, data, cdata, json_data, json_settings_received);

                if (sett.ota_error != OTA_ERR_NONE)
                {
                    sett.ota_error = OTA_ERR_NONE;
                    store_config(sett);
                }

                if (settings_received(json_settings_received))
                {
                    apply_settings(json_settings_received, sett, data, cdata);
                    send_data(sett, data, cdata, json_data, json_settings_received);
                }

#if WATERIUS_MODEL == WATERIUS_MODEL_2
                if (has_ota(json_settings_received))
                {
                    perform_ota_update(json_settings_received[F("ota")].as<JsonObject>(), masterI2C, sett, voltage);
                }
#endif

                // Все уже отправили,  wifi не нужен - выключаем
                wifi_shutdown();

                update_config(sett, data, cdata);

                if (!masterI2C.setWakeUpPeriod(sett.period_min_tuned))
                {
                    LOG_ERROR(F("Wakeup period wasn't set"));
                }
            }
            store_config(sett);  // т.к. сохраняем число ошибок подключения
        }
    }

    if (!config_loaded)
    {
        blynk_error(ErrorBlynks::ERROR_CONFIG);
    }

    LOG_INFO(F("Going to sleep"));
    LOG_END();

    uint8_t vendor_id = ESP.getFlashChipVendorId();

    masterI2C.setSleep(); // через 20мс attiny отключит EN

    release_leds();

#if WATERIUS_MODEL == WATERIUS_MODEL_1
    // { 0xC4, "Giantec Semiconductor, Inc." }, https://github.com/elitak/freeipmi/blob/master/libfreeipmi/spec/ipmi-jedec-manufacturer-identification-code-spec.c
    if (vendor_id != 0xC4)
    {
        // Спим до следущего включения EN. (выключили Instant не ждет 92мс)
        ESP.deepSleepInstant(0, RF_DEFAULT);
    }
#endif
#if WATERIUS_MODEL == WATERIUS_MODEL_2
    ESP.deepSleepInstant(1000000, RF_DEFAULT);
#endif

    while(true) yield();
}

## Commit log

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2018-02-12 new device_info works, deep_sleep corrected
    [MasterI2C.cpp, SlaveI2C.cpp, main.cpp]
2018-02-14 wemos memory ok, (i2c doesn't work)
    [main.cpp, setup.h]
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2018-02-24 - ATTINY send when turn on
    - ESP wifi correct
    - Server works
    [main.cpp, setup.h]
2018-03-11 add scheme
    [esp-01_lite2.brd, esp-01_lite2.sch]
2018-03-20 add password
    [esp-01_lite2.brd, esp-01_lite2.sch]
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2018-03-28 add board and scheme for ESP-12
    [esp-12.brd, esp-12.sch]
2018-03-28 emoji, new scheme
    [esp-01_lite2_us.brd, esp-01_lite2_us.sch]
2018-04-09 attiny84 250ms check
    [esp-01_lite2.brd, esp-01_lite2.sch]
2018-04-10 LED works, server ok, ESP 24h
    [esp-01_lite2.brd, esp-01_lite2.sch, esp-01_lite2_us.brd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]
2018-04-10 new board
    [esp-01_lite2.brd, esp-01_lite2.sch]
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2018-04-26 correct error, 32ms, debug
    [Power.cpp, SlaveI2C.cpp, main.cpp]
2018-04-26 correct error. release. 250ms
    [SlaveI2C.cpp, main.cpp]
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2018-05-18 board for one_button
    [esp-01_lite2.brd, esp-01_lite2.sch]
2018-05-18 clear buffer if send error
    [main.cpp]
2018-05-19 add device=2 parser, correct unit tests
2018-05-19 photo & scheme
    [esp-12.brd, esp-12.sch]
2018-05-19 power and photo
    [power.xlsx]
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2018-06-13 update board
    [esp-01_lite2.brd, esp-01_lite2.sch]
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2018-06-23 v0.4 remove capacitor
    [esp-01_lite2.brd, esp-01_lite2.sch]
2018-06-24 инструкция, плата для производства
    [waterius-factory.brd, waterius-factory.sch, waterius-homemade.brd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]
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2018-07-31 attiny85 long, short press button, not tested
    [Power.cpp, main.cpp]
2018-07-31 1. Добавлен U3 наверх и низ платы
    2. подписан каждый пин ESP
    3. Позиционные обозначения многие переставлены
    4. В схеме изменён компонент на MCP1700-3002
    [waterius-factory.brd, waterius-factory.sch]
2018-07-31 board: C2, R4 correct
    [waterius-factory.brd, waterius-factory.sch]
2018-08-03 issuu 26:
    safe logging,
    strncpy correct,
    email_title, email_template works
    [main.cpp]
2018-08-04 exception when Setup correct issuu #21
    [main.cpp, master_i2c.cpp, master_i2c.h]
2018-08-04 revert attiny85, cause untested
    [Power.cpp, main.cpp]
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2018-09-20 attiny85 long, short press button, not tested
    # Conflicts:
    # ESP8266/platformio.ini
    [Power.cpp, main.cpp]
2018-09-21 attiny85 long, short button #18, add send JSON to server #33
    [Power.cpp, main.cpp, setup.h]
2018-09-21 remove disable watchdog, it reboots ESP if pause 6 sec
    [main.cpp]
2018-09-22 Waterius 0.5 add reset counter #25
    [main.cpp, master_i2c.cpp, master_i2c.h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]
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2018-11-06 Поправил фьюзы
    Теперь они как в тексте хексовые и ПИШУТСЯ, а не верифицируются...
2019-02-16 new board, not tested
    [waterius-factory-2.0.brd, waterius-factory-2.0.sch]
2019-03-01 correct Board 2.0
    [waterius-factory-2.0.brd, waterius-factory-2.0.sch]
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2019-03-17 skip blynk if empty key
    [setup.h]
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2019-04-11 correct button
2019-05-03 Исправил дублирование параметра reset в MQTT, оптимизация создания defaultTopic
2019-05-03 MQTT cosmetic, change default broker
    [setup.h]
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2019-09-04 board correct, https://github.com/dontsovcmc/waterius/issues/87
    remove 47k untested resister
    [waterius-factory-2.0.brd, waterius-factory-2.0.sch]
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2019-11-14 replace mcp1700 file
    [waterius-factory-2.0.brd, waterius-factory-2.0.sch]
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2019-12-21 0.9.9 #113 ssid correct
    [main.cpp, setup.h]
2019-12-21 attiny85 on sch
    [waterius-factory-2.0.brd, waterius-factory-2.0.sch]
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2020-04-04 correct board
    [waterius-factory-2.0.brd]
2020-04-04 wago board
    [waterius-factory-2.0wago.brd, waterius-factory-2.0wago.sch]
2020-04-05 wago board update
    [waterius-factory-2.0wago.brd, waterius-factory-2.0wago.sch]
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2020-06-25 correct voltage for classic
    [main.cpp]
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2020-08-03 Update README.md
    Исправил пару ссылок.
2020-10-12 board v.0.3
    [waterius-factory-3.0.brd, waterius-factory-3.0.sch]
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2021-02-12 reverse chipid in wifi
    [master_i2c.cpp]
2021-02-15 refactor combobox, not work
    [main.cpp, setup.h]
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2021-02-24 0.10.1 save period bug
    [main.cpp, setup.h]
2021-03-15 Rewired power
    [waterius-factory-3.1.brd, waterius-factory-3.1.sch]
2021-03-16 New attiny package
    [waterius-factory-3.1.brd, waterius-factory-3.1.sch]
2021-03-16 update board, thanks @foxel
    [waterius-factory-3.1.brd, waterius-factory-3.1.sch]
2021-03-17 Grounded polygons
    [waterius-factory-3.1.brd]
2021-03-17 Connected the button housing to GND
    [waterius-factory-3.1.brd, waterius-factory-3.1.sch]
2021-03-23 new board 0.3.1
    [waterius-factory-3.1.brd, waterius-factory-3.1.sch]
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2021-04-07 Добавлена не большая инструкция по созданию сенсоров и Автоматизаций в Home Assistant
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2021-04-07 Added Home Assistant automations creating manual. Have been added two sensors to homeassistant.configuration.yaml. Updated README (added link to manual)
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2021-11-12 Added ADC delay for reliable read of high-impedance inputs. dontsovcmc/waterius/issues/200
    [counter.h]
2021-11-12 Добавлено ожидание начала импульса. То есть импульс считается начатым, если он длится как минимум два такта считывания. Также начальное состояния при включении питания (или при reset от watchdog'а) и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
    [counter.h, main.cpp]
2021-11-16 Increase close counter to 2 and open counter to 24. Fix measurement delay during wakeup.
    [SlaveI2C.cpp, counter.h, main.cpp]
2021-12-11 Update configs to set unique id's
    Provides controls for placing sensors in dashboard
2022-01-19 Revert "Increase close counter to 2 and open counter to 24. Fix measurement delay during wakeup."
    This reverts commit 87af721e38281520a4db015eb7d64cb6f92266fd.
    [SlaveI2C.cpp, counter.h, main.cpp]
2022-01-19 Revert "Добавлено ожидание начала импульса. То есть импульс считается начатым, если он длится как минимум два такта считывания. Также начальное состояния при включении питания (или при reset от watch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
    This reverts commit e156fc17ea4784d2d7aaab89626d5fa88d49d65f.
    [counter.h, main.cpp]
2022-01-19 Revert "Added ADC delay for reliable read of high-impedance inputs. dontsovcmc/waterius/issues/200"
    This reverts commit ae00e319268f3c9d10228cb1804ef12c4bacc8cf.
    [counter.h]
2022-01-23 Передача количества включений режима настройки #208
    Добавлено поле settings. В esp напряжение уменьшено до 2 байт. В json добавлен атрибут settings.
2022-01-23 Флаг отправки #190 Автоматическая подстройка периода отправки #209
    Расширены варианты режима работы. При отправке по расписанию рассчитывается количество условных минут с учетом погрешности таймера.
2022-02-15 Revert "Передача количества включений режима настройки #208"
    [main.cpp, master_i2c.cpp, master_i2c.h]
2022-02-15 Revert "Флаг отправки #190 Автоматическая подстройка периода отправки #209"
    [main.cpp, master_i2c.h, setup.h]
2022-02-20 Update README.md
    Исправление опечаток
2022-02-23 Disasemble elf file
    Дизасемблирование исполняемого файла во время сборки. В папке сборки создается файл firmware.lss
2022-02-24 ограничение адаптации времени пробуждения
    Контроль версии для адаптации времени пробуждения. Работа адаптации времени если с времени пробуждения прошло более 1 минуты.
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2022-03-11 Revert "ESPAsyncWebServer"
    This reverts commit dc539d682978091a33bffcc6cc9da38c3c75f664.
    [main.cpp]
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2022-09-05 one side board
    [waterius-factory-3.2.brd, waterius-factory-3.2.sch]
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2022-12-08 Update homeassistant.configuration.yaml
    1. <unique_id> does not set the <entity_id> for the MQTT sensor. Default: <entity_id> is derived from <name>. For example: sensor <name: "Hot water in the bathroom"> is converted to <sensor.bathroom_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
    2. Last updated time format: 00h 00m 00s
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2023-01-19 В класс Voltage добавлен метод измерения % батареи, немного исправлен признак севшей батареи.
    [voltage.cpp]
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2023-01-19 Формирование одного JSON для публикации по MQTT и HTTP. АВтодискавери для HomeAssistant
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2023-01-19 Исправлена опечатка
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2023-01-20 Отправлять автодисковери только при нажатии кнопки или после установки, можно перекрыть это поведение выставив переменную компилиции ALWAYS_MQTT_AUTO_DISCOVERY в true
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2023-01-23 Добавлены опции компиляции чтобы можно было отключить вывод служебных сообщейни в порт в промышленной прошивке
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2023-01-23 Добавлена возможность при компиляции отключить отправку в блинк, и уменьшить объем занимаемой памяти
2023-01-23 Исправлены функции определения протоколов, теперь не чувствительны к регистру
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2023-01-23 Строик для автодискавреи топиков вынесены во флэш и добавлены в отдельный модуль
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2023-01-23 Закончена доработка создания автодискавери топиков Дополнительные сведения по каналам (ХВ,ГВ) оформлены как атрибуты к показаниям расхода
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2023-01-24 Исправил 50 на 100 в коментах
    [voltage.cpp]
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2023-01-28 При настроенной интеграции с HA данные будут отпралвться в один топик в формате JSON
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2023-01-28 Измнеенна работа с инициализацией настроек Добавлены проверки для интеграций Мониторинг питания теперь рабоатет в фоне
2023-01-28 Структурирован файл для интеграции с HA Разбит на несколько отдельных модулей для облегчения работы с ним
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2023-02-03 Исправлены длины для пароля и логина
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2023-02-06 Исправлена опечатка при проверке состояния чекбокса
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2023-02-06 Исправлены пути
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2023-02-28 Исправлена обработка параметра NTP сервер
2023-02-28 Fix не использовался пользовательский ntp сервер
2023-02-28 error with manual ntp server
    [main.cpp]
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2023-03-01 Fix ~Portal() изменено уничтожение объектов.
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2023-03-05 fix JsonConstructor проверка указателя на нулл
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2023-03-06 Fix проверка указателя на null
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2023-03-10 Fix Утечка памяти в post_data обект WiFiClient
2023-03-10 Fix лишняя попытка отправки http.
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2023-03-16 Fix загружается значение в checkedbox
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2023-03-17 loops attempts correct add firmware version to log
    [setup.h, voltage.cpp]
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2023-03-24 Исправление потерь импульсов во время связи
    Исправление потерь коротких импульсов от электронных счетчиков во время связи по I2C
    [main.cpp]
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2023-03-28 Правки в хранилище показаний
    Исправлен подсчет контрольной суммы. Переписано хранилище, теперь хранятся все последние показания и при старте читается блок с верной контрольной суммой и максимальными показаниями.
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2023-04-21 delay 20ms before sleep, correct CRC in ESP
    [main.cpp, master_i2c.cpp]
2023-08-01 Исправлено хранилище показаний в EEPROM
    [main.cpp]
2023-08-04 move files
    [waterius-factory-2.0.brd, waterius-factory-2.0.sch, waterius-factory-2.0wago.brd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]
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2023-08-09 device_class correct
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2023-10-13 Исправление смены типа входов
    [main.cpp]
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2023-11-13 captive portal works, correct wifi_phy_mode
    [main.cpp]
2023-11-16 correcting wifi connect UX
    [master_i2c.cpp]
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2023-11-25 1.0.4 correct setup type, reset.html, wifi_list.html
    [setup.h]
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2024-11-03 1.1.6 correct web page errors
    [json.cpp, master_i2c.cpp, setup.h]
2025-07-13 1.1.12 auto factor, skip detect ux
    [setup.h]
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2025-10-11 board less 1.5mm 50mm
    [waterius-factory-3.4.brd, waterius-factory-3.4.sch]
2026-02-13 Revert "feat(ESP8266): Remote config, mDNS discovery, NTP weekly sync, WOC mode"
    This reverts commit f9cbd59393a5af262529d020eeeb5ca349d20bd9.
    [json.cpp, main.cpp]
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2026-02-23 try to correct exception
    [master_i2c.cpp, master_i2c.h]
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2026-03-04 add OTA firmware+filesystem update for Waterius-2
    - ota_update.cpp: download manifest, update FS then firmware via ESP8266httpUpdate
    - battery check before OTA (dual: voltage + percentage), USB power detection
    - ota_error codes (1-7) saved to EEPROM and reported in JSON
    - block-scoped WiFiClientSecure to free ~15KB between manifest and firmware download
    - main.cpp: trigger OTA when server responds with update_ota field
    - doc/ota.md: full documentation (flow, timings, server setup, error codes)
    - scripts/build_and_deploy.sh: build OTA binaries with version argument
    - remove plan/ (completed), reorganize to scripts/ and doc/
    [json.cpp, main.cpp, ota_update.cpp]
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
